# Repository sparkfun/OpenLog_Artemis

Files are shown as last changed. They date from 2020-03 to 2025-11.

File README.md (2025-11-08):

SparkFun OpenLog Artemis
===========================================================

<table class="table table-hover table-striped table-bordered">
  <tr align="center">
   <td></td>
   <td></td>
  </tr>
  <tr align="center">
    <td><a href="https://www.sparkfun.com/products/16832">SparkFun OpenLog Artemis (DEV-16832)</a></td>
    <td><a href="https://www.sparkfun.com/products/15846">SparkX OpenLog Artemis (SPX-15846)</a></td>
  </tr>
</table>

The OpenLog Artemis is an open source datalogger that comes preprogrammed to automatically log IMU, GPS, serial data, and various pressure, humidity, and distance sensors. All without writing a single line of code! OLA automatically detects, configures, and logs Qwiic sensors. OLA is designed for users who just need to capture a bunch of data to a CSV and get back to their larger project.

Included on every OpenLog Artemis is an IMU for built-in logging of triple axis accelerometer, gyro, and magnetometer. Whereas the original [9DOF Razor](https://www.sparkfun.com/products/14001) used the old MPU-9250, the OpenLog Artemis uses the latest [ICM-20948](https://www.sparkfun.com/products/15335) capable of nearly 1kHz logging of all 9 axis. We then took over a decade of experience with the original [OpenLog](https://www.sparkfun.com/products/13712) and took it much farther. Simply power up OpenLog Artemis and all incoming serial data is automatically recorded to a log file. Baud rates up to 921600bps are supported! Additionally, based on feedback from users we've added an onboard RTC so that all data can be time stamped.

OpenLog Artemis is highly configurable over an easy to use serial interface. Simply plug in a USB C cable and open a terminal at 115200kbps. The logging output is automatically streamed to both the terminal and the microSD. Pressing any key will open the configuration menu.

The OpenLog Artemis automatically scans, detects, configures, and logs various Qwiic sensors plugged into the board (no soldering required!). Currently, auto-detection is supported on the following Qwiic products:

* Any u-blox GPS Modules (Lat/Long, Altitude, Velocity, SIV, Time, Date) such as:
  * [ZED-F9P](https://www.sparkfun.com/products/15136) 1cm High Precision GPS
  * [NEO-M8P-2](https://www.sparkfun.com/products/15005) 2.5cm High Precision GPS
  * [SAM-M8Q](https://www.sparkfun.com/products/15210) 1.5m 72 Channel GPS
  * [ZOE-M8Q](https://www.sparkfun.com/products/15193) 1.5m Compact GPS
  * [NEO-M9N](https://www.sparkfun.com/products/15712) 1.5m GPS
  * [MAX-M10S](https://www.sparkfun.com/products/18037) 1.5m Ultra-Low Power GPS
* [MCP9600 Thermocouple Amplifier](https://www.sparkfun.com/products/16294)
* [NAU7802 Load Cell Amplifier](https://www.sparkfun.com/products/15242)
* [LPS25HB Barometric Pressure Sensor](https://www.sparkfun.com/products/14767)
* [BME280 Humidity and Barometric Pressure Sensor](https://www.sparkfun.com/products/15440)
* [MS5637 Barometric Pressure Sensor](https://www.sparkfun.com/products/14688)
* [MS5837 Depth / Pressure Sensor](https://www.sparkfun.com/products/17709)
* [SDP3X Differential Pressure Sensor](https://www.sparkfun.com/products/17874)
* [MS8607 Pressure Humidity Temperature Sensor](https://www.sparkfun.com/products/16298)
* [MPR0025PA MicroPressure Sensor](https://www.sparkfun.com/products/16476)
* [TMP102 Temperature Sensor] (https://www.sparkfun.com/products/13314)
* [TMP117 High Precision Temperature Sensor](https://www.sparkfun.com/products/15805)
* [AHT20 Humidity and Temperature Sensor](https://www.sparkfun.com/products/16618)
* [SHTC3 Humidity and Temperature Sensor](https://www.sparkfun.com/products/16467)
* [CCS811 Air Quality Sensor](https://www.sparkfun.com/products/14348)
* [SGP30 Air Quality Sensor](https://www.sparkfun.com/products/16531)
* [SGP40 Air Quality Sensor](https://www.sparkfun.com/products/17729)
* [SCD30 CO<sub>2</sub> and Air Quality Sensor](https://www.sparkfun.com/products/15112)
* [SN-GCJA5 Particle Sensor](https://www.sparkfun.com/products/17123)
* [VEML6075 UV Sensor](https://www.sparkfun.com/products/15089)
* [VCNL4040 Proximity Sensor](https://www.sparkfun.com/products/15177)
* [VL53L1X LIDAR Distance Sensor](https://www.sparkfun.com/products/14722)
* [ADS122C04 ADC PT100 Sensor](https://www.sparkfun.com/products/16770)
* [Qwiic Mux](https://www.sparkfun.com/products/16784) allowing for the chaining of up to 64 unique buses!
* [Pulse Oximeter and Heart Rate Sensor](https://www.sparkfun.com/products/15219) (requires exclusive use of pins 32 and 11)
* [ISM330DHCX IMU](https://www.sparkfun.com/products/19764)
* [MMC5983MA Magnetometer](https://www.sparkfun.com/products/19921)
* [KX134 Accelerometer](https://www.sparkfun.com/products/17589)
* [ADS1015 ADC](https://www.sparkfun.com/products/15334)
* [LPS28DFW Barometer](https://www.sparkfun.com/products/21221)
* [VEML7700 Ambient Light Sensor](https://www.sparkfun.com/products/18981)
* [TMP102 Temperature Sensor](https://www.sparkfun.com/sparkfun-digital-temperature-sensor-tmp102-qwiic.html)

Very low power logging is supported. OpenLog Artemis can be configured to take readings at 500 times a second, or as slow as 1 reading every 24 hours. You choose! When there is more than 2 seconds between readings OLA will automatically power down itself and the sensors on the bus resulting in a sleep current of approximately 18uA. This means a normal [2Ah battery](https://www.sparkfun.com/products/13855) will enable logging for more than 4,000 days! OpenLog Artemis has built-in LiPo charging set at 450mA/hr.

New features are constantly being added so we’ve released an easy to use firmware upgrade tool. No need to install Arduino or a bunch of libraries, simply open the [Artemis Firmware Upload GUI](https://github.com/sparkfun/Artemis-Firmware-Upload-GUI), load the latest OLA firmware, and add features to OpenLog Artemis as they come out! Full instructions are available in [UPGRADE.md](UPGRADE.md).

The OLA can be tailored to many different applications and we will be releasing custom versions of the firmware for those too:

* [Latest OLA firmware](https://github.com/sparkfun/OpenLog_Artemis/tree/main/Binaries)
* [Geophone Logger firmware](https://github.com/sparkfun/OpenLog_Artemis_Geophone_Logger) for logging seismic activity
* [GNSS Logger](https://github.com/sparkfun/OpenLog_Artemis_GNSS_Logger) for advanced data logging with the u-blox F9 and M9 GNSS modules including support for RAWX and RELPOSNED

Repository Contents
-------------------

* **/Binaries** - The binary files for the different versions of the OLA firmware.
* **/Firmware** - The main sketch that runs OpenLog Artemis as well as a variety of sketches to test various sensor interfaces and power saving states.
* **/Hardware** - Eagle files.

Documentation
--------------

* **[Hookup Guide](https://learn.sparkfun.com/tutorials/openlog-artemis-hookup-guide)** - hookup guide for the OLA.
* **[UPGRADE.md](./UPGRADE.md)** - contains full instructions on how to upgrade the firmware on the OLA using the [Artemis Firmware Upload GUI](https://github.com/sparkfun/Artemis-Firmware-Upload-GUI).
* **[CONTRIBUTING.md](./CONTRIBUTING.md)** - guidance on how to contribute to this library.
* **[Installing an Arduino Library Guide](https://learn.sparkfun.com/tutorials/installing-an-arduino-library)** - OLA includes a large number of libraries that will need to be installed before compiling will work.
* **[ADDING_SENSORS.md](./ADDING_SENSORS.md)** - contains _abbreviated_ instructions on how to add a new sensor to the OLA firmware. It's more of an aide-memoire really... Sorry about that.
* **[COMPILE_BINARY.md](./COMPILE_BINARY.md)** - contains instructions on how to compile the OLA firmware binary manually using Docker.
* **[SENSOR_UNITS.md](./SENSOR_UNITS.md)** - contains a summary of the units used for each sensor measurement.

Product Versions
----------------
* [DEV-19426](https://www.sparkfun.com/products/19426) - SparkFun OpenLog Artemis without IMU
* [DEV-16832](https://www.sparkfun.com/products/16832) - SparkFun OpenLog Artemis
* [SPX-15846](https://www.sparkfun.com/products/15846) - SparkX OpenLog Artemis

License Information
-------------------

This product is _**open source**_!

Various bits of the code have different licenses applied. Anything SparkFun wrote is beerware; if you see me (or any other SparkFun employee) at the local, and you've found our code helpful, please buy us a round!

Please use, reuse, and modify these files as you see fit. Please maintain attribution to SparkFun Electronics and release anything derivative under the same license.

Distributed as-is; no warranty is given.

- Your friends at SparkFun.

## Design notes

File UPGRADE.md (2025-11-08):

# OpenLog Artemis : Upgrade Instructions

The [**/Binaries**](./Binaries) folder contains the binary files for the different versions of the OLA firmware.

You can upload these to the OLA using the [Artemis Firmware Upload GUI](https://github.com/sparkfun/Artemis-Firmware-Upload-GUI) instead of the Arduino IDE.
Which is handy if you want to quickly update the firmware in the field, or are not familiar with the IDE.

The firmware is customized for the different versions of the OLA hardware. You will find versions for the **X04 SparkX (Black) OLA** and **V10 SparkFun (Red) OLA** plus any subsequent revisions. The filename tells you which hardware the firmware is for and what version it is:

* **OpenLog_Artemis-V10-v211.bin** - is the _stable_ version (2.11) for the **V10 SparkFun (Red) OLA**
* **OpenLog_Artemis-X04-v210.bin** - is the _stable_ version (2.10) for the **X04 SparkX (Black) OLA**

<table class="table table-hover table-striped table-bordered">
  <tr align="center">
   <td></td>
   <td></td>
  </tr>
  <tr align="center">
    <td><a href="https://www.sparkfun.com/products/16832">SparkFun OpenLog Artemis V10 (DEV-16832)</a></td>
    <td><a href="https://www.sparkfun.com/products/15846">SparkX OpenLog Artemis X04 (SPX-15846)</a></td>
  </tr>
</table>

* From time to time, you may also see versions with names like **OpenLog_Artemis-V10-v17_BETA.bin**
  * These are _beta_ versions containing new features and improvements which are still being tested and documented

* **OpenLog_Artemis-V10-v210-NoPowerLossProtection.bin** is a special build of v2.10 which has no power loss protection
  * With the normal firmware, the OLA goes into deep sleep if the power fails or is disconnected. This allows the Real Time Clock to keep running, but it does mean that a reset is required to wake the OLA again.
  * With the **NoPowerLossProtection** firmware, the code does not go into deep sleep when the power is lost, meaning that it will restart automatically as soon as power is reconnected.
  * This can be useful for embedded OLA systems which are hard to access. The downside is that the Real Time Clock setting is lost when the OLA restarts.

## To use:

* Download and extract the [OLA repo ZIP](https://github.com/sparkfun/OpenLog_Artemis/archive/main.zip)
* Download and extract the [AFU repo ZIP](https://github.com/sparkfun/Artemis-Firmware-Upload-GUI/archive/master.zip)
* Run the AFU artemis_firmware_uploader_gui executable for your platform
  * **/Windows** contains the Windows .exe
  * **/OSX** contains an executable for macOS X
  * **/Linux** contains an executable built on Ubuntu
  * **/Raspberry_Pi__Debian** contains an executable for Raspberry Pi 4 (Debian Buster)
* Select the OLA firmware file you'd like to upload from the OLA **/Binaries** folder (should end in *.bin*)
* Attach the OLA target board using USB
* Select the COM port (hit Refresh to refresh the list of USB devices)
* Press **Upload Firmware**

The GUI does take a few seconds to load and run. _**Don't Panic**_ if the GUI does not start right away.

- Your friends at SparkFun.

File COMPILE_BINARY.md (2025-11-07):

# OpenLog Artemis : How To Compile The OLA Firmware Binary

* [Using Docker](#using-docker)
* [How SparkFun does it](#how-sparkfun-does-it)
* [Using Arduino IDE (Deprecated)](#using-arduino-ide-deprecated)

## Using Docker

Installing the correct version of the Apollo3 core and of each required Arduino library, is tedious and error-prone. Especially on Windows. We've lost count of the number of times code compilation fails on our local machines, because we had the wrong core or library installed, or forgot to patch the core correctly... It is much easier to sandbox the firmware compilation using an environment like [Docker](https://www.docker.com/).

Docker is open-source. It is our new favourite thing!

Here is a step-by-step guide for how to install Docker and compile the firmware from scratch:

### Clone, fork or download the OpenLog_Artemis repo

To build the OpenLog_Artemis firmware, you obviously need a copy of the source code.

If you are familiar with Git and GitHub Desktop, you can clone the OpenLog_Artemis repo directly into GitHub Desktop:

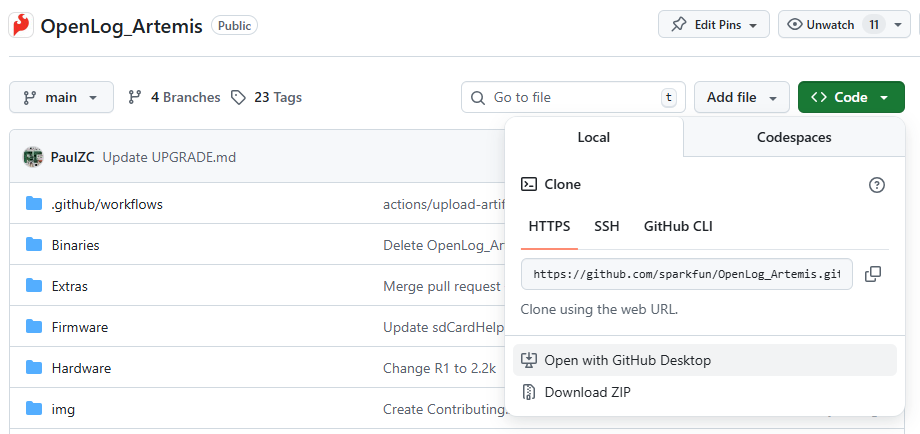
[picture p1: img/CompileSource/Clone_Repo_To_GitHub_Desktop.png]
Clone OpenLog_Artemis with GitHub Desktop


If you want to _contribute_ to OpenLog_Artemis, and already have a GitHub account, you can Fork the repo:

Fork OpenLog_Artemis

Clone your fork to your local machine, make changes, and send us a Pull Request. This is exactly what the SparkFun Team do when developing the code. Please use the `release_candidate` branch for any such changes. We are very unlikely to merge anything directly into `main`, unless it is (e.g.) docs corrections or improvements.

If you don't want to do either of those, you can simply Download a Zip copy of the repo instead. You will receive a complete copy as a Zip file. You can do this from the green **Code** button, or click on the icon below to download a copy of the main (released) branch:

Download ZIP (https://github.com/sparkfun/OpenLog_Artemis/archive/refs/heads/main.zip "Download ZIP (main branch)")

For the real Wild West experience, you can also download a copy of the `release_candidate` code branch. This is where the team is actively changing and testing the code, before it becomes a full release. The code there will _usually_ compile and will _usually_ work, but we don't guarantee it! We may be part way through implementing some breaking changes at the time of your download...

Download ZIP - release candidate (https://github.com/sparkfun/OpenLog_Artemis/archive/refs/heads/release_candidate.zip "Download ZIP (release_candidate branch)")

### Install Docker Desktop

* **(Optional)** Head to [Docker](https://www.docker.com/) and create an account. A free "Personal" account will cover occasional compilations of the firmware
* Download and install [Docker Desktop](https://docs.docker.com/get-started/get-docker/) - there are versions for Mac, Windows and Linux. You may need to restart to complete the installation.
* Run the Desktop
    * You don't _need_ to have an account and you don't _need_ to be signed in
    * You only need to be signed in if you want to store or share your Container on Docker Hub
    * If you don't sign in, Docker Desktop will run in Personal mode - which will cover local compilations of the firmware
* On Windows, you may see an error saying "**WSL needs updating** Your version of Windows Subsystem for Linux (WSL) is too old". If you do:
    * Open a command prompt
	* Type `wsl --update` to update WSL. At the time of writing, this installs Windows Subsystem for Linux 2.6.1
	* Restart the Docker Desktop
* If you are using Docker for the first time, the "What is a container?" and "How do I run a container?" demos are useful - _but not essential_
    * On Windows, you may want to give Docker Desktop permission to access to your Network, so it can access (e.g.) HTML ports
	* You can Stop the container and Delete it when you are done
* You may want to prevent Docker from running when your machine starts up
    * Uncheck "Start Docker Desktop when you sign in to your computer" in the Desktop settings

### Using Docker to create the firmware binary

* **Make sure you have Docker Desktop running.** You don't need to be signed in, but it needs to be running.
* Open a Command Prompt and `cd` into the OpenLog_Artemis folder
* Check you are in the right place. Type `dir` and hit enter. You should see the following files and folders:

```
    .gitattributes
    .github
    .gitignore
    ADDING_SENSORS.md
    Binaries
    CHANGELOG.md
    COMPILE_BINARY.md
    CONTRIBUTING.md
    Firmware
```

* `cd Firmware` and then `dir` again. You should see:

```
    compile_with_docker.bat
    Dockerfile
    Extras
    OpenLog_Artemis
    Test Sketches
```

* The file that does most of the work is the `Dockerfile`. You can run the Dockerfile manually to create a container and image, from which you can extract the firmware binary.

* But, if you're short on time, simply run `compile_with_docker.bat`. It does everything for you:

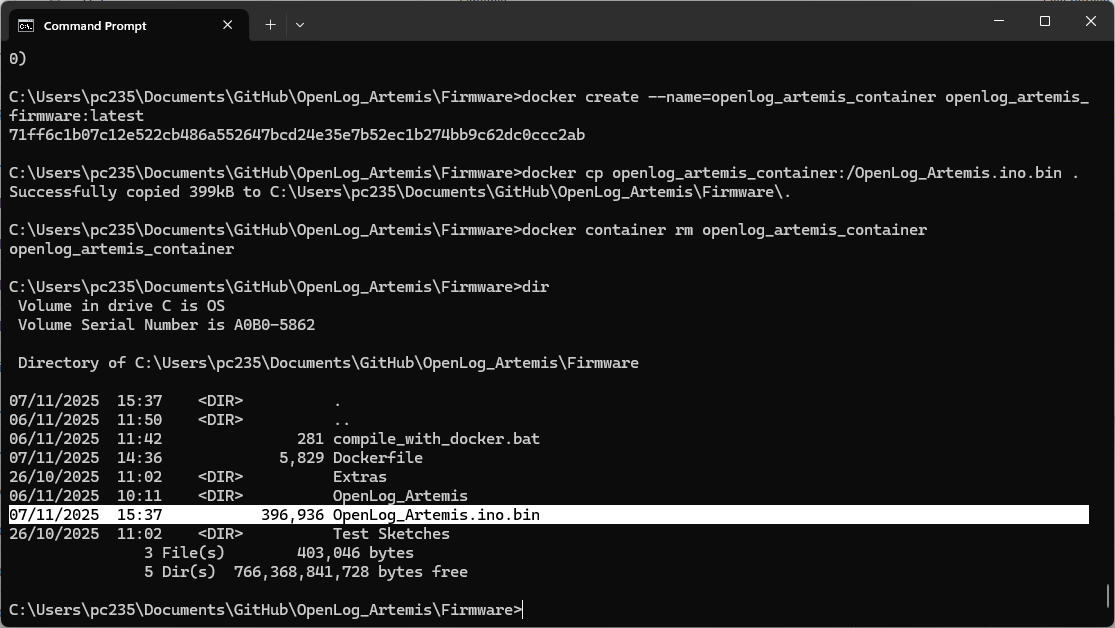
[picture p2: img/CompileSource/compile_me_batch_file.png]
Output of the compile batch file


* Hey presto! You have your newly compiled firmware binary!

You can then use the [SparkFun Artemis Uploader App](https://github.com/sparkfun/Artemis-Firmware-Upload-GUI) to upload the binary onto the Artemis. See [UPGRADE](./UPGRADE.md) for more instructions.

On Linux, you will need to convert `compile_with_docker.bat` into a shell script. Or run each of the four docker commands manually to: build the image, create the container, extract the firmware binary, and delete the container:

```
docker build -t openlog_artemis_firmware --progress=plain --no-cache-filter deployment .
docker create --name=openlog_artemis_container openlog_artemis_firmware:latest
docker cp openlog_artemis_container:/OpenLog_Artemis.ino.bin .
docker container rm openlog_artemis_container
```

## How SparkFun does it

At SparkFun, we use GitHub Actions and a Workflow to compile each release of the OpenLog Artemis firmware. We run the [compilation workflow](https://github.com/sparkfun/OpenLog_Artemis/blob/main/.github/workflows/build-for-release.yml) directly on GitHub. A virtual ubuntu machine installs the [Arduino CLI](https://github.com/arduino/arduino-cli/releases), installs the Apollo3 Arduino core, patches the core in a couple of places, installs all the required libraries at the required version, and generates the firmware binary for the Artemis. That binary is either uploaded as an Artifact (by [non-release-build](https://github.com/sparkfun/OpenLog_Artemis/blob/main/.github/workflows/non-release-build.yml)) or pushed to the [Binaries Folder](https://github.com/sparkfun/OpenLog_Artemis/tree/main/Binaries) (by [compilation workflow](https://github.com/sparkfun/OpenLog_Artemis/blob/main/.github/workflows/build-for-release.yml)).

You are welcome to clone or fork this repo and do the exact same thing yourself. But you may need a paid GitHub Pro account to run the GitHub Actions, especially if you keep your clone / fork private.

You can then download the firmware binary and use the [SparkFun Artemis Uploader App](https://github.com/sparkfun/Artemis-Firmware-Upload-GUI) to upload the binary onto the Artemis. See [UPGRADE](./UPGRADE.md) for more instructions.

## Using Arduino IDE (Deprecated)

We strongly suggest using Docker to compile the binary, it is **much** easier.

These are  _abbreviated_ instructions on how to compile the OLA firmware using Arduino IDE. It's more of an aide-memoire really... Sorry about that.

### Install Arduino IDE

Tested version: 1.8.19

(IDE version 2 has not been tested)

### Add Apollo3 To The Additional Boards Manager URLs

Open `File \ Preferences`

Click the File icon to the right of the `Additional Boards Manager URLs` text box

Add:

```
https://raw.githubusercontent.com/sparkfun/Arduino_Apollo3/main/package_sparkfun_apollo3_index.json
```

Click OK

Click OK

Close and re-open the IDE

### Install the Apollo3 Board Package

Open `Tools \ Board \ Boards Manager`

Enter `Apollo3` in the search box

Install the SparkFun Apollo3 Boards. Tested version: 2.2.1

### Install All The Required Libraries

Copy and paste the following into an empty sketch. Click on each link in turn to install the libraries via the Library Manager:

```
// SdFat by Bill Greiman (Tested version: 2.2.0): http://librarymanager/All#SdFat_exFAT
// http://librarymanager/All#SparkFun_ICM_20948_IMU
// http://librarymanager/All#SparkFun_I2C_Mux
// http://librarymanager/All#SparkFun_CCS811
// http://librarymanager/All#SparkFun_VL53L1X
// http://librarymanager/All#SparkFun_BME280
// http://librarymanager/All#SparkFun_LPS25HB
// http://librarymanager/All#SparkFun_VEML6075
// http://librarymanager/All#SparkFun_PHT_MS8607
// http://librarymanager/All#SparkFun_MCP9600
// http://librarymanager/All#SparkFun_SGP30
// http://librarymanager/All#SparkFun_VCNL4040
// http://librarymanager/All#SparkFun_MS5637
// http://librarymanager/All#SparkFun_TMP102
// http://librarymanager/All#SparkFun_TMP117
// http://librarymanager/All#SparkFun_u-blox_GNSS
// http://librarymanager/All#SparkFun_NAU7802
// http://librarymanager/All#SparkFun_SCD30
// http://librarymanager/All#Qwiic_Humidity_AHT20
// http://librarymanager/All#SparkFun_SHTC3
// http://librarymanager/All#SparkFun_ADS122C04
// http://librarymanager/All#SparkFun_MicroPressure
// http://librarymanager/All#SparkFun_Particle_Sensor_SN-GCJA5
// http://librarymanager/All#SparkFun_SGP40
// http://librarymanager/All#SparkFun_SDP3x
// http://librarymanager/All#SparkFun_Qwiic_Button_Switch
// http://librarymanager/All#SparkFun_Bio_Sensor
// http://librarymanager/All#SparkFun_6DoF_ISM330DHCX
// http://librarymanager/All#SparkFun_MMC5983MA
// http://librarymanager/All#SparkFun_ADS1015
// http://librarymanager/All#SparkFun_KX13X
// http://librarymanager/All#SparkFun_LPS28DFW_Arduino_Library
// http://librarymanager/All#SparkFun_VEML7700
// http://librarymanager/All#SparkFun_TMP102
```

#### Blue Robotics MS5837

Please manually download and install the latest version of the Blue Robotics MS5837 library from:

https://github.com/bluerobotics/BlueRobotics_MS5837_Library/archive/refs/heads/master.zip

(Version 1.1.1 - available through the Arduino Library Manager - is not the latest version...)

### Download the OLA Firmware Zip

Open this link in a web browser to download a complete Zip of the OLA firmware repo:

https://github.com/sparkfun/OpenLog_Artemis/archive/refs/heads/main.zip

Unzip it (Extract All files)

### Copy the OLA Source Code

Navigate to the `Firmware` sub-folder

Copy the entire `OpenLog_Artemis` folder from the Zip file into your `Arduino` folder. This contains the source code for the firmware. The result should be:

```
C:\Users\<Your_User>\Documents\Arduino\OpenLog_Artemis
```

### Patch the Apollo3 Core

The Apollo3 core (2.2.1) requires patching - using code kindly provided by Paulvha. For more information, open [this link](https://github.com/sparkfun/OpenLog_Artemis/issues/117#issuecomment-1085881142) in a web browser.

Navigate to the `Extras` folder in the Zip file. Copy the `UartPower3.zip` file. Paste it into the Apollo3 board package folder. On Windows machines, this is (usually):

```
C:\Users\<Your_User>\AppData\Local\Arduino15\packages\SparkFun\hardware\apollo3
```

On Linux machines, this is (usually):
```
/home/<Your_User>/.arduino15/packages/SparkFun/hardware/apollo3/
```

Unzip it (Extract All files)

**Close the Arduino IDE**

Follow the instructions contained in `uart_power_3.odt`

In summary: replace the following six files with the ones from `UartPower3.zip` :

```
C:\Users\<Your_User>\AppData\Local\Arduino15\packages\SparkFun\hardware\apollo3\2.2.1\cores\arduino\mbed-bridge\core-extend\HardwareSerial.h
C:\Users\<Your_User>\AppData\Local\Arduino15\packages\SparkFun\hardware\apollo3\2.2.1\cores\arduino\mbed-bridge\core-implement\HardwareSerial.cpp
C:\Users\<Your_User>\AppData\Local\Arduino15\packages\SparkFun\hardware\apollo3\2.2.1\cores\mbed-os\drivers\UnbufferedSerial.h
C:\Users\<Your_User>\AppData\Local\Arduino15\packages\SparkFun\hardware\apollo3\2.2.1\cores\mbed-os\targets\TARGET_Ambiq_Micro\TARGET_Apollo3\device\serial_api.c
C:\Users\<Your_User>\AppData\Local\Arduino15\packages\SparkFun\hardware\apollo3\2.2.1\variants\SFE_ARTEMIS_ATP\mbed\libmbed-os.a
C:\Users\<Your_User>\AppData\Local\Arduino15\packages\SparkFun\hardware\apollo3\2.2.1\libraries\SPI\src\SPI.cpp
```

### Enable ICM29048 DMP Support

Open the following file:

```
C:\Users\<Your_User>\Documents\Arduino\libraries\SparkFun_ICM-20948_ArduinoLibrary\src\util\ICM_20948_C.h
```

Uncomment the following line (29):

```
#define ICM_20948_USE_DMP // Uncomment this line to enable DMP support. You can of course use ICM_20948_USE_DMP as a compiler flag too
```

Save the updated file

### Compile / Upload the Code

Re-open the Arduino IDE

Open the main OLA Firmware .ino:

```
C:\Users\<Your_User>\Documents\Arduino\OpenLog_Artemis\OpenLog_Artemis.ino
```

Open the `Tools \ Board` menu. Select `SparkFun Apollo3 \ RedBoard Artemis ATP`

If you have the OLA connected via USB, you can click the `Upload` (Right-Arrow) icon to compile the code and upload it onto the OLA

(The compilation takes a long time. Go make a cup of tea...)

If you want to be able to swap between firmware versions more quickly, use the `Sketch \ Export compiled Binary` to create a binary which
you can upload with the `Artemis Firmware Upload GUI`. See [UPGRADE.md](./UPGRADE.md) for more details.

### Board Versions

If you are compiling for the Red (SparkFun) OLA: leave the hardware version defines as:

```
#define HARDWARE_VERSION_MAJOR 1
#define HARDWARE_VERSION_MINOR 0
```

If you have an original Black (SparkX) OLA - way to go! Change those lines to:

```
#define HARDWARE_VERSION_MAJOR 0
#define HARDWARE_VERSION_MINOR 4
```

### No Power Loss Protection

To disable the sleep-on-power-loss functionality, uncomment this line:

```
#define noPowerLossProtection // Uncomment this line to disable the sleep-on-power-loss functionality
```

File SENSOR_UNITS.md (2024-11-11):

# OpenLog Artemis : Sensor Units

This document summarizes the units used for each sensor measurement.

---
## Index

### Built-in Inertial Measurement Unit:

- [ICM-20948 IMU](#ICM-20948-IMU)

### Global Navigation Satellite System (GNSS) navigation data:

- [u-blox GNSS boards](#u-blox-GNSS-boards)

### Pressure, Altitude, Humidity and Temperature Data:

- [BME280 atmospheric sensor](#BME280-atmospheric-sensor)
- [LPS25HB absolute pressure sensor](#LPS25HB-absolute-pressure-sensor)
- [MS8607 PHT sensor](#MS8607-PHT-sensor)
- [MPR0025PA MicroPressure sensor](#MPR0025PA-MicroPressure-sensor)
- [MS5637 barometric pressure sensor](#MS5637-barometric-pressure-sensor)
- [MS5837 depth and pressure sensor](#MS5837-depth-pressure-sensor)
- [AHT20 humidity and temperature sensor](#AHT20-humidity-and-temperature-sensor)
- [SHTC3 humidity and temperature sensor](#SHTC3-humidity-and-temperature-sensor)
- [LPS28DFW absolute pressure sensor](#LPS28DFW-absolute-pressure-sensor)

### Differential Pressure:

- [SDP3X differential pressure sensor](#SDP3X-differential-pressure-sensor)

### Air Quality and Environmental Sensors:

- [CCS811 air quality sensor](#CCS811-air-quality-sensor)
- [VEML6075 UV light sensor](#VEML6075-UV-light-sensor)
- [SGP30 air quality and Volatile Organic Compound (VOC) sensor](#SGP30-air-quality-and-VOC-sensor)
- [SGP40 air quality (VOC index) sensor](#SGP40-air-quality-sensor)
- [SCD30 CO2 humidity and temperature sensor](#SCD30-CO2-humidity-and-temperature-sensor)
- [SN-GCJA5 Particle Sensor](#SN-GCJA5-Particle-Sensor)
- [VEML7700 Ambient light sensor](#VEML7700-Ambient-light-sensor)

### Distance:

- [VL53L1X laser Time of Flight (ToF) sensor](#VL53L1X-laser-ToF-sensor)
- [VCNL4040 proximity sensor](#VCNL4040-proximity-sensor)

### Precision Temperature Sensors:

- [MCP9600 thermocouple amplifier](#MCP9600-thermocouple-amplifier)
- [Qwiic PT100 ADS122C04 platinum resistance sensor](#Qwiic-PT100-ADS122C04-platinum-resistance-sensor)
- [TMP117 precision temperature sensor](#TMP117-precision-temperature-sensor)
- [TMP102 temperature sensor](#TMP102-temperature-sensor)

### Weight:

- [NAU7802 load cell sensor](#NAU7802-load-cell-sensor)

### ADC:

- [Qwiic PT100 ADS122C04 platinum resistance sensor](#Qwiic-PT100-ADS122C04-platinum-resistance-sensor)
- [ADS1015 ADC](#ADS1015-ADC)

### Biometric Sensors:

- [Pulse Oximeter and Heart Rate Sensor](#Pulse-Oximeter)

### Inertial Measurement Unit:

- [ISM330DHCX IMU](#ISM330DHCX-IMU)

### Magnetometer:

- [MMC5983MA magnetometer](#MMC5983MA-Magnetometer)

### Accelerometer:

- [KX134 accelerometer](#KX134-accelerometer)

---
## Sensor Units

---
## ICM-20948 IMU

| []() | | |
|---|---|---|
| Accelerometer | aX,aY,aZ | milli g |
| Gyro | gX,gY,gZ | Degrees per Second |
| Magnetometer | mX,mY,mZ | micro Tesla |
| Temperature | imu_degC | Degrees Centigrade |

---
## u-blox GNSS boards

| []() | | |
|---|---|---|
| Date | gps_Date | MM/DD/YYYY or DD/MM/YYYY |
| Time | gps_Time | HH:MM:SS.SSS |
| Lat & Lon | gps_Lat,gps_Long | Degrees<sup>-7</sup> |
| Altitude | gps_Alt | mm |
| Altitude MSL | gps_AltMSL | mm |
| SIV | gps_SIV | Count |
| Fix Type | gps_FixType | 0-5 |
| Carrier Soln. | gps_CarrierSolution | 0-2 |
| Ground Speed | gps_GroundSpeed | mm/s |
| Heading | gps_Heading | Degrees<sup>-5</sup> |
| PDOP | gps_pDOP | 10<sup>-2</sup> (dimensionless) |
| Time Of Week | gps_iTOW | ms |

Lat = Latitude  
Lon = Longitude  
MSL = Metres above Sea Level  
SIV = Satellites In View  
PDOP = Positional Dilution Of Precision  

Fix Type:  
0: No  
1: Dead Reckoning Only  
2: 2D  
3: 3D  
4: GNSS + Dead Reckoning  
5: Time Only

Carrier Solution:  
0: No  
1: Float Solution  
2: Fixed Solution  

---
## BME280 atmospheric sensor

| []() | | |
|---|---|---|
| Pressure | pressure_Pa | Pascals |
| Humidity | humidity_% | Percent |
| Altitude | altitude_m | m |
| Temperature | temp_degC | Degrees Centigrade |

---
## LPS25HB absolute pressure sensor

| []() | | |
|---|---|---|
| Pressure | pressure_hPa | hectoPascals |
| Temperature | temperature_degC | Degrees Centigrade |

---
## LPS28DFW absolute pressure sensor

| []() | | |
|---|---|---|
| Pressure | pressure_hPa | hectoPascals |
| Temperature | temperature_degC | Degrees Centigrade |

---
## MS8607 PHT sensor

| []() | | |
|---|---|---|
| Humidity | humidity_% | Percent |
| Pressure | hPa | hectoPascals |
| Temperature | degC | Degrees Centigrade |

---
## MPR0025PA MicroPressure sensor

| []() | | |
|---|---|---|
| Pressure (PSI) | PSI | Pounds per Square Inch |
| Pressure (Pa) | Pa | Pascals |
| Pressure (kPa) | kPa | kiloPascals |
| Pressure (torr) | torr | torr |
| Pressure (inHg) | inHg | inches of Mercury |
| Pressure (atm) | atm | atmospheres |
| Pressure (bar) | bar | barometric pressure  |

---
## MS5637 barometric pressure sensor

| []() | | |
|---|---|---|
| Pressure | pressure_hPa | hectoPascals |
| Temperature | temperature_degC | Degrees Centigrade |

---
## MS5837 depth pressure sensor

| []() | | |
|---|---|---|
| Pressure | mbar | millibar |
| Temperature | degC | Degrees Centigrade |
| Depth | depth_m | Metres |
| Altitude | alt_m | Metres |

---
## SDP3X differential pressure sensor

| []() | | |
|---|---|---|
| Pressure | Pa | Pascals |
| Temperature | degC | Degrees Centigrade |

---
## AHT20 humidity and temperature sensor

| []() | | |
|---|---|---|
| Humidity | humidity_% | Percent |
| Temperature | degC | Degrees Centigrade |

---
## SHTC3 humidity and temperature sensor

| []() | | |
|---|---|---|
| Humidity | humidity_% | Percent |
| Temperature | degC | Degrees Centigrade |

---
## CCS811 air quality sensor

| []() | | |
|---|---|---|
| VOC | tvoc_ppb | Parts Per Billion |
| CO<sub>2</sub> | co2_ppm | Parts Per Million |

VOC = Volatile Organic Compounds

---
## VEML6075 UV light sensor

| []() | | |
|---|---|---|
| UVA | uva |  |
| UVB | uvb |  |
| UV Index | uvIndex |  |

---
## VEML7700 Ambient light sensor

| []() | | |
|---|---|---|
| Lux | lux |  |

---
## SGP30 air quality and VOC sensor

| []() | | |
|---|---|---|
| Total VOC | tvoc_ppb | Parts Per Billion |
| CO<sub>2</sub> | co2_ppm | Parts Per Million |
| H<sub>2</sub> | H2 | none |
| Ethanol | ethanol | none |

---
## SGP40 air quality sensor

| []() | | |
|---|---|---|
| VOC Index | VOCindex | none |

---
## SCD30 CO2 humidity and temperature sensor

| []() | | |
|---|---|---|
| CO<sub>2</sub> | co2_ppm | Parts Per Million |
| Humidity | humidity_% | Percent |
| Temperature | degC | Degrees Centigrade |

---
## SN-GCJA5 Particle Sensor

| []() | | |
|---|---|---|
| Particle Density (1.0µm) | PM1_0 | µg/m<sup>3</sup> |
| Particle Density (2.5µm) | PM2_5 | µg/m<sup>3</sup> |
| Particle Density (10µm) | PM10 | µg/m<sup>3</sup> |
| Particle Count (0.5µm) | PC0_5 | Count |
| Particle Count (1.0µm) | PC1_0 | Count |
| Particle Count (2.5µm) | PC2_5 | Count |
| Particle Count (5.0µm) | PC5_0 | Count |
| Particle Count (7.5µm) | PC7_5 | Count |
| Particle Count (10µm) | PC10 | Count |
| Sensor Status | Sensors |  |
| Photodiode Status | PD | 0-3 |
| Laser Diode Status | LD | 0-3 |
| Fan Status | Fan | 0-3 |

Sensor status:
| []() | |
|---|---|
|  | PD LD Fan |
| 0 | 0  0  0 |
| 1 | Any 1, nor 2 & 3 |
| 2 | Any 2 |
| 3 | Any 3 nor 2 |

PD status:  
0: Normal status  
1: Normal status (within -80% against initial value), with S/W correction  
2: Abnormal (below -90% against initial value), loss of function  
3: Abnormal (below -80% against initial value), with S/W correction  

LD operational status:  
0: Normal status  
1: Normal status (within -70% against initial LOP), with S/W correction  
2: Abnormal (below -90% against initial LOP) or no LOP, loss of function  
3: Abnormal (below -70% against initial LOP), with S/W correction  

Fan operational status:  
0: Normal status  
1: Normal status (1,000rpm or more), with S/W correction  
2: In initial calibration  
3: Abnormal (below 1,000rpm), out of control

---
## VL53L1X laser ToF sensor

| []() | | |
|---|---|---|
| Distance | distance_mm | mm |
| Range Status | distance_rangeStatus(0=good) |  |
| Signal Rate | distance_signalRate |  |

---
## VCNL4040 proximity sensor

| []() | | |
|---|---|---|
| Proximity | prox(no unit) | none |
| Ambient Light | ambient_lux |  |

---
## MCP9600 thermocouple amplifier

| []() | | |
|---|---|---|
| Temperature | thermo_degC | Degrees Centigrade |
| Ambient Temperature | thermo_ambientDegC | Degrees Centigrade |

---
## Qwiic PT100 ADS122C04 platinum resistance sensor

| []() | | |
|---|---|---|
| Temperature (C) | degC | Degrees Centigrade |
| Temperature (F) | degF | Degrees Fahrenheit |
| Temperature Internal | degC | Degrees Centigrade |
| Raw Voltage | V*2.048/2^23 | Volts * 2.048 / 2<sup>23</sup> |

---
## TMP102 temperature sensor

| []() | | |
|---|---|---|
| Temperature | degC | Degrees Centigrade |

---
## TMP117 precision temperature sensor

| []() | | |
|---|---|---|
| Temperature | degC | Degrees Centigrade |

---
## NAU7802 load cell sensor

| []() | | |
|---|---|---|
| Weight | weight(no unit) | none |

---
## Pulse Oximeter

| []() | | |
|---|---|---|
| bpm | heart rate | beats per minute |
| conf% | confidence | percent |
| O2% | oxygen level | percent |
| stat | sensor status | 0 to 3 |
| eStat | extended status | -6 to 1 |
| O2R | oxygen SpO2 R value | |

Sensor status:  
0: No object detected  
1: Object detected  
2: Object other than finger detected  
3: Finger detected  

Extended status:  
0: Success  
+1: Not ready  
-1: Object detected  
-2: Excessive sensor device motion  
-3: No object detected  
-4: Pressing too hard  
-5: Object other than finger detected  
-6: Excessive finger motion  

---
## ISM330DHCX IMU

| []() | | |
|---|---|---|
| Accelerometer | aX,aY,aZ | milli g |
| Gyro | gX,gY,gZ | milli Degrees per Second |

---
## MMC5983MA Magnetometer

| []() | | |
|---|---|---|
| Magnetometer | mX,mY,mZ | Gauss |
| Temperature | degC | Degrees Centigrade |

---
## KX134 Accelerometer

| []() | | |
|---|---|---|
| Accelerometer | aX,aY,aZ | g |

---
## ADS1015 ADC

| []() | | |
|---|---|---|
| Voltage | A0mV,A1mV,A2mV,A3mV,A0A1mV,A0A3mV,A1A3mV,A2A3mV | milliVolts |

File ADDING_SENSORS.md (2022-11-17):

# OpenLog Artemis : How To Add A New Sensor

These are  _abbreviated_ instructions on how to add a new sensor to the OLA firmware. It's more of an aide-memoire really... Sorry about that.

Caveat: this is _currently_ how a new sensor is added, for version v1.n of the OLA firmware using v1.2.n of the Apollo3 boards (the OLA code is compiled using the SparkFun RedBoard Artemis ATP (All The Pins) board). This will change, dramatically, when we upgrade to v2 of Apollo3 and integrate BLE support.

## Use The Release Candidate Branch

First up, please target any commits at the _**release_candidate**_ branch, so they can be tested before being merged into the _main_ branch.

- https://github.com/sparkfun/OpenLog_Artemis/tree/release_candidate

## OpenLog_Artemis.ino

- [Add the new sensor to the comments at the start of the file](https://github.com/sparkfun/OpenLog_Artemis/commit/2a26acd279fa93cfe84f1bc518c0e7a041b3bc44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)

- [#include the library .h file remembering to include the library manager helper link](https://github.com/sparkfun/OpenLog_Artemis/commit/2a26acd279fa93cfe84f1bc518c0e7a041b3bc44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)

## Sensors.ino

### gatherDeviceValues

- This is where the sensor readings are actually read. [Add a case for the new sensor](https://github.com/sparkfun/OpenLog_Artemis/commit/2a26acd279fa93cfe84f1bc518c0e7a041b3bc44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)

### printHelperText

- [Add helper text for the sensor readings](https://github.com/sparkfun/OpenLog_Artemis/commit/2a26acd279fa93cfe84f1bc518c0e7a041b3bc44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)

## autoDetect.ino

### addDevice

- This code is called to add the discovered device to the linked list of active devices. [Add a case for the new sensor](https://github.com/sparkfun/OpenLog_Artemis/commit/2a26acd279fa93cfe84f1bc518c0e7a041b3bc44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). The class name comes from the library. The config struct is defined in settings.h.

### beginQwiicDevices

- This is the code that is called to start (begin) the device. [Add a case for the new sensor](https://github.com/sparkfun/OpenLog_Artemis/commit/2a26acd279fa93cfe84f1bc518c0e7a041b3bc44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). Update _qwiicPowerOnDelayMillis_ if this device needs extra time to get its act together on power-up.

### configureDevice

- If the sensor needs to be configured before use, that gets done here. [Add a case for the new sensor, even if it doesn't need to be configured.](https://github.com/sparkfun/OpenLog_Artemis/commit/2a26acd279fa93cfe84f1bc518c0e7a041b3bc44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)

### getConfigFunctionPtr

- [Add a pointer to the sensor menu function (defined in menuAttachedDevices.ino)](https://github.com/sparkfun/OpenLog_Artemis/commit/2a26acd279fa93cfe84f1bc518c0e7a041b3bc44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)

### swap

- [Add the device's I2C address(es) here - just for reference (we don't use these #defines any longer)](https://github.com/sparkfun/OpenLog_Artemis/commit/2a26acd279fa93cfe84f1bc518c0e7a041b3bc44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)

### testDevice

- This is the code used to detect the sensor. [Add a case for the new sensor](https://github.com/sparkfun/OpenLog_Artemis/commit/2a26acd279fa93cfe84f1bc518c0e7a041b3bc44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). Provide some indication of how robust the detection is. Confidence would be high if the .begin writes and reads unique data to/from the sensor. Confidence is low if .begin only uses the standard _isConnected_ I2C address test.

### getDeviceName

- This is where the sensor name is defined as text. [Add a case for the new sensor](https://github.com/sparkfun/OpenLog_Artemis/commit/2a26acd279fa93cfe84f1bc518c0e7a041b3bc44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). Keep it brief and follow the same format as the other sensors: usually _TYPE_ (PRESSURE, TEMPERATURE etc.) followed by the abbreviated manufacturer's part number

## menuAttachedDevices.ino

### menuAttachedDevices

- This is the code which lists all the attached devices as a menu. [Add a case for the new sensor](https://github.com/sparkfun/OpenLog_Artemis/commit/2a26acd279fa93cfe84f1bc518c0e7a041b3bc44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)

### menuConfigure_

- [Add a new menuConfigure_ for the new sensor](https://github.com/sparkfun/OpenLog_Artemis/commit/2a26acd279fa93cfe84f1bc518c0e7a041b3bc44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)
- Boolean settings are simple to toggle. [Make them exclusive if you need to](https://github.com/sparkfun/OpenLog_Artemis/commit/2a26acd279fa93cfe84f1bc518c0e7a041b3bc44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)
- _int64_t_ values are requested using _getNumber_ (defined in support.ino)
- _double_ values are requested using _getDouble_ (defined in support.ino)

## nvm.ino

### recordDeviceSettingsToFile

- This function gets called to write the device settings to file. [Add a case for the new sensor](https://github.com/sparkfun/OpenLog_Artemis/commit/2a26acd279fa93cfe84f1bc518c0e7a041b3bc44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). Include all of the sensor settings.

### parseDeviceLine

- This function gets called when the device settings are read back from file. [Add a case for the new sensor](https://github.com/sparkfun/OpenLog_Artemis/commit/2a26acd279fa93cfe84f1bc518c0e7a041b3bc44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)

## settings.h

### enum

- [Add the device to the enumerated sensors](https://github.com/sparkfun/OpenLog_Artemis/commit/2a26acd279fa93cfe84f1bc518c0e7a041b3bc44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). Insert the new one above _DEVICE_TOTAL_DEVICES_

### settings struct

- [Add a settings struct for the new sensor](https://github.com/sparkfun/OpenLog_Artemis/commit/2a26acd279fa93cfe84f1bc518c0e7a041b3bc44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). Include both _log_ and _powerOnDelayMillis_

## README.md

- Add the new sensor to the list in [README.md](./README.md). Include a link to the product page
- Update the OLA product page on Sparkle - add the new sensor to the list

## CHANGELOG.md

- Update [CHANGELOG.md](./CHANGELOG.md). Start a new version if you need to. Add the new sensor to the change notes

## SENSOR_UNITS.md

- Update [SENSOR_UNITS.md](./SENSOR_UNITS.md). Add the new sensor to the appropriate section at the start of the document. Add a unit table for the sensor at the end of the document.

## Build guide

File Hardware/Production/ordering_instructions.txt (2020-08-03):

panel size, 107x187mm
PCB thickness, 1.6mm
number of layers, 4
soldermask color, Red
silkscreen color, White
oz copper, 1oz
finish, ENIG
stencils, top+bottom
pcs per panel, 15
min trace width, 0.1524mm / 0.0060in
min drill size, 0.3048mm / 0.0120in
filename to layer stackup 1/2/3/4: GTL, GL2, GL3, GBL

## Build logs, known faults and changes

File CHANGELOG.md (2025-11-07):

Change Log
======================

v2.11:
---------

* Adds support for LPS28DFW Mode 2 (4060 hPa) - thank you @thebrownhobbit-commits #221
* Updates the Dockerfile to include the required library versions
* Adds `compile_with_docker.bat` to automatically generate the firmware binary - see [COMPILE_BINARY.md](./COMPILE_BINARY.md) for details
* Updates the workflows to use the Dockerfile to generate the firmware binary

v2.10:
---------

* Restructures the serial logging code in loop()
* Where possible, residual serial data is written to file before closing
* Allows all log files to be deleted via `RM *` or `DEL *` in the SD menu

v2.9:
---------

* Adds support for the TMP102 temperature sensor - thank you @summetj #200

v2.8:
---------

* Corrects the serial token timestamp printing - resolves #192
* The charsReceived debug print ("Total chars received: ") now excludes the length of the timestamps
* Consistent use of File32/ExFile/FsFile/File. Don't use SdFile for temporary files
* Corrects the KX134 32G menu option - resolves #197

v2.7:
---------

* Corrects the crash on startup when logging serial data - resolves #182

v2.6:
---------

* Add workflow actions to automatically compile the firmware binaries
* Add support for the LPS28DFW - thank you @gauteh #179 , resolves #177
* Adds a Docker file for compiling the firmware - thank you @gauteh #179
* Only disable I2C SDA and SCL during sleep when I2C bus is being powered down - thank you @whipple63 #167 , resolves #155
* Add calibrationConcentration support for the SCD30 - thank you @hotstick #181
* Add limited support for the VEML7700 light sensor - resolves #184
* Adds much improved support for the NAU7802 scale
  * Negative weights can now be logged - resolves #176
  * The calibration mode can now be set to: None, Internal (default), or External
  * The sample rate, gain and LDO voltage can be selected via the menu
  * The scale can be zero'd and calibrated separately - there are separate menu entries for zero, calibrate and calibration weight entry
* Corrects a major bug which prevented mutiple NAU7802, SCD30 or u-blox GNSS from being configured correctly when connected through a mux
* Corrects a minor bug - corrected array size checking for olaftoa

v2.5:
---------

* Add Tony Whipple's PR #146 - thank you @whipple63
* Add support for the ISM330DHCX, MMC5983MA, KX134 and ADS1015
* Resolve issue #87

v2.4:
---------

* Add noPowerLossProtection to the main branch
* Add changes by KDB: If we are streaming to Serial, start the stream with a Mime Type marker, followed by CR
* Add debug option to only open the menu using a printable character: based on https://github.com/sparkfun/OpenLog_Artemis/pull/125

v2.3:
---------

* Resolve https://forum.sparkfun.com/viewtopic.php?f=171&t=58109

v2.2:
---------

* Use Apollo3 v2.2.1 with changes by paulvha to fix Issue 117 (Thank you Paul!)
  * https://github.com/sparkfun/OpenLog_Artemis/issues/117#issuecomment-1085881142
* Also includes Paul's SPI.end fix
  * https://github.com/sparkfun/Arduino_Apollo3/issues/442

In libraries/SPI/src/SPI.cpp change ```end()``` to:

```
    void arduino::MbedSPI::end() {
        if (dev) {
            delete dev;
            dev = NULL;
        }
    }   
```   

* Use SdFat v2.1.2
* Compensate for missing / not-populated IMU
* Add support for yyyy/mm/dd and ISO 8601 date style (Issue 118)
  * Add support for fractional time zone offsets

v2.1
---------

v2.1 is a 'mini' release:

* The compiled binaries for v2.1 are based on v2.2.0 of the Apollo3 core
* Corrects issue [109](https://github.com/sparkfun/OpenLog_Artemis/issues/109)
* Corrects issue [104](https://github.com/sparkfun/OpenLog_Artemis/issues/104)

v2.0
---------

* Upgrades the OLA firmware to use v2.1.0 of the Apollo3 core
  * Please note: v2.1.1 of Apollo3 contains a feature which makes communication with the u-blox GNSS modules problematic. Please use v2.1.0 until a fix is available
  * If you are compiling the code yourself, please set the board to RedBoard Artemis ATP

v1.11
---------

* Adds support for the ICM-20948 Digital Motion Processor [47](https://github.com/sparkfun/OpenLog_Artemis/issues/47)
  * The OLA's orientation can be logged as a 6-axis or 9-axis Quaternion. Note: only Quat9 provides absolute orientation - using the magnetometer. Quat6 uses the accel and gyro only
  * Open Menu 3 and select option 12 to enable the DMP
* Adds support for exFAT microSD cards [34](https://github.com/sparkfun/OpenLog_Artemis/issues/34)
  * Based on v2.0.6 of Bill Greiman's SdFat library
* Adds a minimum awake time, making it easier to open the Serial menu when the OLA is sleeping between measurements [83](https://github.com/sparkfun/OpenLog_Artemis/issues/83)
* Adds support for the Bio Sensor Hub Pulse Oximeter and Heart Rate Sensor [81](https://github.com/sparkfun/OpenLog_Artemis/issues/81)
  * Requires exclusive use of pins 32 and 11
  * Open Menu 6 (Detect / Configure Attached Devices) to enable Oximeter detection
* Adds stand-alone examples for:
  * ICM-20948 DMP (orientation in Quat6 and Quat9)
  * GNSS RAWX logging
  * GNSS TIM-TM2 logging
* Does not add support for the Qwiic Button [81](https://github.com/sparkfun/OpenLog_Artemis/issues/81)
  * We tried to add support for the QB, but it uses I2C clock stretching and causes all kinds of badness with the Artemis

v1.10
---------

* Improved support for the MS5837
* Adds IMU DMP examples
* Corrects support for the SDP31
* Updates the low-power code as per [78](https://github.com/sparkfun/OpenLog_Artemis/issues/78)
* Corrects wakeFromSleep when using the Tx pin for serial output [79](https://github.com/sparkfun/OpenLog_Artemis/issues/79)

v1.9
---------

* Allows the TX and RX pins to be used for the serial terminal / console
  * This is very cool as it means you can now connect the OLA to your choice of (e.g.) Bluetooth or radio modem and access your data over that instead of USB
  * File transfer using ZMODEM is possible on both USB and TX/RX
* Added support for the SGP40 air quality sensor - which provides a robust VOC Index for indoor air quality
* Added support for the SDP3X differential pressure sensor - opening up possibilities for air flow and air speed measurement
* Added support for the MS5837 depth / pressure sensor - as used in the BlueRobotics Bar02
* Corrects an issue which was corrupting data when using multiple MS8607s [62](https://github.com/sparkfun/OpenLog_Artemis/issues/62)
* Adds serial logging timestamps with a configurable timestamp token [63](https://github.com/sparkfun/OpenLog_Artemis/issues/63) - thank you @DennisMelamed
* Adds a _slow logging_ feature to extend battery life
  * Pin11 can be used to enter slow logging mode [60](https://github.com/sparkfun/OpenLog_Artemis/issues/60) - thank you @ryanneve
  * Slow logging can be entered once per day, with configurable start and end time [46](https://github.com/sparkfun/OpenLog_Artemis/issues/46)
* Adds improved support for the SCD30 [67](https://github.com/sparkfun/OpenLog_Artemis/issues/67) - thank you @paulvha
* Corrects a bug in logMicroseconds [57](https://github.com/sparkfun/OpenLog_Artemis/issues/57)

v1.8
---------

* Added a fix to make sure the MS8607 is detected correctly [54](https://github.com/sparkfun/OpenLog_Artemis/issues/54)
* Added logMicroseconds [49](https://github.com/sparkfun/OpenLog_Artemis/issues/49)
* Added an option to use autoPVT when logging GNSS data [50](https://github.com/sparkfun/OpenLog_Artemis/issues/50)

v1.7
---------

* Corrected the readVin after sleep bug [39](https://github.com/sparkfun/OpenLog_Artemis/issues/39)
* Corrected detection of the MCP9600 (Qwiic Thermocouple) [41](https://github.com/sparkfun/OpenLog_Artemis/issues/41)
* Added support for the MPR MicroPressure Sensor [35](https://github.com/sparkfun/OpenLog_Artemis/issues/35)
* Added support for the SN-GCJA5 Particle Sensor
* IMU full scale and Digital Low Pass Filter settings can now be configured via Menu 3 [42](https://github.com/sparkfun/OpenLog_Artemis/issues/42)

v1.6
---------

* The sensor readings can now be streamed to the serial TX pin (in addition to being displayed in the terminal and logged to SD card)
  * You can enable this feature using Menu 4 (Configure Serial Logging) Option 2
  * The baud rate is set using Menu 4 Option 4 (the serial pin and the terminal have separate baud rates)
  * When serial output is enabled, analog logging on pin 12 is disabled
  * This resolves issue [#32](https://github.com/sparkfun/OpenLog_Artemis/issues/32)
* A new SD Card File Transfer menu has been added
  * You can access this by selecting Menu s from the Main Menu
  * You can now:
    * List the files on the SD card using ls or dir
    * Delete a single file using del filename or rm filename
    * Type the contents of a single file to the terminal using type filename or cat filename
    * Copy or transfer a single file to the serial TX pin using ss filename
    * Transfer a single file or all files to the terminal using the ZMODEM protocol
      * Tera Term supports ZMODEM. Select File\Transfer\ZMODEM\Receive from the pull-down menus
      * To transfer a single file: sz filename
      * To transfer all files: sz *
  * The ZMODEM start delay can be changed using Menu 4 Option 3
  * The code is based on ecm-bitflipper's Arduino_ZModem
  * This resolves issue [#33](https://github.com/sparkfun/OpenLog_Artemis/issues/33)
* The serial and data log files are now timestamped with create and access timestamps
  * By default, the access timestamp is only set when the file is closed
  * You can enable frequent file access timestamps using Menu 1 Option 11
    * Frequent timestamping requires additional SD card writes and may cause problems when logging data at high rates
* An additional delay allows the IMU to start cleanly after being powered down during sleep
  * This resolves issue [#18](https://github.com/sparkfun/OpenLog_Artemis/issues/18)
* The measurement count no longer resets when the menus are opened
  * This resolves issue [#31](https://github.com/sparkfun/OpenLog_Artemis/issues/31)
* Low battery detection is now supported on the v10 (red) version of the OLA
  * Automatic powerDown on low battery can be enabled using Menu 7 Option 4
  * The low battery threshold voltage can be set using Menu 7 Option 5
* The code now defines a power-on delay for each sensor type
  * When waking from sleep, the code will now wait until attempting to begin 'slow' sensors like the SCD30 or a u-blox module
  * You can extend/override the power-on delay by selecting Menu 6, then Configure Qwiic Settings , then Option 3
  * You can extend the delay to a maximum of 60 seconds, which is more than enough time to allow a u-blox module to establish a fix before the data is read
  * This resolves issue [#5](https://github.com/sparkfun/OpenLog_Artemis/issues/5)
* Instead of logging data at regular time intervals, data logging can now also be triggered via Pin 11
  * This new feature is enabled via Menu 1 Option 12
  * Data logging can be triggered on falling or rising edges (Menu 1 Option 13)
  * When triggering is enabled, the normal log rate settings are ignored
  * Pin 11 generates an interrupt rather than being polled, allowing fast events to trigger logging
  * This resolves issue [#36](https://github.com/sparkfun/OpenLog_Artemis/issues/36)
* The IMU temperature reading has been corrected
  * This resolves issue [#28](https://github.com/sparkfun/OpenLog_Artemis/issues/28)

v1.5
---------

* Added the CIPO pull-up
* Improved mux scanning
* Added productionTest
* Reduced the maximum serial logging baud rate to 500000
* Reduced RAM footprint - most Serial.prints now use flash helper text
* Qwiic power-up delay improvements
* Released for V10 production

v1.4
---------

* Added support for the ADS122C04
* Investigated the RTC-reset issue [#13](https://github.com/sparkfun/OpenLog_Artemis/issues/13)
* Added the _stop logging_ feature on Pin 32
* Allow the user to select the Qwiic pull-up resistance
* Qwiic pull-ups are disabled when communicating with a u-blox module
* Regressed to SdFat (FAT32) - we found that SdFat-Beta caused very occasional logging problems
* Added the VIN correction factor

v1.3
---------

* Add 100ms startup time to Qwiic auto-detection. Lack of SD card was causing some sensors to be pinged before they had enough time to power on and ack.
* Add 2000ms startup time to SCD30. This sensor requires significant time to boot. See issue [#4](https://github.com/sparkfun/OpenLog_Artemis/issues/4).

v1.2
---------

* Fix bug in findNextAvailableLog() that was causing logging to fail during after a sleep/wakeup and sometimes corrupt the microSD card.
* Fix calculation of actualHz when power sleeping >2s.
* Log sensor configurations to config file. This allows users to configure an OpenLog Artemis and then deploy that configuration to multiple units as needed.

v1.1
---------

* Add support for exFat microSD cards. Tested up to 512GB. Smaller FAT16 and FAT32 formatted cards are still supported.
* Add support for MS8607 PHT sensor
* Add ability to turn on/off power on Qwiic bus when time between sensor readings is > 2s. By default the bus powers down to save power but there may be instances where user wants to keep sensors powered up and running between reads. This can be accessed via the Attached Devices menu.
* Add ability to limit I2C bus speed. Most devices operate at 400kHz I2C. Some (MCP9600) are automatically limited by OLA to 100kHz. There may be instances, because of bus length or other, where the user may want to artifically limit the bus speed. This can be access via the Attached Devices menu.

v1.0
---------
Initial release.

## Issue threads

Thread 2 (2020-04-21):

OpenLog Artemis - Data Logging Issues

adamgarbo, 2020-04-21:
### Subject of the issue
I've encountered a number of issues when starting to work with the OpenLog Artemis and setting the log rate to longer values (i.e. 5-10 seconds). The two main issues are:
1. OpenLog Artemis does not log data beyond the first observation.
2. OpenLog Artemis does not power down after 2 seconds.

### Your workbench
* What development board or microcontroller are you using?
    * OpenLog Artemis
* What version of hardware or breakout board are you using?
    * Firmware v1.1
* How is OpenLog Artemis wired to your sensor(s)?
    * Directly via USB-C
* How is everything being powered?
    * USB-C or 3.7V LiPo battery
* Are there any additional details that may help us help you?
    * See below for raw data outputs.

### Steps to reproduce
* Connect to OpenLog Artemis over Serial and in the menu change "Set Log Rate in seconds between readings: " to 5 seconds (0.2 Hz) or 10 seconds (0.1 Hz)

### Expected behaviour
* OpenLog Artemis should log data every 5-10 seconds and provide a visual indication of samples being recorded via the STAT LED.
* OpenLog Artemis should power down after 2 seconds of inactivity and have a sleep current of ~250 uA.

### Actual behaviour
* Only the first data sample is recorded to the microSD card. All subsequent data is not recorded.
* Quiescent current does not decrease after 2 s of inactivity and remains at ~1 mA (SD card dependent).
* When powering the OpenLog Artemis with either a 3.7V LiPo battery or 5V from USB-C, there is brief LED activity after the 45 second timeout but the STAT LED does not blink beyond that.

### Raw data
Contents of dataLog00001.txt

```
SD card online
Data logging online
Serial logging online
IMU online
No sensors detected
rtcDate,rtcTime,aX,aY,aZ,gX,gY,gZ,mX,mY,mZ,imu_degC,output_Hz,
04/21/2020,09:08:15.28,-9.77,-19.04,-1000.00,-1.92,2.16,-1.11,-10.05,87.45,12.90,26.13,333.33,
```

Output of Serial Monitor:
```
09:07:26.486 ->
09:07:26.660 -> Config file read complete
09:07:26.730 -> Artemis OpenLog v1.10
09:07:26.802 -> Created log file: dataLog00001.TXT
09:07:26.838 -> Created log file: serialLog00002.TXT
09:07:26.940 -> SD card online
09:07:26.940 -> Data logging online
09:07:26.940 -> Serial logging online
09:07:26.940 -> IMU online
09:07:26.977 -> No sensors detected
09:07:26.977 ->
09:07:26.977 -> Menu: Main Menu
09:07:26.977 -> 1) Configure Terminal Output
09:07:26.977 -> 2) Configure Time Stamp
09:07:26.977 -> 3) Configure IMU Logging
09:07:26.977 -> 4) Configure Serial Logging
09:07:26.977 -> 5) Configure Analog Pin Logging
09:07:26.977 -> 6) Detect / Configure Attached Devices
09:07:26.977 -> r) Reset all settings to default
09:07:26.977 -> x) Return to logging
09:07:39.206 ->
...
09:07:55.279 -> rtcDate,rtcTime,aX,aY,aZ,gX,gY,gZ,mX,mY,mZ,imu_degC,output_Hz,
09:07:55.279 -> 04/21/2020,09:08:15.28,-9.77,-19.04,-1000.00,-1.92,2.16,-1.11,-10.05,87.45,12.90,26.13,333.33,
09:08:00.608 -> 04/21/2020,09:08:20.62,-5.37,-30.76,-1016.60,-0.98,6.11,2.44,-11.10,87.60,14.70,25.07,666.67,
09:08:00.642 -> ⸮04/21/2020,09:08:25.95,-8.79,-18.07,-1020.51,-0.83,5.68,2.47,-12.15,86.70,12.90,25.31,1000.00,
09:08:05.958 -> ⸮04/21/2020,09:08:31.29,-4.39,-32.23,-1024.41,-1.15,-1.73,-6.09,-12.75,85.35,14.25,25.27,1333.33,
09:08:11.300 -> ⸮04/21/2020,09:08:36.63,-10.74,-25.88,-1008.30,-1.04,7.12,2.26,-11.10,85.80,12.75,25.22,1666.67,
09:08:16.644 -> ⸮04/21/2020,09:08:41.97,5.37,-24.41,-1013.67,-0.70,6.39,4.02,-10.20,85.05,7.05,24.98,2000.00,
09:08:22.001 -> ⸮04/21/2020,09:08:47.31,-5.86,-18.07,-1007.81,1.01,5.07,1.83,-9.90,86.10,7.05,25.12,2333.33,
09:08:27.334 -> ⸮04/21/2020,09:08:52.65,-11.72,-11.72,-1012.21,-1.65,3.35,3.34,-10.20,83.10,5.85,25.07,2666.67,
09:08:32.675 -> ⸮04/21/2020,09:08:57.98,-0.49,-25.88,-1001.46,0.75,-1.63,-3.56,-9.45,85.05,5.10,24.79,3000.00,
09:08:37.996 -> ⸮04/21/2020,09:09:03.32,-19.04,-14.16,-1006.84,-0.83,2.89,4.13,-9.45,82.05,4.35,25.22,3333.33,
09:08:43.352 -> ⸮04/21/2020,09:09:08.66,-26.86,-26.37,-1020.02,0.51,2.17,2.48,-9.45,83.55,2.40,24.88,3666.67,
09:08:48.674 -> ⸮04/21/2020,09:09:14.00,5.37,-34.18,-1010.25,1.62,3.50,1.60,-9.60,83.25,5.25,24.93,4000.00,
09:08:54.022 -> ⸮04/21/2020,09:09:19.34,-17.58,-26.37,-1015.14,0.21,2.69,1.62,-8.85,82.20,1.80,25.07,4333.33,
09:08:59.358 -> ⸮04/21/2020,09:09:24.68,-13.67,-36.13,-1007.32,-1.18,3.15,1.93,-9.00,84.60,5.10,24.93,4666.67,
09:09:04.678 -> ⸮04/21/2020,09:09:30.02,-12.21,-19.53,-1026.37,-1.53,2.41,1.16,-8.25,84.30,5.10,24.93,5000.00,
09:09:10.060 -> ⸮04/21/2020,09:09:35.37,-21.48,-21.00,-1017.09,-1.63,5.92,2.94,-9.90,82.80,5.10,25.22,5333.33,
09:09:15.393 -> ⸮04/21/2020,09:09:40.72,5.86,-17.58,-1009.28,-2.31,2.76,2.45,-8.85,83.70,4.95,24.93,5666.67,
09:09:20.743 -> ⸮04/21/2020,09:09:46.05,-16.11,-25.39,-1017.58,0.52,6.27,5.03,-10.05,84.45,4.20,24.98,6000.00,
09:09:26.080 -> ⸮04/21/2020,09:09:51.39,-5.37,-28.32,-1008.79,-0.09,1.74,2.60,-9.90,82.80,5.85,24.93,6333.33,
09:09:31.400 -> ⸮04/21/2020,09:09:56.73,-15.14,-23.44,-1026.86,-0.87,3.08,1.75,-9.00,83.10,5.10,24.88,6666.67,
09:09:36.729 -> ⸮04/21/2020,09:10:02.07,-2.93,-18.55,-1015.14,0.27,5.70,3.08,-8.40,84.00,4.20,24.79,7000.00,
09:09:42.084 -> ⸮04/21/2020,09:10:07.41,-20.51,-35.16,-1017.58,-2.23,2.76,1.23,-8.10,82.95,6.00,24.88,7333.33,
09:09:47.413 -> ⸮04/21/2020,09:10:12.75,-3.42,-30.27,-1015.62,-0.59,3.02,-0.26,-8.25,85.05,5.10,24.98,7666.67,
09:09:52.763 -> ⸮04/21/2020,09:10:18.09,-11.23,-16.60,-1015.14,-0.40,4.34,5.27,-9.00,83.55,6.60,24.93,8000.00,
09:09:58.087 -> ⸮04/21/2020,09:10:23.43,-7.81,-26.37,-1014.65,-0.15,2.03,4.09,-8.85,85.20,7.20,24.93,8333.33,
09:10:03.429 -> ⸮04/21/2020,09:10:28.76,0.00,-27.34,-1003.91,-0.98,3.43,4.76,-8.70,85.35,6.30,24.98,8666.67,
09:10:08.780 -> ⸮04/21/2020,09:10:34.10,0.98,-17.09,-1014.16,-1.11,2.90,1.11,-8.10,84.90,6.45,25.22,9000.00,
09:10:14.131 -> ⸮04/21/2020,09:10:39.44,-5.86,-25.39,-1010.74,0.41,2.49,1.32,-8.40,84.00,6.45,25.27,9333.33,
09:10:19.453 -> ⸮04/21/2020,09:10:44.78,-108.40,-6.35,-1166.50,-8.48,9.34,112.17,-21.60,74.40,8.85,24.88,9666.67,
09:10:24.795 -> ⸮

```

nseidle, 2020-04-21:
Thanks for the thorough report! I'm attempting to replicate. I haven't been able to yet.
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
nseidle, 2020-04-21:
You mention failures at 5-10s between readings. Do you have success at >10s between readings?

Other questions:
* We recently moved to exFat support. What file system format is your SD card? FAT16, FAT32, or exFat?
* Why size and brand of microSD card are you using?
* STAT LED is currently not toggled in low power mode. The only LEDs that may be active are power (if jumper is intact) and TX LED as data is sent to terminal. Are you seeing the STAT LED toggle?
* If you don't mind, can you post your OLA_settings.cfg file so I can setup my OLA identically to yours?

adamgarbo, 2020-04-21:
Hi Nathan,

Thanks for the updates. The microSD cards were formatted using both FAT16 and FAT32.

I confirmed the behaviour with a 256 MB [industrial-rated micro SD card](https://industrial.apacer.com/en-ww/SSD/CV110-MSD) formatted using FAT16. At 1 Hz, only the first 3 samples are recorded.

Regarding power consumption, I can confirm the PWR jumper is cut and no current is running through it. When the microSD card is removed, Iq drops to ~250 uA after the battery is charged, but never appears to enter low-power while a microSD card is inserted.

Thanks for the clarification on the STAT LED.

Let me know if there's any additional info you need. I'm slowly making my way through the firmware and am happy to test.

nseidle, 2020-04-21:
I believe the issue was [this array](https://github.com/sparkfun/OpenLog_Artemis/blob/master/Firmware/OpenLog_Artemis/logging.ino#L20) was declared too small. The file names are "dataLog00003.txt" which is larger than 13 chars. This function is called every time the unit wakes so over time the bug was propagating all sorts of bad behavior including the stray random characters at power down you (and I) were seeing:

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

This bug snuck in because this code comes from the original OpenLog that only supported 8.3 file names.

With the fix in place, everything is behaving much better. Here is a release candidate: [OpenLog_Artemis-v12-RC.zip](https://github.com/sparkfun/OpenLog_Artemis/files/4512651/OpenLog_Artemis-v12-RC.zip). Please load it and kick the tires. I'll be 3s logging tonight to see if I can break it.

adamgarbo, 2020-04-21:
Thanks! I've uploaded the new firmware and at first glance, the data logging appears to be working much more smoothly. I'll also run a test overnight.

Quiescent draw also appears to be improved. Currently showing 330 uA on my Fluke 287 but I suspect the battery needs to recharge. I'll keep an eye on it to see if it drops.

Speaking of the sleep current, I know the AP2112 accounts for ~60 uA but where is the remaining ~180 uA coming from? Any chance of reducing it further in the next hardware rev?

adamgarbo, 2020-04-22:
No issues with the overnight data logging test, aside from clock drift. I'm assuming the plan is to eventually move away from using microseconds as an interval timer and start making use of the Artemis' built-in RTC alarms?

Quiescent draw also stabilized around ~240 uA (1 mW).

If your 3 s test didn't break anything, I think this issue can be closed.

nseidle, 2020-04-22:
Good to know. Thanks Adam! My tests similarly passed but I wasn't watching clock drift. Currently we are using the internal RTC for timestamps. I believe you've done some RTC analysis on Artemis. Let me know if there's anything we can do to shore it up.

~240uA matches exactly what I am seeing. To answer your question, yep AP2112, but also the CH340E, and the MCP LiPo charger. The microSD was also giving me a bit of head scratching and we attempt to totally disconnect it via the PChannel MOSFET but in practice it looks like it is being parasitically powered via some of the SPI pins (although even those are disabled). I welcome the help squeezing every uA we can out of the hardware. If you're up to the challenge, I will replace any hardware that you destroy in testing. Future revs may be lower current but I needed to get this released just to find bugs like you did.

I'll keep this open until I get the release complete.

adamgarbo, 2020-04-22:
Sounds good!

The clock drift is actually due to an accumulation of milliseconds over time. For example, with the interval set to 5 seconds, the log shows the actual time between measurements is 5.16 - 5.18 seconds. This results in the timestamps drifting over time (i.e. maintaining regular intervals of :05, :10, :15, etc. is not possible).

I've started [adding functionality to the Apollo3 RTC library](https://github.com/adamgarbo/Arduino_Apollo3/blob/rtcAlarms/libraries/RTC/src/RTC.h) and have got rolling alarms working well with the Artemis' RTC, but it's a work in progress.

Roger on the quiescent draw! Paul mentioned there were some gremlins.

Closed 2020-04-27.

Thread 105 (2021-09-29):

Software reset

alino93, 2021-09-29:
Hi @PaulZC,
I have been using the Slowlogging feature to reduce the power consumption of the boards at night and normal (fast) logging during the day. The boards are powered by a Lipo battery.

My problem is that if the battery dies, OLA does not turn on again automatically even after being charged by a wall adapter. The only way to turn it on again is the reset button or connecting to a computer. I give these sensors to very old people and it would be a lot easier to have a software solution to turn the board on again. Could we have a software solution to reset OLA? Like after fully charged? or at certain times of the day?

Thank you,
Ali

PaulZC, 2021-09-30:
Hello Ali (@alino93 ),

Unfortunately, the feature you are asking for is difficult to implement.

When the main battery dies, the Artemis goes into a very low power state which keeps the Real Time Clock (RTC) running. The only way to wake it from that state is with a reset.
- Generating a reset when the battery is charging or fully charged would require a hardware change (a new circuit board).
- Having the OLA wake up at a certain time of day, or after a period of time, is possible **but** if it does that, and the battery has not been recharged, then it will reset completely and the RTC will reset too.

The only safe way to keep the RTC running is to leave things as they are now.

I am happy to keep discussing this, but I do not think it is possible to give you the feature you need.

I think the simplest solution might be to ask your patients to make sure they recharge the OLA every night?

Best wishes,
Paul

alino93, 2021-09-30:
Hello Paul (@PaulZC),

Thank you for the clarification.

I ask the patients to charge the OLA every night but unfortunately, they usually forget.

Ok, a scheduled reset is not going to work because the RTC will rest and there is no easy way to generate reset when recharged.

Is there anything that I could add to the charger to reset the OLA every time they connect it to? (like when we connect the OLA to a computer)

Regards,
Ali

PaulZC, 2021-09-30:
Hi Ali,

Humm... A standard USB-C charger would not generate the reset. But maybe we could design a very simple board which you could plug in-line to generate the reset after a few seconds...
I shall think more about this!

Best wishes,
Paul

alino93, 2021-09-30:
Paul,

Thank you very much, that would be great!

Best,
Ali

alino93, 2021-11-19:
Hi Paul (@PaulZC)
I, unfortunately, lost two patients this past month because of this issue. Could you please help me to solve this issue or tell me to look where?
Thank you again,
Ali

vicgwee, 2021-11-19:
Hi Ali,

I'm really sorry to hear that.

If I'm not wrong, this board that Paul suggests would need to act as an USB Host, so it can connect with the CH340E chip to tell the OLA to reset. I'm not sure whether anything like that exists on the market right now.

Just wondering, would it be possible to tell the patients to press the reset button when they charge it? That could be a stopgap solution.

Victor

PaulZC, 2021-11-19:
Hello Ali,

I am very sorry to hear about your patients.

We have not forgotten about your request, but we are a small team and we are working on many other projects at the moment.

As Victor (@vicgwee) says, you need something which can: deliver power to the OLA via USB; and act as a "USB Host". The "USB Host" emulates a computer, and would need to open a serial connection to cause the OLA to reset.

SparkFun do offer a [USB Host Shield](https://www.sparkfun.com/products/9947) and that may do what is required. It would need to be connected to a "[RedBoard](https://www.sparkfun.com/redboards)". You would also need a standard power supply or wall adapter (with a 5.5/2.1mm power jack) to connect to the RedBoard. I do not have one of these boards, but I will try and get one to test.

There are other possibilities, such as this small board from Hobby Electronics: https://www.hobbytronics.co.uk/usb-host-board-v24 . Again, I do not have one of these boards, but I will order one to test. It may work on its own, or it may have to be connected to a microcontroller to open the serial connection. Again, it will need a separate power supply.

If either of these is successful, then - with some design effort - it would be possible to make a compact version dedicated to your project.

I will let you know when I have more news.

Very best wishes,
Paul

PaulZC, 2021-11-19:
Hello Ali,

I have ordered both boards. I will let you know when I have more news.

Best wishes,
Paul

alino93, 2021-11-19:
Hi Paul,

Thank you very much, that would be great please keep me updated. As Victor suggested I have tried to add a reset button and asked the patients to press it every morning but they tend to forget, also pressing it when the battery is empty resets the RTC.

Best,
Ali

PaulZC, 2021-11-21:
Hello Ali,

I have tested both the Hobby Electronics board and the SparkFun USB Host Shield.

The Hobby Electronics board is a very nice little product, but it can not (currently) generate the RTS reset pulse needed to wake the OLA. I have reached out to the Hobby Electronics team to see if it would be possible to add this feature.

I have had limited success with the SparkFun USB Host Shield. I was able to adapt some [code]( https://forum.arduino.cc/t/arduino-usb-host-shield-2-0-ch340-driver-problem/620548) which someone else has written to support the CH340 (the USB interface chip on the OLA):

- This works:
  - OLA is on and logging
  - Shield + RedBoard assembly is on and waiting
  - Connect the OLA to the shield assembly
  - The shield code recognizes and connects to the OLA
  - The shield code is able to reset the OLA (using the RTS signal)
  - Disconnect the OLA
  - Discharge the OLA battery so the Artemis goes into deep sleep
  - Re-connect the OLA to the shield
  - The shield code re-recognizes the OLA, and resets it to wake it up (without losing the RTC time)
  - The OLA continues to charge while logging normally

- This does not work:
  - OLA is in the low battery / deep sleep state
  - The shield assembly is powered off, then on
  - Connect the OLA (still in deep sleep) to the shield assembly
  - The shield assembly does not recognize the OLA and is not able to reset it to wake it from deep sleep

- This also does not work:
  - OLA is in the low battery / deep sleep state
  - The shield assembly is powered off
  - Connect the OLA (still in deep sleep) to the shield assembly
  - Power on the shield assembly
  - The shield assembly does not recognize the OLA and is not able to reset it to wake it from deep sleep

So, right now, I do not have a fully-working solution for you.

I know you want to keep your OLA assembly as compact as possible, but would it be acceptable for you to include a [Real Time Clock module](https://www.sparkfun.com/products/16281)? I could alter the OLA code so it would:
- Allow you to set the RTC module time via the OLA serial menus
- Disable the deep sleep functionality - so that the OLA will reset and its code will re-start normally as soon as USB power is connected
- When the code re-starts - the Artemis will automatically set its own RTC from the RTC module and then continue logging normally

Please let me know if that would be an acceptable solution for you.

Best wishes,
Paul

alino93, 2021-11-21:
Hi Paul,

Thank you for testing and working on a solution. So it seems the USB host shield is not working for me because the Redboard should be kept on all the time.
What about a raspberry pi board, could we program it to open a serial port and reset the OLA?

About the RTC module, should I add this module to the OLA assembly? Or could it be outside and ask the patients to connect the Qwiic cable to do its job?

Best,
Ali

PaulZC, 2021-11-21:
Hello Ali,

Raspberry Pi is another possibility. It would need (e.g.) a Python script which: runs on start-up; keeps checking for a CH340 connection on USB; if it sees one, toggle the RTS pin to reset the Artemis. It should all be feasible / possible but I have not written that type of Python code before.

The RTC module would be permanently connected to the OLA via a short Qwiic cable. It would not affect the battery life - it’s current draw is very low. But it will of course make each logger larger.

If your patients cannot remember to press the reset button, I do not think they would be able to remember to connect a Qwiic cable during charging?

Best wishes,
Paul

PaulZC, 2021-11-21:
There are some good suggestions here on how to detect if a serial device is connected / still connected:

https://stackoverflow.com/a/49450813

alino93, 2021-11-21:
Paul,

Yes connecting the Qwiic cable is not a good solution and pressing a button seems better. But the assembly is already large and I do not want to make it even larger. I think this way the thickness of my assembly would increase at least 1.5 times which is too bulky to mount on the body (I use 5 sensors on each person).

I will do some research about the Raspberry Pi solution and let you know.

Thank you,
Ali

PaulZC, 2021-11-21:
pySerial includes a function called **rts** which can be used to set the state of the RTS pin.

And here are suggestions on how to run a script on start-up:
https://www.tomshardware.com/uk/how-to/run-script-at-boot-raspberry-pi

Best wishes,
Paul

alino93, 2021-11-21:
Thanks Paul, this helps.
Best,
Ali

alino93, 2021-12-28:
Hi Paul,
I managed to solve the issue a while ago using a Raspberry Pi by installing the CH340 drivers on it and creating a autostart for a small script.
I have explained what I did here for the record: [https://github.com/alino93/OLAAutomaticReset]

I was thinking maybe I can use the Raspberry pi to set the RTC every time it is connected to the OLA (update with the Pi's time). Or other things like downloading the data, etc.  Do you think is that possible?

I think we can close this issue.
Thanks,
Ali

Closed 2021-12-28.

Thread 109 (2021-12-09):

Difficulty logging from BME280 with v1.11

adamgarbo, 2021-12-09:
### Subject of the issue
Hey @PaulZC, I've noticed that my OLA is having a hard time logging data from a SparkFun Qwiic BME280. I recently left it logging for a couple of weeks and discovered that no data was actually recorded. It's been a while since I've worked with the OLA, and wasn't sure if v1.11 (and v2.x of the Apollo3 Core) introduced some quirks that I may not be aware of.

### Your workbench
* Are you using a microSD card? If so, what size? How is it formatted (FAT, FAT32, or exFat)?
  * 32 GB FAT32
* At what frequency are you logging? For example, 10Hz, 1Hz, once every 5 seconds, etc.
  * 10 s
* What version of firmware are you using? This is shown at boot, for example: "Artemis OpenLog v1.10"
  * v1.11
* How is OpenLog Artemis wired to your sensor(s)?
  * Qwiic cable
* How is everything being powered?
  * 4.2V LiPo
* Are there any additional details that may help us help you?
  * I tested both enabling/disabling power to the Qwiic bus between measurements

### Steps to reproduce
* Connect BME280
* Configure OLA to record once every 10 seconds
* Disconnect USB-C and press reset button to create a new log file.

### Expected behaviour
* Data should be logged.

### Actual behaviour
* Sensor is detected:
`Autodetect complete`
`PHT-BME280 online at address 0x77`

* The collected data (see below) looks to just be the default values from the registers or whatever was in memory.
* It seems that the sensor is read from correctly while connected to Serial Monitor, but no dice when not connected to Serial.
* Logging also doesn't work when disabling power to Qwiic bus while connected to Serial Monitor:
`1) Turn off Qwiic bus power between readings (>2s): Yes`
* I suspect that there may be a simple solution and there's something I've missed (or forgotten)!

```
rtcDate,rtcTime,VIN,pressure_Pa,humidity_%,x,temp_degC,count,
11/28/2021,11:50:59.73,3.99,71554.79,94.99,2839.12,19.66,18400,
11/28/2021,11:51:09.73,3.99,71554.79,94.99,2839.12,19.66,18401,
11/28/2021,11:51:19.74,3.98,71554.79,94.99,2839.12,19.66,18402,
11/28/2021,11:51:29.74,3.99,71554.79,94.99,2839.12,19.66,18403,
11/28/2021,11:51:39.74,3.98,71554.79,94.99,2839.12,19.66,18404,
11/28/2021,11:51:49.72,3.99,71554.79,94.99,2839.12,19.66,18405,
11/28/2021,11:51:59.72,3.99,71554.79,94.99,2839.12,19.66,18406,
11/28/2021,11:52:09.72,3.99,71554.79,94.99,2839.12,19.66,18407,
11/28/2021,11:52:19.73,3.98,71554.79,94.99,2839.12,19.66,18408,
11/28/2021,11:52:29.73,3.98,71554.79,94.99,2839.12,19.66,18409,
11/28/2021,11:52:39.73,3.98,71554.79,94.99,2839.12,19.66,18410,
11/28/2021,11:52:49.73,3.98,71554.79,94.99,2839.12,19.66,18411,
11/28/2021,11:52:59.73,3.99,71554.79,94.99,2839.12,19.66,18412,
11/28/2021,11:53:09.73,3.99,71554.79,94.99,2839.12,19.66,18413,
11/28/2021,11:53:19.73,3.99,71554.79,94.99,2839.12,19.66,18414,
11/28/2021,11:53:29.72,3.98,71554.79,94.99,2839.12,19.66,18415,
11/28/2021,11:53:39.72,3.98,71554.79,94.99,2839.12,19.66,18416,
11/28/2021,11:53:49.72,3.98,71554.79,94.99,2839.12,19.66,18417,
11/28/2021,11:53:59.72,3.99,71554.79,94.99,2839.12,19.66,18418,
```

adamgarbo, 2021-12-09:
Hi @PaulZC,

Here's some sample output when disabling power to I2C. The BME280's LED turns on and off, but my suspicion is that the sensor isn't initializing fully. Adjusting the minimum power-up delay doesn't appear to have any effect.

```
13:58:51.693 -> rtcDate,rtcTime,VIN,pressure_Pa,humidity_%,temp_degC,count,
13:58:51.764 -> 12/09/2021,13:59:18.17,5.23,31792.82,0.00,21.15,1,
13:58:51.872 -> ⸮12/09/2021,13:59:18.59,5.24,71723.91,95.17,19.66,2,
13:58:52.289 -> ⸮12/09/2021,13:59:23.58,5.24,71554.79,94.99,19.66,3,
13:58:57.301 -> ⸮12/09/2021,13:59:28.58,5.24,71554.79,94.99,19.66,4,
13:59:02.300 -> ⸮12/09/2021,13:59:33.58,5.24,71554.79,94.99,19.66,5,
13:59:07.308 -> ⸮12/09/2021,13:59:38.57,5.24,71554.79,94.99,19.66,6,
13:59:12.268 -> ⸮12/09/2021,13:59:43.57,5.24,71554.79,94.99,19.66,7,
13:59:17.282 -> ⸮12/09/2021,13:59:48.57,5.24,71554.79,94.99,19.66,8,
13:59:22.294 -> ⸮12/09/2021,13:59:53.58,5.24,71554.79,94.99,19.66,9,
13:59:27.343 -> ⸮12/09/2021,13:59:58.58,5.24,71554.79,94.99,19.66,10,
13:59:32.284 -> ⸮12/09/2021,14:00:03.58,5.23,71554.79,94.99,19.66,11,
13:59:37.282 -> ⸮12/09/2021,14:00:08.58,5.24,71554.79,94.99,19.66,12,
13:59:42.304 -> ⸮12/09/2021,14:00:13.58,5.24,71554.79,94.99,19.66,13,
13:59:47.288 -> ⸮12/09/2021,14:00:18.58,5.24,71554.79,94.99,19.66,14,
13:59:52.301 -> ⸮12/09/2021,14:00:23.59,5.24,71554.79,94.99,19.66,15,
```

PaulZC, 2021-12-13:
Hi Adam (@adamgarbo ),

I'm beginning to suspect this is linked to the mux detection code. The BME280's address is 0x76 or 0x77 and that's mux territory...

Can you please try changing the split pads to change the board's address to 0x76 and see if that's makes a difference?

Why? I added some extra code to ```testMuxDevice``` for 0x76 to allow the MS5637 / MS5837 / MS8607 to be detected before attempting to detect a mux. The same code should also detect the BME280 and prevent ```multiplexerBegin``` from being called. I think it might be the ```multiplexerBegin``` which is causing the problem.

For 0x77, ```testMuxDevice```  always does a ```multiplexerBegin```. ```multiplexerBegin``` does some writing and reading to check if a mux is connected and maybe that sometimes confuses the BME280 so it fails to be detected?

If my hunch is correct, the solution will be to replicate [these lines](https://github.com/sparkfun/OpenLog_Artemis/blob/5c10915f0a93f4334c200ecfe226d0db837d4110/Firmware/OpenLog_Artemis/autoDetect.ino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) in the [case 0x77](https://github.com/sparkfun/OpenLog_Artemis/blob/5c10915f0a93f4334c200ecfe226d0db837d4110/Firmware/OpenLog_Artemis/autoDetect.ino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).

Thanks!
Paul

adamgarbo, 2021-12-13:
Hi Paul,

I think you hit the nail on the head! I didn't have access to my soldering iron to change the I2C address, so I went ahead and added the code you mentioned and uploaded new firmware.

I did a quick test with power to the Qwiic bus being disabled between measurements at a logging rate of 10 seconds. So far, so good!

Cheers,
Adam

```
11:05:24.990 -> rtcDate,rtcTime,pressure_Pa,humidity_%,altitude_m,temp_degC,count,
11:05:25.167 -> 12/13/2021,11:05:56.21,100224.05,30.79,92.05,22.41,276,
11:05:25.673 -> 12/13/2021,11:05:56.71,100256.27,30.61,89.81,22.28,277,
11:05:36.013 -> 12/13/2021,11:06:07.05,100252.97,30.23,89.39,22.12,278,
11:05:45.970 -> 12/13/2021,11:06:17.03,100240.27,30.07,90.69,22.08,279,
11:05:55.987 -> 12/13/2021,11:06:27.04,100247.43,29.93,90.55,22.01,280,
11:06:05.982 -> 12/13/2021,11:06:37.04,99695.36,73.79,136.55,25.37,281,
11:06:15.996 -> 12/13/2021,11:06:47.04,100354.34,84.14,81.58,24.72,282,
11:06:25.997 -> 12/13/2021,11:06:57.04,99886.42,89.08,119.98,26.97,283,
```

Cheers,
Adam

adamgarbo, 2021-12-13:
Whoops, forgot to include the code I added to autoDetect.ino:

```
    case 0x77:
      {
        //Ignore devices we've already recorded. This was causing the mux to get tested, a begin() would happen, and the mux would be reset.
        if (deviceExists(DEVICE_MULTIPLEXER, i2cAddress, muxAddress, portNumber) == true) return (DEVICE_MULTIPLEXER);

        qwiic.beginTransmission((uint8_t)i2cAddress);
        qwiic.write((uint8_t)0xA0);
        uint8_t i2c_status = qwiic.endTransmission();

        if (i2c_status == 0) // If the I2C write was successful
        {
          qwiic.requestFrom((uint8_t)i2cAddress, 2U); // Read two bytes
          uint8_t buffer[2];
          for (uint8_t i = 0; i < 2; i++)
          {
            buffer[i] = qwiic.read();
          }
          if ((buffer[0] != 0xA0) || (buffer[1] != 0xA0)) // If we read back something other than 0xA0A0 then we are probably talking to an BME280, not a mux
          {
            return (DEVICE_PHT_BME280);
          }
        }

        //Confidence: Medium - Write/Read/Clear to 0x00
        if (multiplexerBegin(i2cAddress, qwiic) == true) //Address, Wire port
          return (DEVICE_MULTIPLEXER);
      }
      break;
```

PaulZC, 2021-12-14:
Thanks for reporting @adamgarbo - corrected in v2.1
Best wishes,
Paul

Closed 2021-12-14.

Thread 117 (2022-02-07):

OLA waking up from sleep and going into menu when there's a signal on the RX pin.

ryanneve, 2022-02-07:
### Subject of the issue
Despite the firmware change we pushed, we continue to sometimes see OLA waking up when it shouldn't. Note that this isn't always reproducible, but when it gets in this state, it occurs continuously.

### Your workbench

- OLA with modified 2.1 firmware (#116 ). OLA has pressure sensor on i2c bus.
- BLE UART module is connected to RX/TX and powered by qwiic bus.
- OLA powered by 3x D-cell batteries in series with MEAS cut.
- USB-C not connected.
- usBetweenReadings=40000000 (40 seconds). When we deploy this will be 360 seconds
- qwiicBusPowerUpDelayMs=10000. This is to give BLE module time to power up and connect.
- minimumAwakeTimeMillis=15000. This is to allow data to finish transmitting, and give a window for external access to console.

We have noted that after power is removed from qwiic bus, signal on BREAKOUT_PIN_RX drops slowly from 3v3 to 0. Can provide oscilloscope image if it helps, but I thought the new  `am_hal_gpio_pinconfig(13 , g_AM_HAL_GPIO_DISABLE); //RX1`  before sleeping would make the OLA ignore that pin.

### Steps to reproduce
If we disconnect wire from OLA RX to BLE TX, problem doesn't occur.

### Expected behavior
OLA should stay asleep until woken by timer.

### Actual behavior
Sample is taken.
OLA goes to sleep (as verified in debug statements).
OLA wakes up and goes into menu.

Is there a way to tell what interrupt woke the OLA?

[OLA_settings.txt](https://github.com/sparkfun/OpenLog_Artemis/files/8017979/OLA_settings.txt)
[OLA_deviceSettings.txt](https://github.com/sparkfun/OpenLog_Artemis/files/8017980/OLA_deviceSettings.txt)

PaulZC, 2022-02-07:
Hi Ryan,

I’m wondering if the serial Rx interrupt is still enabled, even though the pin is disabled? The code for this will be buried in the Apollo3 core and won’t be easy to find…

I wonder if a logic buffer will solve your issue? A simple non-inverting buffer that goes high impedance when the power goes off should do the trick? Let me know if you need some suggestions.

All the best,
Paul

ryanneve, 2022-02-08:
Paul,

I'm going to try turning power off to the qwiic bus earlier in the goToSleep() sequence with the hope that any signal from the attached BLE module will be done by the time we go into deep sleep.

The configureSerial1TxRx() function in [OpenLog_Artemis.ino](https://github.com/sparkfun/OpenLog_Artemis/blob/main/Firmware/OpenLog_Artemis/OpenLog_Artemis.ino) sets a pull-up on the RX pin. Should this be disabled before Deep Sleep? This might allow the signal on that pin to drop to ground faster.
Not sure of the syntax to do this.
`am_hal_gpio_pincfg_t (g_AM_BSP_GPIO_COM_UART_RX.ePullup, AM_HAL_GPIO_PIN_PULLUP_NONE);`
It looks to already be re-enabled in wakeFromSleep()

As far as digging into the Apollo3 core.  Perhaps Serial1.end() may not be detaching the interrupts.

I looked some at [Arduino_Apollo3](https://github.com/sparkfun/Arduino_Apollo3), but couldn't find much related to Serial or Serial interrupts. There is this issue of yours [https://github.com/sparkfun/Arduino_Apollo3/issues/423](https://github.com/sparkfun/Arduino_Apollo3/issues/423) which may relate.

I also looked in [ARMmbed/mbed-os](https://github.com/ARMmbed/mbed-os) where I found that [serial_api.c](https://github.com/ARMmbed/mbed-os/blob/master/targets/TARGET_Ambiq_Micro/TARGET_Apollo3/device/serial_api.c) has a serial_irq_set function which enables and disables serial interrupts using  am_hal_uart_interrupt_enable() and am_hal_uart_interrupt_disable().
It looks like serial_irq_set() is called from the attach() method in [SerialBase.cpp](https://github.com/ARMmbed/mbed-os/blob/master/drivers/source/SerialBase.cpp). I can't find where to look to see if Serial1.end() detaches its interrupts.

PaulZC, 2022-02-10:
Hi Paul (@paulvha ),

Sincere thanks for this as always - it helps a lot!

Ryan (@ryanneve ): I will try and compile an updated OLA binary for you including these changes. I'm buried in other projects at the moment, but I will get to it as soon as I can. For speed, I might just include Paul's changes directly into the OLA code. Longer term, this needs fixing properly as Paul suggests.

Best wishes,
The other Paul

PaulZC, 2022-03-30:
Hi Paul (@paulvha ),

It has taken a very long time, but I am now trying your fix for this issue. (Thank you again for sharing it!)

I am seeing some strange compilation errors:

```
C:\Users\pc235\AppData\Local\Arduino15\packages\SparkFun\hardware\apollo3\2.2.0\cores\arduino\mbed-bridge\core-implement\HardwareSerial.cpp: In member function 'virtual void UART::end()':
C:\Users\pc235\AppData\Local\Arduino15\packages\SparkFun\hardware\apollo3\2.2.0\cores\arduino\mbed-bridge\core-implement\HardwareSerial.cpp:128:31: error: 'void mbed::SerialBase::_deinit()' is inaccessible within this context
     UnbufferedSerial::_deinit();  // power down - edit pvh
                               ^
In file included from C:\Users\pc235\AppData\Local\Arduino15\packages\SparkFun\hardware\apollo3\2.2.0/cores/mbed-os/drivers/UnbufferedSerial.h:26,
                 from C:\Users\pc235\AppData\Local\Arduino15\packages\SparkFun\hardware\apollo3\2.2.0/cores/mbed-os/mbed.h:70,
                 from C:\Users\pc235\AppData\Local\Arduino15\packages\SparkFun\hardware\apollo3\2.2.0/cores/arduino/mbed-bridge/Arduino.h:14,
                 from C:\Users\pc235\AppData\Local\Arduino15\packages\SparkFun\hardware\apollo3\2.2.0/cores/arduino/sdk/ArduinoSDK.h:9,
                 from <command-line>:
C:\Users\pc235\AppData\Local\Arduino15\packages\SparkFun\hardware\apollo3\2.2.0/cores/mbed-os/drivers/SerialBase.h:146:10: note: declared here
     void _deinit(); // paulvha
          ^~~~~~~
C:\Users\pc235\AppData\Local\Arduino15\packages\SparkFun\hardware\apollo3\2.2.0\cores\arduino\mbed-bridge\core-implement\HardwareSerial.cpp:128:31: error: 'mbed::SerialBase' is not an accessible base of 'UART'
     UnbufferedSerial::_deinit();  // power down - edit pvh
```

I think I must have missed a step...? But I cannot figure it out. Have I done something silly?

I'm using a fresh install of v2.2.0 and have replaced the three files with the ones from your OneDrive.

Sincere thanks,
Paul

adamgarbo, 2022-03-30:
You know you're in good hands when **_both_** of the Pauls are on the case! :stuck_out_tongue_winking_eye:

Very keen to see the outcome of this issue, especially if it addresses the higher quiescent draw that's been observed on v2.x.

paulvha, 2022-03-31:
My bad, I forgot to include a change. I have updated the document on the share.
**In mbed-os/drivers/UnbufferedSerial.h (1 change)**

Around line 158 add

using SerialBase::_deinit;

To the list :
    using SerialBase::readable;
    using SerialBase::writeable;
    using SerialBase::format;
    using SerialBase::attach;
    using SerialBase::baud;
    using SerialBase::RxIrq;
    using SerialBase::TxIrq;
    using SerialBase::IrqCnt;

P.s. I tried to apply a solution from the issue 454, but have not been able to achieve that.. Maybe later

PaulZC, 2022-03-31:
Hi Paul (@paulvha ),

Sincere thanks for this. As my American colleagues would say: "You're the man!"

The fix is working nicely. Activity on the RX pin no longer wakes the Artemis from sleep.

I've got more issues to fix, SPI stops working after coming out of sleep, but I'll investigate and fix that. I suspect I'm not re-enabling something correctly.

Thanks again,
Paul

paulvha, 2022-03-31:
Good to hear..
With SPI end there were 2 issues: wrong check on dev (https://github.com/sparkfun/Arduino_Apollo3/issues/442) and next to that it should do  dev = 0 in end(), else it will not get a new SPI instance during begin()

Still try to get an alternative working for UART, although that is becoming more complex than the current fix. :-)
regards
Paulvha

PaulZC, 2022-04-01:
OK. I think I've got a working version of OLA which fixes this issue. BUT, to get it working, I've had to regress to v2.1.0 of the core...

Why? Well, with v2.2.0 of the core, it looks like SdFat behaves differently and can leave the CE pin low. This causes all kinds of badness when trying to communicate with the IMU (which shares the SPI bus).

Just to prove I'm not making this up:

Here is the OLA start-up with v2.1.0 of the core (modified with the Serial _deinit fix):

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

At 1000ms, there is a burst of activity on the microSD card which lasts for about 270ms. Then the code pauses for about 280ms. Then you can see three bursts of activity while the code reads the settings from the SD card and opens the log files. Then you can see the code initializing the IMU.

Compare this with v2.2.0 of the core (modified with the Serial _deinit fix):

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

Notice how the SD card activity is the same BUT the SD CE pin goes low and stays low after the log files are opened. This of course causes all kinds of badness for the IMU and it does not start up correctly.
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
PaulZC, 2022-04-01:
Forgot to mention: both tests included the SPI.end changes too:

```
        void arduino::MbedSPI::end() {
            if (dev) {
                delete dev;
                dev = NULL;
            }
        }
```

paulvha, 2022-04-01:
Recently I wrote a filemanager (based on SdFat) to read a MicroSD card on different Artemis-based boards (https://github.com/paulvha/apollo3/tree/master/Artemis_filemanager). Trying to understand the SdFat code structure was a challenge, but it is an interesting library.  Most routines of SdSpiCard.cpp have the same standard structure:
```
Do something
Was it good, spiStop(); and return true
Did it fail, spiStop(); and return false
```
In spiStop(); it will unselect the CE.

But only a few (and this one most noticeable differ) as it seems to be missing spiStop(); when it fails.

```
bool SharedSpiCard::readSectors(uint32_t sector, uint8_t* dst, size_t ns) {
  if (!readStart(sector)) {
    goto fail;
  }
  for (size_t i = 0; i < ns; i++, dst += 512) {
    if (!readData(dst, 512)) {
      goto fail;
    }
  }
  return readStop();
 fail:
  return false;
}
```
readStop() will send a CMD12 and follow the same standard structure as mentioned earlier.

So maybe the issue is related to an error during reading a sector and this missing spiStop() in the code.

regards,
Paulvha

PaulZC, 2022-04-01:
Thank you Paul - I will give it a try.

Are your changes based on v2.2.0 or v2.2.1?

Have a nice weekend,
Paul

paulvha, 2022-04-01:
I have used V2.2.1.

regards
Paul

PaulZC, 2022-04-08:
Hi Ryan (@ryanneve ),

We have a solution for you. Please try version 2.2 of the firmware. It will be released in a few minutes.

Just for reference:

v2.2 is based on v2.2.1 of the Apollo3 core. That's the latest release which went live a few days ago.
It includes @paulvha 's ```UART:end()``` [modifications](https://1drv.ms/u/s!AvgMkLxXj95qhtVNhdQgRc5AqJcxeA?e=5Bww8W).
I've tested this on V10 and X04 hardware and it works well.
Previously, any activity on the RX pin would have woken the Artemis from deep sleep. The RX pin slowly being pulled low as your BLE module discharged would have done the same thing. Paul's fix prevents this.

I have tested the firmware thoroughly, but it has **so** many options I might have missed something. Please let me know if you see any weirdness.

Hope all is well in Florida - and that you enjoy the new firmware!

Best wishes,
Paul

paulvha, 2022-04-08:
PaulZC : will you pass this fix on to Wenn0101/ Kyle so it becomes part of the next release of the Artemis library ?

PaulZC, 2022-04-08:
Sure - not a problem - Kyle ( @Wenn0101 ) is already aware of the changes - thank you!

ryanneve, 2022-04-08:
Thanks! I'll try to get this out in the field (North Carolina) and see how it goes.

PaulZC, 2022-04-08:
Hi Ryan,

Oops! Sorry! Senile moment. Indeed, I hope all is well in NC.

Very best wishes,
Paul

Closed 2022-04-08.

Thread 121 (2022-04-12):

GPS NEO-M9N at 25 Hz on Artemis OpenLog

Ribinn, 2022-04-12:
### Subject of the issue
Describe your issue here. If you reference a datasheet please specify which one and in which section (ie, the protocol manual, section 5.1.2). Additionally, screenshots are easy to paste into github.
I use a NEO-M9N GPS connected to OpenLog Artemis. This GPS is supposed to work up to 25Hz but the firmware limits the data rate to 10Hz. So a firmware change would be appreciated.

### Your workbench
* A 2Go Fat32 microSD card
* Presently 10Hz with GPS. Wanting to increase to 25 Hz
* firmware "Artemis OpenLog v1.7"
* How is OpenLog Artemis wired to your sensor(s) : GPS NEO-M9N
* How is everything being powered? 3,7V Lipo battery
* Are there any additional details that may help us help you?

### Steps to reproduce
Tell us how to reproduce this issue. Please post stripped down example code demonstrating your issue.
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

### Expected behavior
25 Hz data rate both for IMU and GPS

### Actual behavior
10 Hz data rate when connected to GPS

PaulZC, 2022-04-26:
Hello Christian (@Ribinn ),

As discussed on the forum:

I have compiled a v2.3 BETA version of the firmware for you.  It seems to work well but I have only performed a very quick test. You can download the new binary from:

https://github.com/sparkfun/OpenLog_Artemis/blob/main/Binaries/OpenLog_Artemis-V10-v23_BETA.bin

Please note: you need to open the "Attached Devices" menu, select the u-blox receiver, and enable the "Use autoPVT" option. Without this, you will not be able to reach 25Hz reliably.

Also, please make sure you [open the "I2C" split pad jumpers](https://github.com/sparkfun/SparkFun_u-blox_GNSS_Arduino_Library#i2c-support) on the back of the NEO board.

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

Best wishes,
Paul

Closed 2022-04-26.

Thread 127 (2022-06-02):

Bug/Feature Request - PIN_POWER_LOSS triggered when it shouldn't be.

ryanneve, 2022-06-02:
### Subject of the issue
Occasional shutdowns when deployed, probably due to PIN_POWER_LOSS interrupt when there should be plenty of power.

### Your workbench
OLA powered by 3xC cell alkaline batteries. Sampling every 6 minutes. External BLE module and pressure transmitter powered by Qwiic bus. Should have enough power for many months.

### Steps to reproduce
Not usually reproducible, but on several occasions after several days of operating fine, the OLA has mysteriously shut down. Recorded battery voltages are well above minimums. Due to significant effort required to physically reach sensor and reset, the benefits of this functionality are outweighed by the liabilities.

### Expected behavior
Should only trigger on actual low battery.

### Actual behavior
Triggers mysteriously. I've been disabling this functionality and re-compiling firmware. It might be nice to have a menu option to disable, or perhaps perform additional voltage checks to confirm low battery situation.

PaulZC, 2022-06-02:
Hi Ryan (@ryanneve ),

Catching and debugging the 'glitch' shut-downs will be extremely challenging. If it only happens after ~days, I would need a dedicated set-up to catch it - almost certainly with an oscilloscope or a logic analyzer running full time and monitoring PIN_POWER_LOSS.

Is there any chance it could be (e.g.) lightning related?

I'd like to close this issue in favor of #128, if that's OK? I've got no problem with compiling the custom binary, but trying to catch the glitch is not something I can do any time soon.

Best wishes,
Paul

ryanneve, 2022-06-02:
@PaulZC , I agree it would be almost impossible to catch. The OLAs with the mysterious shutdowns are in waterproof cases, down in urban storm drains (sometimes several hours drive away). Unlikely to be lightning. What are your thoughts on the OLA doing some sort of sanity check on the battery voltage before calling powerDownOLA() if (powerLossSeen)? Feel free to close this although my goal is always to get away from compiling my own version of the code. As an alternate solution, I could try implementing a menu selectable IgnorePinPowerLoss flag and pushing that change.

PaulZC, 2022-06-02:
Hi Ryan,

When the power loss interrupt is triggered, the voltage is (supposedly) already below 3.0V and falling fast. The Artemis needs to go into deep sleep as quickly as possible, otherwise it starts drawing too much current from the back-up battery, blacks-out and resets the RTC. Spending additional time measuring the voltage and deciding whether to go into deep sleep is - IMO - a risky thing to do.

I should be able to compile the modified binary in a couple of days. But I have some other work I need to finish first...

Closing in favor of #128 - but please re-open or continue the discussion if you think it would be useful.

Best wishes,
Paul

Closed 2022-06-02.

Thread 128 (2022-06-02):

Feature request: firmware pre compiled binaries, without the interrupt driven low power sleep

jerabaul29, 2022-06-02:
Follow up of https://github.com/sparkfun/OpenLog_Artemis/issues/126 :

Can we get some pre compiled firmware binaries that deactivate the power loss interrupt, so that in case of a transient power interruption for example due to vibrations, the OLA just stops / brows out temporarily, and then recovers / reboots when the power is back, rather than get stuck in a deep power sleep?

Use case: uses of OLA that need to log, "no matter what", but where reboots are not such a big issues, and are inaccessible for user reset button pressing.

FYI @tnn77

adamgarbo, 2022-06-02:
@jerabaul29

In case you weren't aware, this is something you can do yourself from the Arduino IDE:

`Sketch > Export compiled Binary`

Cheers,
Adam

jerabaul29, 2022-06-02:
@adamgarbo thanks :) . Yes, I know, this is already what I do with the OMB firmware :) . The idea here is that I have not set up the libraries in the right versions to compile the OLA firmware, and I am not too familiar with the OLA firmware either, so would feel 'safer' if someone very familiar with this specific project tales care of the setup and configuration and compilation :) .

jerabaul29, 2022-08-06:
Any update on this? In addition to firmware update / different versions, could an option be to 'simply' add a connection pad between the coin cell battery and the Artemis, so that the coin cell battery can be disabled altogether if wanted?

ryanneve, 2022-08-06:
@jerabaul29
I've been disabling this behavior in firmware after our OLAs have gone to sleep and never woken up. Resetting the OLA fixes it, but my OLAs are very hard to get to. Batteries seem to always be fine. It's a mystery. See #127
Unfortunately, I've got a new PC so need to re-setup my development environment. Will try to get a change pushed that adds a configuration option to ignore low voltage sensor interrupt.

PaulZC, 2022-08-07:
This is still on the things-to-do list. I haven't forgotten, I just have a ton of other projects to tackle first...

Sorry for the delay,
Paul

jerabaul29, 2022-08-16:
Amazing, many thanks!

I wont have the hardware to test, but maybe @tnn77 can? :)

PaulZC, 2022-08-17:
Hi Ryan,

But if we do that, the code will almost certainly need a reset to wake again. powerDownOLA puts the Artemis into a deep sleep state. If there is any charge in the back-up battery, the battery will keep it in that deep sleep state... Only a reset will wake it. Sounds ~risky to me?

Thanks!
Paul

ryanneve, 2022-08-17:
@PaulZC , you may be right. My thought was that transient power issues probably won't appear while the OLA is in setup(). Let's try it your way and see how it goes. Is the goal to change this to a configuration option eventually? Excited about the watchdog timer!

PaulZC, 2022-08-17:
Configuration options are nice, but, for critical stuff like this, I always lean towards having it hard-coded. Then there's ~zero possibility of the WDT being mis-configured. The WDT is there to help save you from code-corruption during a brown-out. If running the WDT is selective, there's a small but non-zero chance of it being disabled when you really need it.

Please give the binary a thorough shake, whenever you can spare the time. I'm grateful for the feedback.

Very best wishes,
Paul

tnn77, 2022-08-17:
@jerabaul29
Yes, I have one at my desk. I'll try to find time to test the binary. I'll let you know when I get a chance!

PaulZC, 2022-08-26:
This feature has been included in v2.4. Going forward, we will include ```noPowerLossProtection``` binaries for each new release.

Closed 2022-08-26.

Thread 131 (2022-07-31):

Investigate wake-after-sleep issues when no SD card is inserted

PaulZC, 2022-07-31:
Reported in this forum issue:

https://forum.sparkfun.com/viewtopic.php?f=171&t=58109

PaulZC, 2022-08-01:
Resolved in v2.3

Closing...

Closed 2022-08-01.

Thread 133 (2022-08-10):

OpenLog Artemis Without IMU - not detecting qwiic devices

rglongoria, 2022-08-10:
### Subject of the issue
I have just received one of these new models without the IMU. Can get it to log time stamp and sample rate but it will not detect any qwiic sensors I attach, even though I'm using one listed on the list Sparkfun provided.

### Your workbench
* Are you using a microSD card? 1 GB
* At what frequency are you logging? For example, 10Hz (default)
* What version of firmware are you using? Artemis OpenLog v1.10
* How is OpenLog Artemis wired to your sensor(s)? qwiic
* How is everything being powered? via USB-C and have also tried a LiPo battery
* Are there any additional details that may help us help you?

### Steps to reproduce
All I've done is log into the serial monitor to view logged data. Have also looked at data files on the SD card. Nothing is being logged except time stamp and the data rate.

In Serial Monitor, I can run the menu and have run '6' to detect devices. Comes back that no devices are connected. I have a Qwiic Pressure MS5637 connected.

### Expected behavior
Expect to see pressure data

### Actual behavior
No pressure data is being logged, device is not detected

PaulZC, 2022-08-10:
Hi @rglongoria ,

I'm sorry you are having problems with the OLA.

I have just tested an IMU-less OLA here with an MS8607 sensor and it is working fine. The MS8607 is very similar to the MS5637, except it has an extra humidity sensor built-in (with its own I2C address).

You say you are running Artemis OpenLog v1.10 firmware? Are you sure? All of the IMU-less OLAs ship with version 2.2 firmware installed. v1.10 is really very old. Can you please check the version again?

Thank you,
Paul

rglongoria, 2022-08-10:
Hello Paul,
sorry, it is running Artemis OpenLog v2.3
By the way, this device does not start up right away. No status lights, etc.
I need to reset a few times before it starts logging.

PaulZC, 2022-08-10:
If the OLA has gone into deep sleep, it needs a reset to wake it up. There is more information about this in the hook-up guide:

https://learn.sparkfun.com/tutorials/openlog-artemis-hookup-guide/low-power-considerations

This is very puzzling!

I have also tested an MS5837 - again very similar to the MS5637 - and it too works OK. Unfortunately I don't have an MS5637...

Do you have a different sensor you can test?

If you are willing to do a little diagnostic work: please open the menu and select the secret option "d" to open the debug menu. Please enable the debug messages, exit the menus, then restart the OLA. Please copy and paste the start-up messages here. They may provide some clues. It should look like the text below:

Or we can arrange a return / replacement for you. Just let me know.

```
Artemis OpenLog v2.3
Logging to: dataLog00061.TXT
Logging to: serialLog00002.TXT
ICM_20948::checkID: ICM_20948_check_id returned: Wrong ID
ICM_20948::startupDefault: checkID returned: Wrong ID
ICM_20948_SPI::begin: startupDefault returned: Wrong ID
beginIMU: first attempt at myICM.begin failed. myICM.status = 4
ICM_20948::checkID: ICM_20948_check_id returned: Wrong ID
ICM_20948::startupDefault: checkID returned: Wrong ID
ICM_20948_SPI::begin: startupDefault returned: Wrong ID
beginIMU: second attempt at myICM.begin failed. myICM.status = 4
ICM-20948 failed to init.
SD card online
Data logging online
Serial logging online
IMU offline - or not present
detectQwiicDevices started
waitForQwiicBusPowerDelay: qwiicPowerHasBeenOnFor 1040ms
Identifying Qwiic Muxes...
detectQwiicDevices: something detected at address 0x76
detectQwiicDevices: MS8607/MS5637/MS5837/BME280 found at address 0x76. Ignoring it for now...
Identifying Qwiic Devices...
detectQwiicDevices: something detected at address 0x76
detectQwiicDevices: added Pressure-MS5837 at address 0x76
Autodetect complete
waitForQwiicBusPowerDelay: qwiicPowerHasBeenOnFor 1130ms
beginQwiicDevices: attempting to begin deviceType Pressure-MS5837 at address 0x76 using mux address 0x0 and port number 0
beginQwiicDevices: device is online
setMaxI2CSpeed: setting qwiic clock speed to 100000Hz
Pressure-MS5837 online at address 0x76
Device count: 1
rtcDate,rtcTime,mbar,degC,depth_m,alt_m,output_Hz,
01/01/2000,00:29:17.19,1020.07,28.80,0.072,-56.59,20.0,
01/01/2000,00:29:17.29,1020.10,28.85,0.073,-56.84,13.333,
01/01/2000,00:29:17.40,1020.05,28.88,0.072,-56.43,12.0,
01/01/2000,00:29:17.50,1020.04,28.89,0.072,-56.35,11.429,
01/01/2000,00:29:17.60,1020.05,28.90,0.072,-56.43,11.111,
01/01/2000,00:29:17.70,1020.06,28.91,0.072,-56.51,10.909,
01/01/2000,00:29:17.80,1020.03,28.91,0.072,-56.26,10.769,
```

rglongoria, 2022-08-10:
I've tested with several qwiic devices I have, same results.

Here you go after debug enabled:

0a00,07:Artemis OpenLog v2.3
Logging to: dataLog00020.TXT
Finding the next available log file.
This could take a long time if the SD card contains many existing log files.
Logging to: serialLog00000.TXT
ICM_20948::checkID: ICM_20948_check_id returned: Wrong ID
ICM_20948::startupDefault: checkID returned: Wrong ID
ICM_20948_SPI::begin: startupDefault returned: Wrong ID
beginIMU: first attempt at myICM.begin failed. myICM.status = 4
ICM_20948::checkID: ICM_20948_check_id returned: Wrong ID
ICM_20948::startupDefault: checkID returned: Wrong ID
ICM_20948_SPI::begin: startupDefault returned: Wrong ID
beginIMU: second attempt at myICM.begin failed. myICM.status = 4
ICM-20948 failed to init.
SD card online
Data logging online
Serial logging online
IMU offline - or not present
detectQwiicDevices started
waitForQwiicBusPowerDelay: qwiicPowerHasBeenOnFor 550ms
waitForQwiicBusPowerDelay: delaying for 450
Identifying Qwiic Muxes...
Identifying Qwiic Devices...
No Qwiic devices detected
rtcDate,rtcTime,output_Hz,
01/01/2000,07:51:33.40,0.0,
01/01/2000,07:51:33.50,20.0,
01/01/2000,07:51:33.60,15.0,

PaulZC, 2022-08-10:
It could be the Qwiic cable. Have you tried different cables?

Apart from that, sorry, I'm completely out of ideas... All I can suggest is that you return your OLA and we will arrange a refund or replacement.

If you bought it from a distributor, please arrange a return/refund through them. If you bought it direct from SparkFun, please open a return ticket here: https://www.sparkfun.com/returns . Please cut and paste this link into the "Why do you want an RMA?" box: https://github.com/sparkfun/OpenLog_Artemis/issues/133

Many apologies for the inconvenience,
Paul

rglongoria, 2022-08-10:
Yes, will return. thanks

----------------------------------------------------
Raul G. Longoria, Ph.D., P.E. | Professor | Walker Department of Mechanical Engineering
The University of Texas at Austin | Austin, Texas 78712
http://sites.utexas.edu/longoria/
________________________________
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

PaulZC, 2022-08-10:
Closing... Please re-open if you need any more help with this.

Closed 2022-08-10.

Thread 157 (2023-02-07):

DMP quaternions drifting, but absolute acceleration not drifting

decamun, 2023-02-07:
### Subject of the issue
It seems that the DMP quaternions are drifting, even though the absolute acceleration reading is not.

### Your workbench
* Are you using a microSD card? Yes, 1GB, formatted out of the box from sparkfun
* At what frequency are you logging? 100Hz
* What version of firmware are you using? Artemis Openlog v1.11
* How is OpenLog Artemis wired to your sensor(s)? Board only
* How is everything being powered? USB-C
* Are there any additional details that may help us help you?

### Steps to reproduce
Here is a test script I put together to visualize the quaternions in real time.:

```
#Script adapted from: https://toptechboy.com/9-axis-imu-lesson-19-vpython-visualization-of-pitch-and-yaw/
from vpython import *
from time import *
import numpy as np
from scipy.spatial.transform import Rotation
import math
import serial
ad=serial.Serial('com4',115200)
sleep(1)

def is_number(n):
    try:
        float(n)   # Type-casting the string to `float`.
                   # If string is not a valid `float`,
                   # it'll raise `ValueError` exception
    except ValueError:
        return False
    return True

def check_packet_valid(packet):
    if len(packet) < 16:
        return False
    for n in packet:
        if not is_number(n):
            return False
    return True

def with_scalar_component(qs):
    qs_wr = np.asarray([*qs, np.sqrt(1.0 - np.sum(np.multiply(qs, qs)))]) # Real last
    qs_wr[np.isnan(qs_wr)] = 0
    return qs_wr

def rotated_vector(r, v):
    k=r.apply(v)
    return vector(k[0],k[1],k[2])

#setup VPython scene
scene.range=5
toRad=2*np.pi/360
toDeg=1/toRad
scene.forward=vector(1,-1,1)
scene.up=vector(0,0,-1)

scene.width=600
scene.height=600

frontArrowQuat=arrow(shaftwidth=.1,color=(color.red*0.5),axis=vector(1,0,0))
sideArrowQuat=arrow(shaftwidth=.1,color=(color.green*0.5),axis=vector(0,0,1))
upArrowQuat=arrow(shaftwidth=.1,color=(color.blue*0.5),axis=vector(0,1,0))

accArrow=arrow(shaftwidth=.1,color=(color.yellow*0.5),axis=vector(0,0,1))
magArrow=arrow(shaftwidth=.1,color=(color.purple*0.5),axis=vector(0,0,1))

#loop
while (True):
    while (ad.inWaiting()==0):
        pass
    dataPacket=str(ad.readline())
    splitPacket=dataPacket.split("'")[1].split(",")[:-1] #strip off unicode characters and split the string into a list

    #Log data to terminal
    print(str(splitPacket))

    if check_packet_valid(splitPacket):

        #Parse packet
        Q6_1=float(splitPacket[0])
        Q6_2=float(splitPacket[1])
        Q6_3=float(splitPacket[2])
        AX=float(splitPacket[7])
        AY=float(splitPacket[8])
        AZ=float(splitPacket[9])
        MX=float(splitPacket[13])
        MY=float(splitPacket[14])
        MZ=float(splitPacket[15])

        #Generate Quaternion
        Q6V = with_scalar_component([Q6_1, Q6_2, Q6_3])
        Q = Rotation.from_quat(Q6V)

        #Use Quaternion to rotate the unit vectors
        v1=rotated_vector(Q, np.array([1,0,0]))
        v2=rotated_vector(Q, np.array([0,1,0]))
        v3=rotated_vector(Q, np.array([0,0,1]))

        #Paint Quaternion unit vectors
        frontArrowQuat.axis=v1
        sideArrowQuat.axis=v2
        upArrowQuat.axis=v3

        #Paint abs acceleration and mag vector
        accArrow.axis=vector(AX,AY,AZ)
        accArrow.length = accArrow.length/10000
        magArrow.axis=vector(MX,MY,MZ)
        magArrow.length = magArrow.length/100
```

Here is my settings file:
```
sizeOfSettings=168
olaIdentifier=283
nextSerialLogNumber=4
nextDataLogNumber=136
usBetweenReadings=10000
logMaxRate=0
enableRTC=1
enableIMU=1
enableSD=1
enableTerminalOutput=1
logDate=0
logTime=0
logData=1
logSerial=1
logIMUAccel=1
logIMUGyro=1
logIMUMag=1
logIMUTemp=1
logRTC=1
logHertz=1
correctForDST=0
americanDateStyle=1
hour24Style=1
serialTerminalBaudRate=115200
serialLogBaudRate=9600
showHelperText=1
logA11=0
logA12=0
logA13=0
logA32=0
logAnalogVoltages=1
localUTCOffset=0
printDebugMessages=0
powerDownQwiicBusBetweenReads=0
qwiicBusMaxSpeed=100000
qwiicBusPowerUpDelayMs=250
printMeasurementCount=0
enablePwrLedDuringSleep=1
logVIN=0
openNewLogFilesAfter=0
vinCorrectionFactor=1.47
useGPIO32ForStopLogging=0
qwiicBusPullUps=1
outputSerial=0
zmodemStartDelay=20
enableLowBatteryDetection=0
lowBatteryThreshold=3.40
frequentFileAccessTimestamps=0
useGPIO11ForTrigger=0
fallingEdgeTrigger=1
imuAccDLPF=0
imuGyroDLPF=0
imuAccFSS=0
imuAccDLPFBW=7
imuGyroFSS=0
imuGyroDLPFBW=7
logMicroseconds=0
useTxRxPinsForTerminal=0
timestampSerial=0
timeStampToken=10
useGPIO11ForFastSlowLogging=0
slowLoggingWhenPin11Is=0
useRTCForFastSlowLogging=0
slowLoggingIntervalSeconds=300
slowLoggingStartMOD=1260
slowLoggingStopMOD=420
resetOnZeroDeviceCount=0
imuUseDMP=1
imuLogDMPQuat6=1
imuLogDMPQuat9=1
imuLogDMPAccel=1
imuLogDMPGyro=1
imuLogDMPCpass=1
minimumAwakeTimeMillis=0
identifyBioSensorHubs=0
```

### Expected behavior
The absolute accel vector remains aligned with the absolute Z axis in the visualization in a robust way. No matter how I move the board in real space, it keeps track of which way is down.

I would expect that when I use this script, the 'yaw axis' of the transformed coordinate system in the visualization should be roughly the same as the absolute accel vector. In other words, when I spin the board in real space, the rotated coordinate system in the visualization should roughly spin about the absolute accel vector in the visualization.

### Actual behavior
Manually spinning the board and watching the visualization, it is possible to see that initially the "yaw" axis of the board is aligned with the absolute acceleration vector as expected. Unfortunately over time it drifts such that spinning the board in real space causes it to rotate in other ways in the visualization.

As I mentioned, the absolute accel vector remains stable throughout this motion. (The absolute acceleration remains aligned with the absolute Z axis in the visualization, even if the board is rotated around in real space)

My conclusion is that the DMP does know which way is down, even when the quaternions have forgotten. In other words, it seems as if the Quat6 and Quat9 values are subject to drift over time that the DMP as a whole is not.

Another possibility is that my code is just broken.

Any thoughts?

PaulZC, 2023-02-07:
Hi Devin,

Drifting quaternions is not unexpected. The IMU gyros especially drift over time.

I don't have a full answer for you. The DMP is still a mystery in many ways. There is background information [here](https://github.com/sparkfun/SparkFun_ICM-20948_ArduinoLibrary/blob/main/DMP.md) that may be useful. If you look through the [open](https://github.com/sparkfun/SparkFun_ICM-20948_ArduinoLibrary/issues?q=is%3Aopen+is%3Aissue) and [closed](https://github.com/sparkfun/SparkFun_ICM-20948_ArduinoLibrary/issues/50) issues in the 20948 Library repo, you'll find similar issues being discussed.

All I can suggest is: try the actual Invensense code (try one of the 'wrappers' mentioned in the DMP.md doc.). If you see the same thing, you know it's the DMP drifiting. If it is better behaved, then that may provide clues about something that is not quite right with the DMP configuration in our Library.

Good luck!
Paul

PaulZC, 2023-03-02:
Hi Devin (@decamun),

I'm closing this as I really don't think there is any way I can (reasonably) correct this. It's either a 'feature' of the DMP itself, or we haven't quite got the DMP configured correctly in our library. Debugging the latter is not something I can take on anytime soon. Debugging the former is essentially impossible... Please re-open if you do manage to make any progress with this.

Best wishes,
Paul

Closed 2023-03-02.

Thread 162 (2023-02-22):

[Feature Request] Instructions for connecting a new sensor directly, bypassing the config/menu/autodetect

TangmereCottage, 2023-02-22:
**Problem** Although the firmware can be compiled, it is at present rather difficult to add a new sensor/actuator/servo/PWM output/GPIO, due to lack of documentation for the Mux/I2C/QWIIK system among other things.

**Use Case** I realize the device is conceived of as a simple logger with programming via the console rather than normal Arduino IDE, but the board itself is well specced and would be a great multipurpose board - integrated sd card, imu, bluetooth etc. (a PWM/GPIO breakout pin would be amazing but can deal with that via I2C).

**Request** Would it be possible to provide a short howto for bypassing **all** of the console/menu/autodetect code, and add a simple hardwired I2C sensor at a fixed address, such as the `u-blox_GNSS` at `0x42`?

PaulZC, 2023-02-23:
Hi @TangmereCottage ,

Please take a look at the Test Sketches:

https://github.com/sparkfun/OpenLog_Artemis/tree/main/Firmware/Test%20Sketches

They include most of the information you need. The GNSS_Data_Logging example shows how to read and log data from a u-blox GNSS. There is some information on BLE communication in issue #66. For PWM etc. please see the hook-up guides and code examples for our [Artemis boards](https://www.sparkfun.com/artemis). When developing code for the OLA, please select "RedBoard Artemis ATP" (All The Pins) as the board - the GPIO numbering is the same.

Best wishes,
Paul

Closed 2023-02-23.

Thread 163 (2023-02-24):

Hard faults on OLA and 'poisoned' ISM330DHCX

decamun, 2023-02-24:
### Subject of the issue
It seems that the ISM330DHCX sensors I'm using have been 'poisoned.' They were working with one OLA, but after a mysterious hard fault they no longer work, even with a second brand new OLA.

### Your workbench
* Are you using a microSD card?  No
* At what frequency are you logging? For example, 10Hz, 1Hz, once every 5 seconds, etc. Default
* What version of firmware are you using? Artemis OpenLog v2.5 (with some modifications)
* How is OpenLog Artemis wired to your sensor(s)? I have a ISM330DHCX breakout board connected to channel 0 of a Quiic Mux, connected to a brand-new Openlog Artemis.
* How is everything being powered? USB-C
* Are there any additional details that may help us help you?

### Steps to reproduce

This hard fault first popped up on a different Openlog Artemis I was using with slightly modified firmware, and a quick mux with two ISM330DHCX sensors connected (to different ports on the mux).

- This configuration had been working for about 10-20 power cycles with the same firmware.

- I connected two chains with an ICM 20948 sensor and a VL53L1X sensor on each to other ports on the mux. This appeared to cause the hard fault shown below.

- Once the fault happened, I removed the newly connected sensors, returning to the old configuration, but the fault persisted. Furthermore, the fault persists even with no sensors connected to the board.

- I also tried the original sensors (an ISM 330DHCX and a mux) on a brand new OLA board running totally unmodified firmware and the ICM330DHCX failed to initialize (detailed below).

I did disconnect the pull up resistor and swap the address connection on one of the ISM330DHCX sensors at some point during this process. However that was before the first occurrence of the hard fault, and even the unmodified  ISM330DHCX sensor no longer works.

Finally, it's worth noting that the two ICM IMUs and the two Lidars had worked in the past with the old OLA with the same firmware. The hard fault only appeared when both groups of sensors were connected.

### Expected behavior
I would expect the sensors to connect and log as normal, however it appears that the ISM330DHCX sensors I'm using have been 'poisoned'.

### Actual behavior

Log using first OLA:

Artemis OpenLog v2.5
Logging to: dataLog00090.TXT
Finding the next available log file.
This could take a long time if the SD card contains many existing log files.
Logging to: serialLog00000.TXT
SD card online
Data logging online
Serial logging online
IMU offline - or not present
Logging analog pins at max data rate
Identifying Qwiic Muxes...
Identifying Qwiic Devices...
Multiplexers found. Scanning sub nets...
Unknown device at address (0x7E)(Mux:0x70 Port:0)
Autodetect complete
IMU-ISM330DHCX online at address 0x6B.0x70.0
Multiplexer online at address 0x70
Content-Type: text/csv

rtcTime,VIN,aX,aY,aZ,gX,gY,gZ,dataRdy,output_Hz,

Menu: Main Menu
1) Configure Terminal Output
2) Configure Time Stamp
4) Configure Serial Logging
5) Configure Analog Logging
6) Detect / Configure Attached Devices
7) Configure Power Options
h) Print Sensor Helper Text (and return to logging)
s) SD Card File Transfer
r) Reset all settings to default
q) Quit: Close log files and power down
x) Return to logging
---- Sent utf8 encoded message: "x" ----
00:00:40.80,5.31,-5.73,-7.20,795.81,385.0,-647.50,-411.25,1,0.0,

++ MbedOS Fault Handler ++

FaultType: HardFault

Context:
R0: 1000C168
R1: 8
R2: 0
R3: 6F546F67
R4: 1000C168
R5: 61A80
R6: 0
R7: 100088A0
R8: 1
R9: 0
R10: 0
R11: 0
R12: 100088D8
SP   : 10008890
LR   : 280BD
PC   : 3C4E4
xPSR : 1000000
PSP  : 10008828
MSP  : 1005FF70
CPUID: 410FC241
HFSR : 40000000
MMFSR: 0
BFSR : 82
UFSR : 0
DFSR : 0
AFSR : 0
BFAR : 6F546F77
Mode : Thread
Priv : Privileged
Stack: PSP

-- MbedOS Fault Handler --

++ MbedOS Error Info ++
Error Status: 0x80FF013D Code: 317 Module: 255
Error Message: Fault exception
Location: 0x3C4E4
Error Value: 0x10007A68
Current Thread: main Id: 0x10005E44 Entry: 0x4E381 StackSize: 0x1000 StackMem: 0x10007AC8 SP: 0x10008890
For more info, visit: https://mbed.com/s/error?error=0x80FF013D&tgt=SFE_ARTEMIS_ATP
-- MbedOS Error Info --

Log using second (brand new) OLA:

SD init failed (second attempt). Is card present? Formatted?
Please ensure the SD card is formatted correctly using https://www.sdcard.org/downloads/formatter/
Config file read failed: SD offline
Artemis OpenLog v2.4
SD card offline
Datalogging offline
Serial logging offline
IMU online
Identifying Qwiic Muxes...
Identifying Qwiic Devices...
Known I2C address but device failed identification at address 0x6B
Unknown device at address (0x7E)
Autodetect complete
Device config file read failed: SD offline
Content-Type: text/csv

rtcDate,rtcTime,aX,aY,aZ,gX,gY,gZ,mX,mY,mZ,imu_degC,output_Hz,
01/01/2000,00:24:32.37,-49.32,-48.34,-985.35,0.86,-0.85,0.53,51.75,6.15,-24.15,27.50,100.0,
01/01/2000,00:24:32.46,-68.85,-37.60,-973.14,0.65,-6.76,3.12,51.15,6.30,-24.45,27.55,18.182,
01/01/2000,00:24:32.56,-63.96,-50.29,-983.40,-1.34,-0.52,1.76,51.15,7.50,-25.80,27.69,14.286,
01/01/2000,00:24:32.66,-67.38,-48.34,-972.66,-1.75,0.76,-1.73,51.0,6.15,-23.85,27.98,12.903,
01/01/2000,00:24:32.76,-61.04,-42.48,-988.77,2.42,-1.37,-0.26,50.55,6.15,-24.15,27.84,12.195,
01/01/2000,00:24:32.86,-60.55,-57.13,-982.91,-1.33,-1.51,-1.27,51.15,5.85,-25.20,27.89,11.765,
01/01/2000,00:24:32.96,-59.57,-51.27,-982.91,-1.26,-4.16,0.08,51.30,6.45,-23.85,27.79,11.475,
01/01/2000,00:24:33.06,-59.57,-46.39,-981.45,0.10,0.05,-0.91,49.80,5.70,-24.60,27.69,11.268,
01/01/2000,00:24:33.16,-57.13,-37.60,-977.05,-0.42,-8.01,1.62,51.30,6.15,-24.60,28.03,11.111,
01/01/2000,00:24:33.26,-62.01,-47.36,-983.89,-2.08,3.40,-2.95,50.70,7.80,-26.25,27.65,10.989,
01/01/2000,00:24:33.36,-54.69,-50.29,-987.30,-0.04,-1.57,3.02,50.70,7.80,-25.20,28.03,10.891,
01/01/2000,00:24:33.46,-72.75,-56.64,-980.96,1.31,-5.37,0.44,50.40,6.75,-25.80,27.89,10.811,
01/01/2000,00:24:33.56,-69.34,-51.76,-971.68,-2.59,-1.50,-1.02,51.90,5.85,-25.50,27.98,10.833,
01/01/2000,00:24:33.66,-65.43,-46.88,-1001.46,0.07,-7.59,0.25,49.50,6.90,-25.80,27.55,10.769,
01/01/2000,00:24:33.76,-46.39,-40.04,-978.03,-1.22,-1.53,0.14,51.30,6.90,-24.60,27.79,10.714,
01/01/2000,00:24:33.86,-71.78,-55.18,-993.65,0.75,-5.41,1.35,51.15,6.75,-24.75,27.89,10.667,
01/01/2000,00:24:33.96,-62.01,-58.11,-974.12,2.57,-2.66,0.17,51.15,6.75,-25.20,27.84,10.625,
01/01/2000,00:24:34.06,-70.80,-45.41,-988.28,-1.89,1.34,-0.10,51.15,5.85,-24.45,27.69,10.588,
01/01/2000,00:24:34.16,-60.06,-53.71,-992.19,1.05,-5.63,-0.43,51.0,8.10,-25.35,27.89,10.556,
01/01/2000,00:24:34.26,-64.45,-47.36,-980.96,-2.07,-2.58,1.73,51.15,5.85,-25.20,27.69,10.526,
---- Closed the serial port COM3 ----

decamun, 2023-02-24:
Update: strangely the first OLA, running modified v2.5 firmware, has seemingly recovered from the hard fault it suffered. It's now capable of identifying and reading from both ISM330DHCX sensors without the presence of a mux.

However, there appears to be a phantom device online at (0x7E).

In order to recover from the hard fault, I selected option (r) in the serial menu.

Log below:

SD init failed (second attempt). Is card present? Formatted?
Please ensure the SD card is formatted correctly using https://www.sdcard.org/downloads/formatter/
Config file read failed: SD offline
Artemis OpenLog v2.5
SD card offline
Datalogging offline
Serial logging offline
IMU online
Identifying Qwiic Muxes...
Identifying Qwiic Devices...
Unknown device at address (0x7E)
Autodetect complete
Device config file read failed: SD offline
IMU-ISM330DHCX online at address 0x6A
IMU-ISM330DHCX online at address 0x6B
Content-Type: text/csv

rtcDate,rtcTime,aX,aY,aZ,gX,gY,gZ,mX,mY,mZ,imu_degC,aX,aY,aZ,gX,gY,gZ,dataRdy,aX,aY,aZ,gX,gY,gZ,dataRdy,output_Hz,
01/01/2000,00:00:45.71,-221.19,-33.20,-2000.0,1.83,-0.37,0.56,-9.45,27.45,-3.90,25.78,4.39,-25.13,899.38,166.25,245.0,-78.75,1,7.81,-130.05,856.68,17.50,-542.50,-498.75,1,100.0,

decamun, 2023-02-24:
On the other hand, the brand new OLA is still not capable of initializing the unmodified ISM330DHCX

PaulZC, 2023-02-24:
Hi Devin (@decamun ),

I think you've somehow managed to corrupt the Artemis' flash memory? The message `Logging analog pins at max data rate` is worrying. That's not a default option - and it means the code is _only_ logging the analog pin voltages as fast as possible.

Please check the compiler messages. If your code is using more that 50% of the available program storage space, then you are probably hitting the bootloader issue we discussed in #154.

You new OLA is running firmware 2.4 - which doesn't support the ISM330. Support for that was added in v2.5. So that explains why that combination isn't working.

I've also seen the device at 0x7E issue. I don't know why, but the ISM330 does seem to have something inside it which responds to that address.

Best wishes,
Paul

PaulZC, 2023-02-24:
One more thing that might help:

The ICM20948 uses I2C addresses 0x68 and 0x69. That's only 1 bit different from the ISM330 at 0x6A and 0x6B. If the voltages on your I2C bus aren't quite right - maybe due to the pull-ups - then it might be possible for both devices to respond simultaneously, causing all kinds of badness...

PaulZC, 2023-02-24:
Ah. Another thing... If you added extra settings in your custom code, but haven't increased the software version number, then the original settings from the original 2.4 or 2.5 will still be in EEPROM. The data won't then align with your custom code and its settings. That would also cause all kinds of badness and might explain the `Logging analog pins` message. The r option resets all the settings - including your new additional settings - and so everything becomes aligned again.

PaulZC, 2023-03-02:
Hi Devin (@decamun ),

I'm closing this as I believe we understand why it is happening: the settings not being updated in EEPROM (a 'reset' will fix that); and your new OLA being 2.4 and not supporting the ISM330.

Please re-open if you need more help with this.

Best wishes,
Paul

Closed 2023-03-02.

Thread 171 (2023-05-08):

Issue - serial communication error with one non-standard "byte"

Gerard-E, 2023-05-08:
Hello,

Currently I'm working on a project where I need to log a serial protocol.
I'm talking about the LIN protocol, which is very similar to the UART protocol.

Similarities:
- Idle high
- Compatible baud rate 19k2
- 8N1 aka: low start bit, 8 data bits, high stop bit

Difference:
The first "byte" of a message is called a Break field, and consists of a low signal with a duration of 13 nominal bits times.
This Break field does not comply with the 8N1 serial standard.
_I've added a screenshot of the Break field specification at the end of this message._

The problem:
An FTDI cable to a PC as well as an Arduino Uno or Mega will read this Break field as 0x00.
The Artemis openlog does not seem to read this break field , but I do need it in my logging file.

Can this problem be solved in code or is this a limitation of the Appolo 3 chip?

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
Source: https://lin-cia.org/fileadmin/microsites/lin-cia.org/resources/documents/LIN-Spec_Pac2_1.pdf

PaulZC, 2023-05-08:
Hello @Gerard-E ,

I do not know how the MBED core and Apollo3 hardware responds to the break character. It may be possible to change the core so it records a NULL (0x00) like the Uno/Mega, but it would involve modifying the core at a very low level.

Does the OpenLog Artemis record any data from your LIN bus / device? Do you see valid data in the log file - except that the breaks are missing?

Could you use a Mega to convert the break field into an actual 0x00 byte - which the OLA can record? Connect your LIN bus / device to Serial1 RX. Connect Serial1 TX to the OLA. Be careful with the voltages - the original Arduino Mega is a 5V board. Use something like:

```
void setup()
{
  Serial1.begin(19200);
}

void loop()
{
  while (Serial1.available())
    Serial1.write(Serial1.read());
}
```

Best wishes,
Paul

PaulZC, 2023-06-27:
Closing. Please reopen if you need more help or advice with this issue.

Best wishes,
Paul

Closed 2023-06-27.

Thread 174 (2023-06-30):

Feature Request: Separate logging frequencies for different sensors

larswd, 2023-06-30:
### Subject of the issue
Me and @jerabaul29 desire to use the OpenLog Artemis with the [ISM330DHCX](https://www.sparkfun.com/products/19764) and [MAX-M10S GNSS Receiver](https://www.sparkfun.com/products/18037), and as mentioned in issue #172 we need a high frequency on the IMU logging capability.  As we plan to make many sensors with the same components, we will need the GPS to both know the location and  ensure that each sensor has an accurate time stamp available. Yet, we also do not need to do these measurements frequently and i would therefore be nice if we could be able to set different logging frequencies for the IMU and the GPS to preserve power and reduce the amount of unnecessary data being stored. Could this be done?

PaulZC, 2023-06-30:
Hi Lars (@larswd ),

No, sorry, that's essentially impossible with the existing firmware. The firmware is designed to sample all connected sensors, each in turn. Adding different "decimation rates" for each sensor type would be a huge change. I would encourage you to write your own firmware for the OLA, optimized to your individual needs.

Best wishes,
Paul

jerabaul29, 2023-06-30:
@PaulZC does this mean that one cannot log the GPS at 1Hz and the ISM330DHCX at 100HZ? Any idea of a workaround? Or is it "just fine" to log both at 100Hz, even if the GPS is actually updated at 10Hz only?

PaulZC, 2023-06-30:
You can set the GNSS to "auto". It will then report the most recent 'stale' fix if no fresh data is available. You can access this option through the "Detect / Configure Attached Devices" menu.

If you set the logging rate to 100Hz, the GNSS will be configured at the maximum rate of 10Hz.

jerabaul29, 2023-06-30:
Ok, thanks for the explanation :) . Is it already what you do @larswd ? :)

larswd, 2023-07-03:
Sorry for the late reply! Yes, that is the solution I have gone with thus far, and the only big drawback seems to be that we still are limitied in write speed, so we might have to pick and choose a bit in what we log. I will open a separate issue on higher baud rate to complement your request for a higher I^2C frequency request.

Closed 2023-06-30.

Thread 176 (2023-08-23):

Feature Request: log negative weights from loadcell-nau7802

gmkado, 2023-08-23:
### Subject of the issue
I can't get my loadcell to work with openlog artemis.  Not sure if its due to the load cell reporting negative raw values, but I'm just getting empty entries (not zeros in compression + values in tension like I would expect if that were the case).  Read on for details

### Your workbench
* Are you using a microSD card? If so, what size? How is it formatted (FAT, FAT32, or exFat)?
No microSD
* At what frequency are you logging? For example, 10Hz, 1Hz, once every 5 seconds, etc.
Tried 10Hz and 1Hz
* What version of firmware are you using? This is shown at boot, for example: "Artemis OpenLog v1.10"
v2.4

* How is OpenLog Artemis wired to your sensor(s)?
I have the following connections:
    - OLA hooked up to my laptop via USB-C
    - OLA to SEN board via qwiic connector
    - Wires from SEN board to load cell using color code:
Input: Red wire(+), Black wire(-)
Output: Green wire(+), White wire(-)

* How is everything being powered?
Via the usb-c from my laptop

* Are there any additional details that may help us help you?
My shopping cart:
- [1568-SEN-15242-ND](https://www.digikey.com/en/products/detail/sparkfun-electronics/SEN-15242/10064419)
- [1568-DEV-16832-ND](https://www.digikey.com/en/products/detail/sparkfun-electronics/DEV-16832/13166206)
- https://www.amazon.com/dp/B077YHNNCP?psc=1&ref=ppx_yo2ov_dt_b_product_details

### Steps to reproduce

Make all connections and open serial port using arduino IDE.

One strange thing to note, initially in the weight field I was getting weird characters like ⸮.  So I initially thought it was a text encoding issue, (but everything else was printing out fine).  So I tried another serial port monitor that allowed me to change the encoding to e.g. UTF-8, 16, etc but nothing there worked.

After that I tried removing datalogging, and I think at that point it stopped printing out weird characters and just prints out empty entries like in the snippet below.  So I thought it might be a rate issue and slowed the polling down to 1Hz.  I also tried the baud rate at 115200 and 9600, made no difference.

### Expected behavior
Values are logged in the "weight" column of the output

### Actual behavior
This is what's logged:
```
SD init failed (second attempt). Is card present? Formatted?
Please ensure the SD card is formatted correctly using https://www.sdcard.org/downloads/formatter/
Config file read failed: SD offline
Artemis OpenLog v2.4
SD card offline
Datalogging offline
Serial logging offline
IMU offline - or not present
Identifying Qwiic Muxes...
Identifying Qwiic Devices...
Autodetect complete
Device config file read failed: SD offline
LoadCell-NAU7802 online at address 0x2A
Content-Type: text/csv

rtcDate,rtcTime,weight(no unit),output_Hz,
01/01/2000,02:29:14.04,,100.0,
01/01/2000,02:29:15.05,,1.961,
01/01/2000,02:29:16.05,,1.485,
01/01/2000,02:29:17.06,,1.320,
01/01/2000,02:29:18.06,,1.241,
01/01/2000,02:29:19.07,,1.190,
01/01/2000,02:29:20.07,,1.159,
01/01/2000,02:29:21.08,,1.135,
```

I also ran [this example](https://github.com/sparkfun/SparkFun_Qwiic_Scale_NAU7802_Arduino_Library/tree/master/examples/Example3_Gain_SampleRate) off a spare arduino and am able to see the values update.

This led me to discover I was getting zeros for "compression" and actual values for "tension", which led me to this [forum post](https://forum.sparkfun.com/viewtopic.php?t=55611), which led me here.

Following the advice on that post, I changed the "allowNegativeWeights" to true in the sketch, and I get the following output:
```
Reading: -190173	Weight: 1.73	AvgWeight: 1.71	Scale not calibrated. Press 'c'.
Reading: -192422	Weight: 1.71	AvgWeight: 1.71	Scale not calibrated. Press 'c'.
Reading: -188475	Weight: 1.70	AvgWeight: 1.72	Scale not calibrated. Press 'c'.
Reading: -184800	Weight: 1.68	AvgWeight: 1.71	Scale not calibrated. Press 'c'.
Reading: -183763	Weight: 1.64	AvgWeight: 1.68	Scale not calibrated. Press 'c'.
Reading: -179378	Weight: 1.59	AvgWeight: 1.65	Scale not calibrated. Press 'c'.
Reading: -172773	Weight: 1.57	AvgWeight: 1.62	Scale not calibrated. Press 'c'.
Reading: -172112	Weight: 1.55	AvgWeight: 1.59	Scale not calibrated. Press 'c'.
```
(Side note, I could not get the scale calibration to "pass", it always says scale not calibrated...)

So I went back to the OLA and thought maybe it would log data if I kept it in tension (aka positive values) but that doesn't seem to work.

Would appreciate any help getting this thing to log.  Thanks!

PaulZC, 2023-08-23:
Hi @gmkado ,

You need to calibrate the NAU7802 through the OpenLog Artemis menus.
Open the serial Menu and select option 6 "Detect / Configure Attached Devices".
Select the NAU7802 from the list.
From the NAU7802 sub-menu, select option 2 "Calibrate Scale".
It will guide you through setting the zero point and then calibrating with a known weight.

Unfortunately you need to do this each time the OLA restarts. The firmware is not able to save the zero point and calibration factor - as this depends on whether the NAU7802 is connected through a mux. The [DataLogger IoT](https://www.sparkfun.com/products/20594) is able to save the configuration - but currently does not support muxes...

Let me know if you need more help.

Best wishes,
Paul

PaulZC, 2023-08-23:
OK. I just saw your Forum post:

https://forum.sparkfun.com/viewtopic.php?p=243322#p243322

I will change this to a "negative weight" feature request.

gmkado, 2023-08-26:
@PaulZC thanks for the help!  I just tried what you suggested but I can't get past the sensor menu:
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

Pressing `1` and `enter` doesn't do anything.  Any idea why?

Also regarding this statement:
> Unfortunately you need to do this each time the OLA restarts. The firmware is not able to save the zero point and calibration factor - as this depends on whether the NAU7802 is connected through a mux. The [DataLogger IoT](https://www.sparkfun.com/products/20594) is able to save the configuration - but currently does not support muxes..

Does this mean I can save calibration If I'm not using a mux?  Also, there's no way to just log the raw values?

PaulZC, 2023-08-27:
Hi,

For the sensor menu: check your line endings (how you have the enter key configured). If you are using the Arduino IDE Serial Monitor, set the line ending to Newline. If you are using a terminal emulator, dig around in the settings for new-line. You need to send a New Line '\n' (ASCII 10 (decimal)) - or Carriage Return '\r' (ASCII 13 (decimal)) - or both. (Some menus respond to a single character - the '1' on its own. Some need the terminator. That menu needs the terminator.)

Sorry, no, you cannot save the calibration at all at present. To do it properly, the firmware would need to record the mux address and port (if connected), or NULL values if connected on the main I2C bus. That requires new code... You could 'cheat' and record the zero point and calibration factor for _only_ a single device on the main bus. That would be much easier but again still requires new code. Sorry, no, it is not possible to record raw values.

Best wishes,
Paul

gmkado, 2023-08-28:
Okay so it seems like the OLA in its current implementation won't work for my application since it requires some user interaction on power cycle.

I'm going to switch to using the [pro-micro ](https://www.sparkfun.com/products/15795) along with the [arduino library](https://github.com/sparkfun/SparkFun_Qwiic_Scale_NAU7802_Arduino_Library/tree/master).  You can close this ticket

PaulZC, 2024-02-26:
Hi @gmkado ,

It may be too little too late, but this issue is resolved in firmware v2.6. I found a bug which was preventing the NAU7802 from being configured correctly when connected through a mux. This is now resolved. And you can log negative weights too. The configuration for each device is stored on SD Card and is now restored correctly on power-up or wake. Please check the v2.6 release notes for more details.

Best wishes,
Paul

Closed 2024-02-26.

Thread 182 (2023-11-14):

Trouble with logging serial data

HolgerSiebert, 2023-11-14:
### Subject of the issue
Hello, I want to log some serial ascii data at baudrate of 115200 including a time stamp. When the data source is already running before the OLA has been started, OLA is crashing with the following message:

 ++ MbedOS Error Info ++
Error Status: 0x80FF0144 Code: 324 Module: 255
Error Message: Assertion failed: handle != NULL
Location: 0x49DBD
File: mbed-os/targets/TARGET_Ambiq_Micro/TARGET_Apollo3/device/serial_api.c+411
Error Value: 0x0
Current Thread: main Id: 0x10007E4C Entry: 0x4AF11 StackSize: 0x1000 StackMem: 0x10006E28 SP: 0x1005FEEC
For more info, visit: https://mbed.com/s/error?error=0x80FF0144&tgt=SFE_ARTEMIS_ATP
-- MbedOS Error Info --

If I start the data source after OLA is already running and storing data, it works more or less reliable (with a few other issues I will come back later)

### Your workbench
* SC Card is a " 32GB extreme pro"  formatted with exFAT (1024 kb units)
* I log data at 50 Hz
* firmware is v2.4
* How is OpenLog Artemis wired to your sensor(s)? serial data source is wired via a MAX232 (RS232 =>logic) at OLA PIN RX, MAX232 is powered by OLA (3.3V), other devieces via
* How is everything being powered? OLA is powered via USB-C; serial decive is powerd by USB, all on common GND
* Are there any additional details that may help us help you? Other QwiicDevices are:

### Steps to reproduce
sizeOfSettings=168
olaIdentifier=292
nextSerialLogNumber=0
nextDataLogNumber=0
usBetweenReadings=20000
logMaxRate=0
enableRTC=1
enableIMU=0
enableTerminalOutput=0
logDate=1
logTime=1
logData=1
logSerial=1
logIMUAccel=0
logIMUGyro=0
logIMUMag=0
logIMUTemp=0
logRTC=1
logHertz=0
correctForDST=0
dateStyle=0
hour24Style=1
serialTerminalBaudRate=115200
serialLogBaudRate=115200
showHelperText=1
logA11=0
logA12=1
logA13=0
logA32=1
logAnalogVoltages=1
localUTCOffset=0.00
printDebugMessages=1
powerDownQwiicBusBetweenReads=0
qwiicBusMaxSpeed=100000
qwiicBusPowerUpDelayMs=250
printMeasurementCount=1
enablePwrLedDuringSleep=1
logVIN=0
openNewLogFilesAfter=10
vinCorrectionFactor=1.47
useGPIO32ForStopLogging=0
qwiicBusPullUps=1
outputSerial=0
zmodemStartDelay=5
enableLowBatteryDetection=0
lowBatteryThreshold=3.40
frequentFileAccessTimestamps=0
useGPIO11ForTrigger=0
fallingEdgeTrigger=1
imuAccDLPF=0
imuGyroDLPF=0
imuAccFSS=0
imuAccDLPFBW=7
imuGyroFSS=0
imuGyroDLPFBW=7
logMicroseconds=0
useTxRxPinsForTerminal=0
timestampSerial=1
timeStampToken=10
useGPIO11ForFastSlowLogging=0
slowLoggingWhenPin11Is=0
useRTCForFastSlowLogging=0
slowLoggingIntervalSeconds=300
slowLoggingStartMOD=1260
slowLoggingStopMOD=420
resetOnZeroDeviceCount=0
imuUseDMP=0
imuLogDMPQuat6=1
imuLogDMPQuat9=0
imuLogDMPAccel=0
imuLogDMPGyro=0
imuLogDMPCpass=0
minimumAwakeTimeMillis=0
identifyBioSensorHubs=0
serialTxRxDuringSleep=0
printGNSSDebugMessages=0
openMenuWithPrintable=0

### Expected behavior
Even if serial device is already running when powering up OLA (or rest OLA) I expect data to be logged

### Actual behavior

OLA does not start logging but stops with the following message:

 ++ MbedOS Error Info ++
Error Status: 0x80FF0144 Code: 324 Module: 255
Error Message: Assertion failed: handle != NULL
Location: 0x49DBD
File: mbed-os/targets/TARGET_Ambiq_Micro/TARGET_Apollo3/device/serial_api.c+411
Error Value: 0x0
Current Thread: main Id: 0x10007E4C Entry: 0x4AF11 StackSize: 0x1000 StackMem: 0x10006E28 SP: 0x1005FEEC
For more info, visit: https://mbed.com/s/error?error=0x80FF0144&tgt=SFE_ARTEMIS_ATP
-- MbedOS Error Info --

PaulZC, 2023-11-15:
Hi @HolgerSiebert ,

It's not clear to me if this is an issue with the Apollo3, or the OLA firmware, or perhaps a strange power issue from the way you have the MAX232 connected. I will try some tests, but it will be difficult for me to fully replicate your set-up.

Question: are you using a MAX232, or a MAX3232? The MAX232 is, IIRC, a 5V-only part. The MAX3232 can operate from +3.0V to +5.5V.

Best wishes,
Paul

PaulZC, 2024-02-19:
Closing... Please re-open if you need more help with this issue.

Best wishes,
Paul

PaulZC, 2024-03-04:
Reopening...

Another user reported the same issue here: https://forum.sparkfun.com/viewtopic.php?p=247614#p247614

The root cause of the crash is serial data arriving after the ```Serial1.end``` [here](https://github.com/sparkfun/OpenLog_Artemis/blob/8ad4b4046e08621908869a5034efe38322bf789d/Firmware/OpenLog_Artemis/OpenLog_Artemis.ino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), and before ```Serial1``` is restarted by ```beginSerialLogging``` [here](https://github.com/sparkfun/OpenLog_Artemis/blob/8ad4b4046e08621908869a5034efe38322bf789d/Firmware/OpenLog_Artemis/OpenLog_Artemis.ino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).

v2.7_BETA will be available shortly.

PaulZC, 2024-03-04:
Please try the 2.7 BETA firmware available [here](https://github.com/sparkfun/OpenLog_Artemis/tree/main/Binaries) and [here](https://github.com/sparkfun/OpenLog_Artemis/blob/main/Binaries/OpenLog_Artemis-V10-v27_BETA.bin)

Upgrade instructions are [here](https://github.com/sparkfun/OpenLog_Artemis/blob/main/UPGRADE.md)

PaulZC, 2024-03-05:
Hi @HolgerSiebert ,

Apologies for the slow response. This is resolved in [v2.7](https://github.com/sparkfun/OpenLog_Artemis/releases/tag/v2.7).

Best wishes,
Paul

Closed 2024-03-05.

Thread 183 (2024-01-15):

Wrong raw sensor units when DMP enabled

oriolcase, 2024-01-15:
I am working with a SparkFun OpenLog Artemis (OLA) IMU (https://learn.sparkfun.com/tutorials/openlog-artemis-hookup-guide/all). And I have an issue when enabling the Digital Motion Processor (DMP).

I already know that when the DMP is disabled, sensor raw data is in mili-g, degrees per second and uT, for accelerometer, gyroscope and magnetomenter (https://github.com/sparkfun/OpenLog_Artemis/blob/main/SENSOR_UNITS.md#ICM-20948-IMU). However, when DMP is enabled, these units seem to change to an unknown units.

Here I paste data from two IMUs, both working at 10Hz. At the moment of the data collection, both units are at rest, horizontal in the XY-plane. So the expected values from accelerometer are the gravity in the z axis, and values around 0 in x and y axes. From the gyroscope expected values are around 0 in all axes, and from magnetometer whatever the magnetic field had the Earth in that moment.
(The same effect is produced if the configurations are reversed between the two devices).

_DMP enabled_
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

_DMP disabled_
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

Does anyone know what has changed in the raw data from the three sensors? Are these units known? This is happening whenever the DMP is activated, independently of whether the quaternions are calculated from accel, gyro and magnet or only from accel and gyro.

My final objective is to be able to calculate the IMU's attitude from the sensors, in order to compare it with DMP quaternion values, to see which form is more suitable for my use. Therefore, I need to know in which units the accelerometer, gyroscope and magnetometer data are stored.

PaulZC, 2024-01-16:
Hi @oriolcase ,

Welcome to the weird and wonderful world of the ICM20948 DMP!

The accelerometer full scale can be set to 2, 4, 8 or 16g. With the DMP disabled, the ICM20948 library uses a default of 2g. Internally, it correctly converts the accelerometer values into milli-g based on the full scale. If you set the full scale to 16g, the milli-g is still correct.

When the DMP is enabled, the full scale is set to 4g. When reading the raw accel values, the library does not perform any scaling, it simply returns whatever is output by the DMP.

The only clue about the units in the confidential DMP application note is "Accel data: Hardware unit, 2 bytes for each axis, X, Y and Z in order.". Likewise, the magnetometer is "hardware units" too.

I suspect that if you divide the raw accel values by 8192, you will end up with g. Or divide by 8.192 for milli-g. But that's just a hunch.

For the magnetometer, I really don't know. Looking at the AK09916 datasheet, a measurement of 32752 represents 4912 micro-Tesla. Maybe if you divide the RawM values by 6.6678 you get back to the non-DMP m values?

I hope this helps.

I am closing this as I think I have given you all the help I can.

Best wishes,
Paul

Closed 2024-01-16.

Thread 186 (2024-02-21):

BMA400

shanemc1982, 2024-02-21:
Subject of the issue
Please consider adding support for [BMA400 ](https://www.sparkfun.com/products/21207)Micro Triple Axis Accelerometer Breakout for OLA. I see that the module already contains an Arduino library at https://github.com/sparkfun/SparkFun_BMA400_Arduino_Library .

This sensor has the capability of detecting specific movement types such as walking, running and standing still. This would be useful to compare along with the raw accelerometer data in a logging situation

Expected behavior
When the BMA 400 QWIIC board is plugged in, the OLA log data include the data from the secondary sensor.

Actual behavior
When the BMA 400 QWIIC board is plugged in, the log data says "unknown device present at address 0x14" and does not log any data from the sensor.

PaulZC, 2024-02-21:
Hi @shanemc1982 ,

Thank you for the interest in these products. But, unfortunately, adding the BMA400 is not something we can do at present. It has a ton of options and would require a lot of additional code. Please see #148 .

You could add it yourself and send us a Pull Request. Details are [here](https://github.com/sparkfun/OpenLog_Artemis/blob/main/ADDING_SENSORS.md). To help, there will be a docker file included in v2.6. There will also be GitHub workflow actions which will compile the firmware for you too. v2.6 should be available tomorrow.

Best wishes,
Paul

shanemc1982, 2024-03-22:
Thank you Paul for this. I am attempting this now but i am struggling unfortunately. Dos other thing need to be done as well as the items at the link you provided. I was hoping to be able to link the current sparkfun BMA400 library to this. is this possible

PaulZC, 2024-03-22:
Hi @shanemc1982 ,

Start with the unmodified code. Can you get it to compile successfully, following [these instructions](https://github.com/sparkfun/OpenLog_Artemis/blob/main/COMPILE_BINARY.md)? Then start adding the new code for the BMA 400...

I hope this helps,
Paul

shanemc1982, 2024-03-22:
I will try this from scratch again and see how things go. Thank you . I may come back to you again.

PaulZC, 2024-03-22:
Hi @shanemc1982 ,

I don't have time to look at this. All I can do is give you a few pointers.

The first couple of errors are caused by FALSE and TRUE being defined in both the OLA code (zmodem.ino I think) and the bma400 library. They are just warnings so you are probably OK. But you may need to change one or the other. It will be easiest to change the OLA code if you do.

The next few errors are about struct_BMA400. Check you have updated settings.h correctly and have included the new struct for the BMA400.

The beginI2C error is caused by you not calling beginI2C correctly. It looks like you need to use ```temp->online = tempDevice->beginI2C(i2cAddress, qwiic); //Wire port``` and delete the calls to ```setI2CAddress```.

Hope this helps,
Paul

shanemc1982, 2024-03-22:
Thank you for your help. I understand that you are busy. I will try those suggestions and see how things go. hopefully they will sort most of the issues

shanemc1982, 2024-03-26:
Hi Paul,

I uncommented that line as suggested and logging to sdcard seems to be working. Your help is much appreciated.

Regards

Shane

shanemc1982, 2024-03-26:
[OpenLog_Artemis BMA400 added.zip](https://github.com/sparkfun/OpenLog_Artemis/files/14760003/OpenLog_Artemis.BMA400.added.zip)
Attached is the code that i have modified to add the BMA400. It seems to be working. Not sure how it can be added to openlog main branch. Maybe needs more code written but it working for me

Closed 2024-02-21.

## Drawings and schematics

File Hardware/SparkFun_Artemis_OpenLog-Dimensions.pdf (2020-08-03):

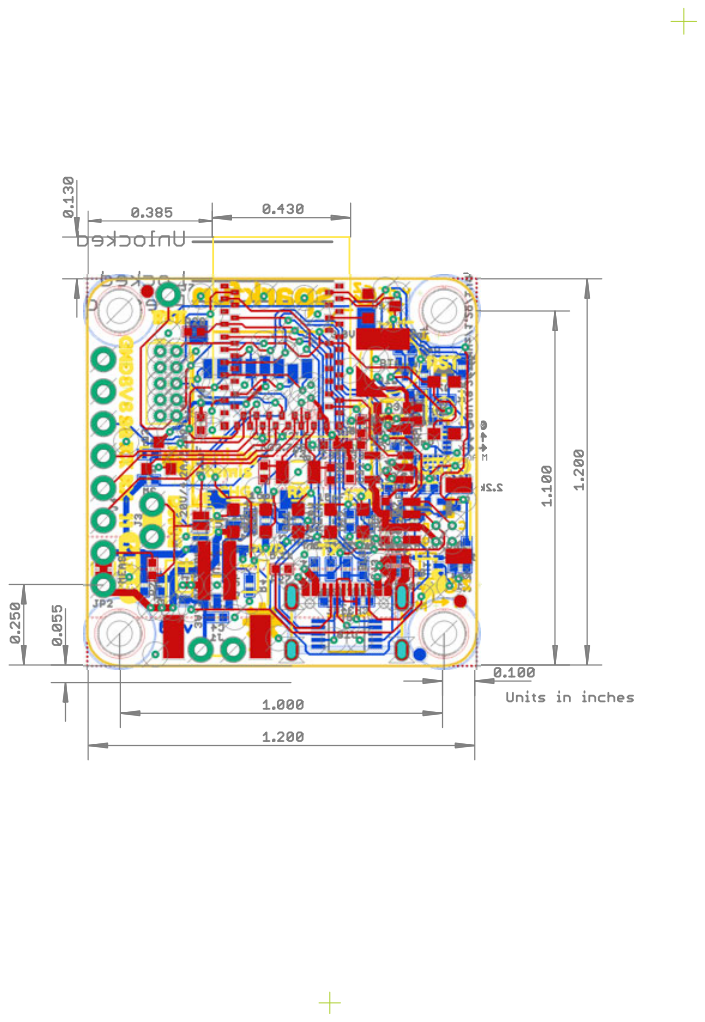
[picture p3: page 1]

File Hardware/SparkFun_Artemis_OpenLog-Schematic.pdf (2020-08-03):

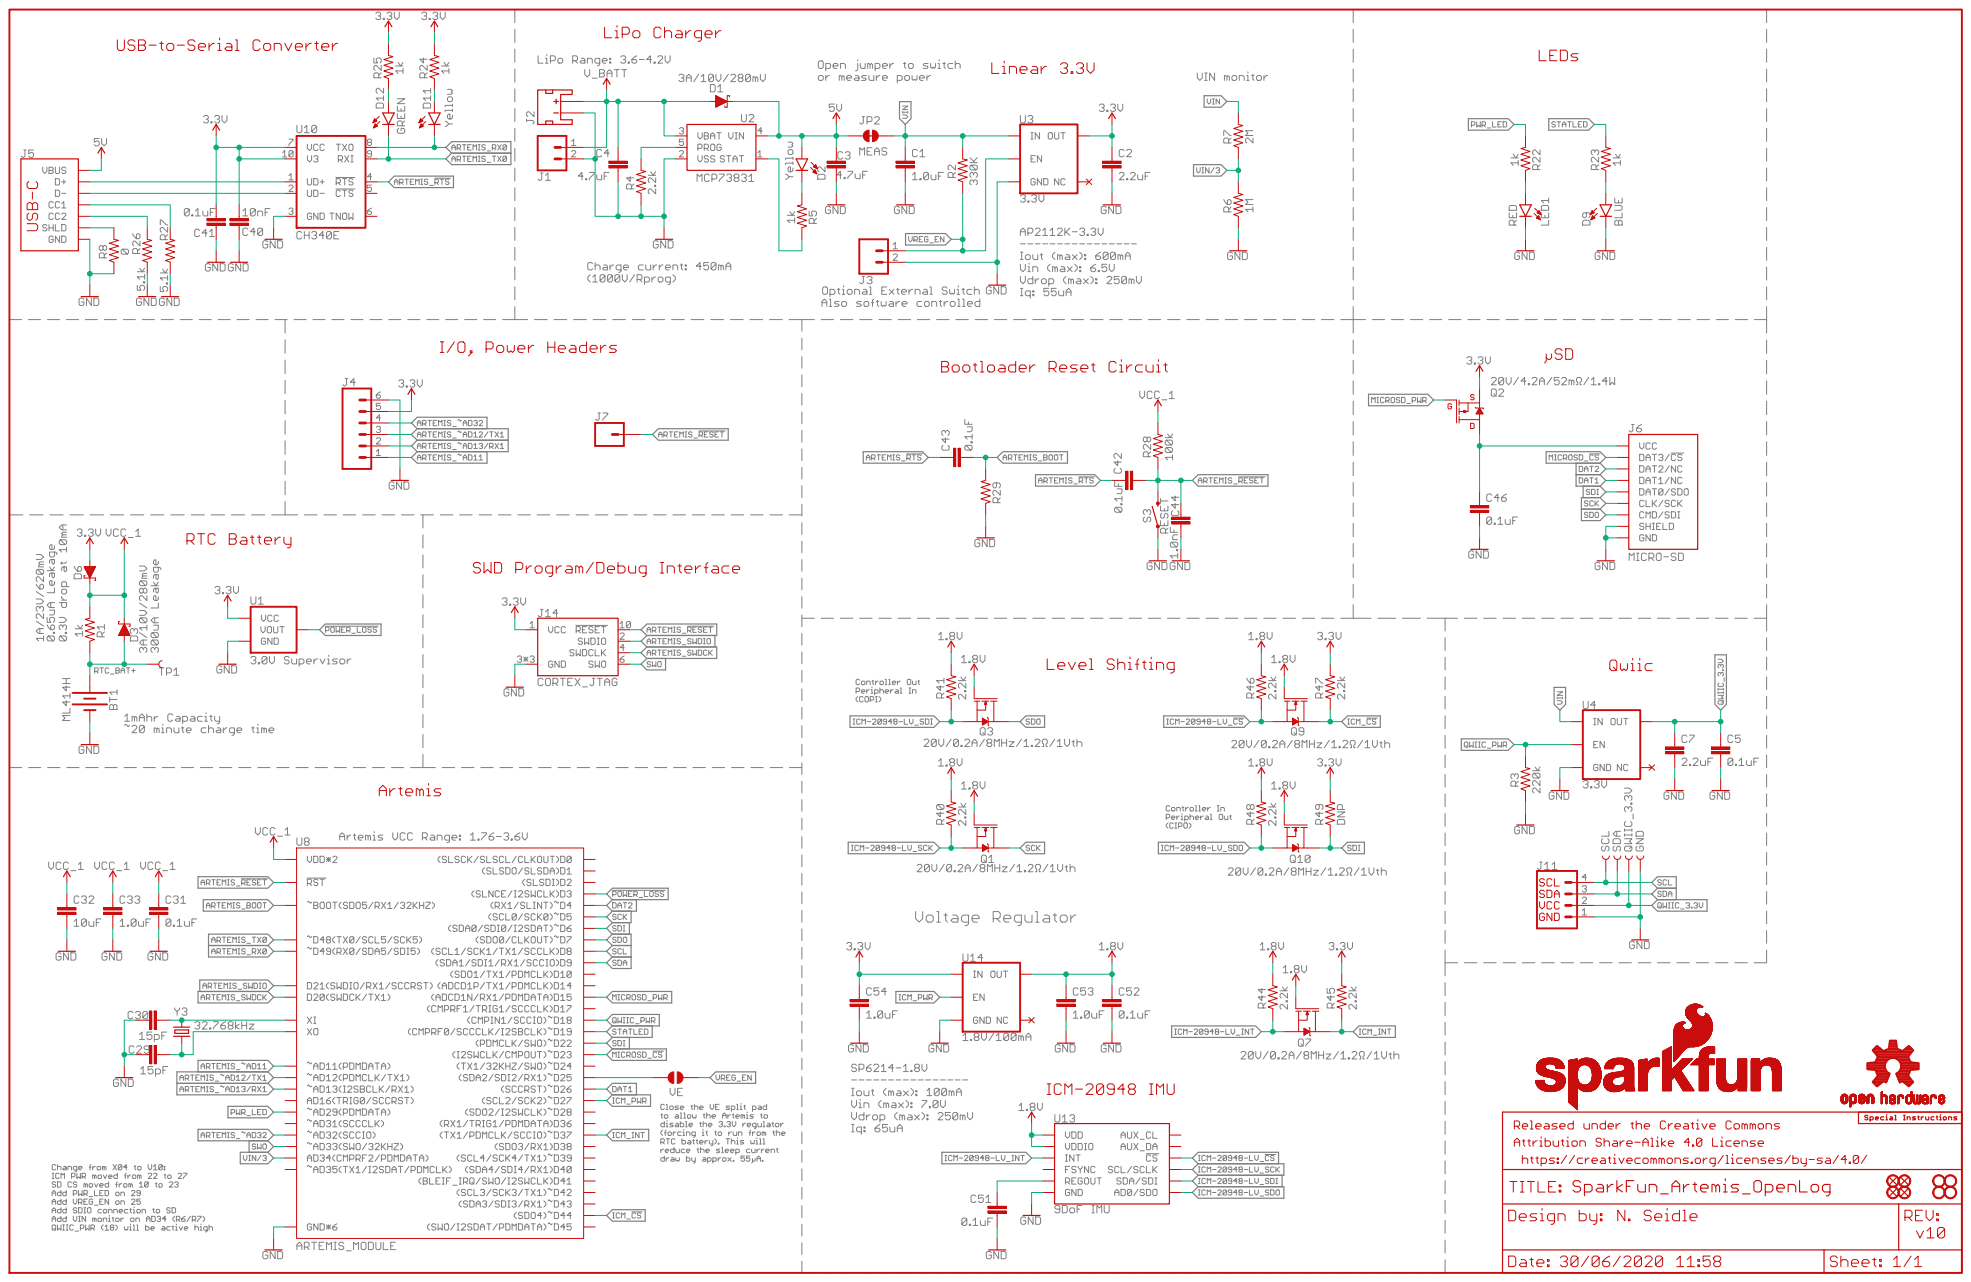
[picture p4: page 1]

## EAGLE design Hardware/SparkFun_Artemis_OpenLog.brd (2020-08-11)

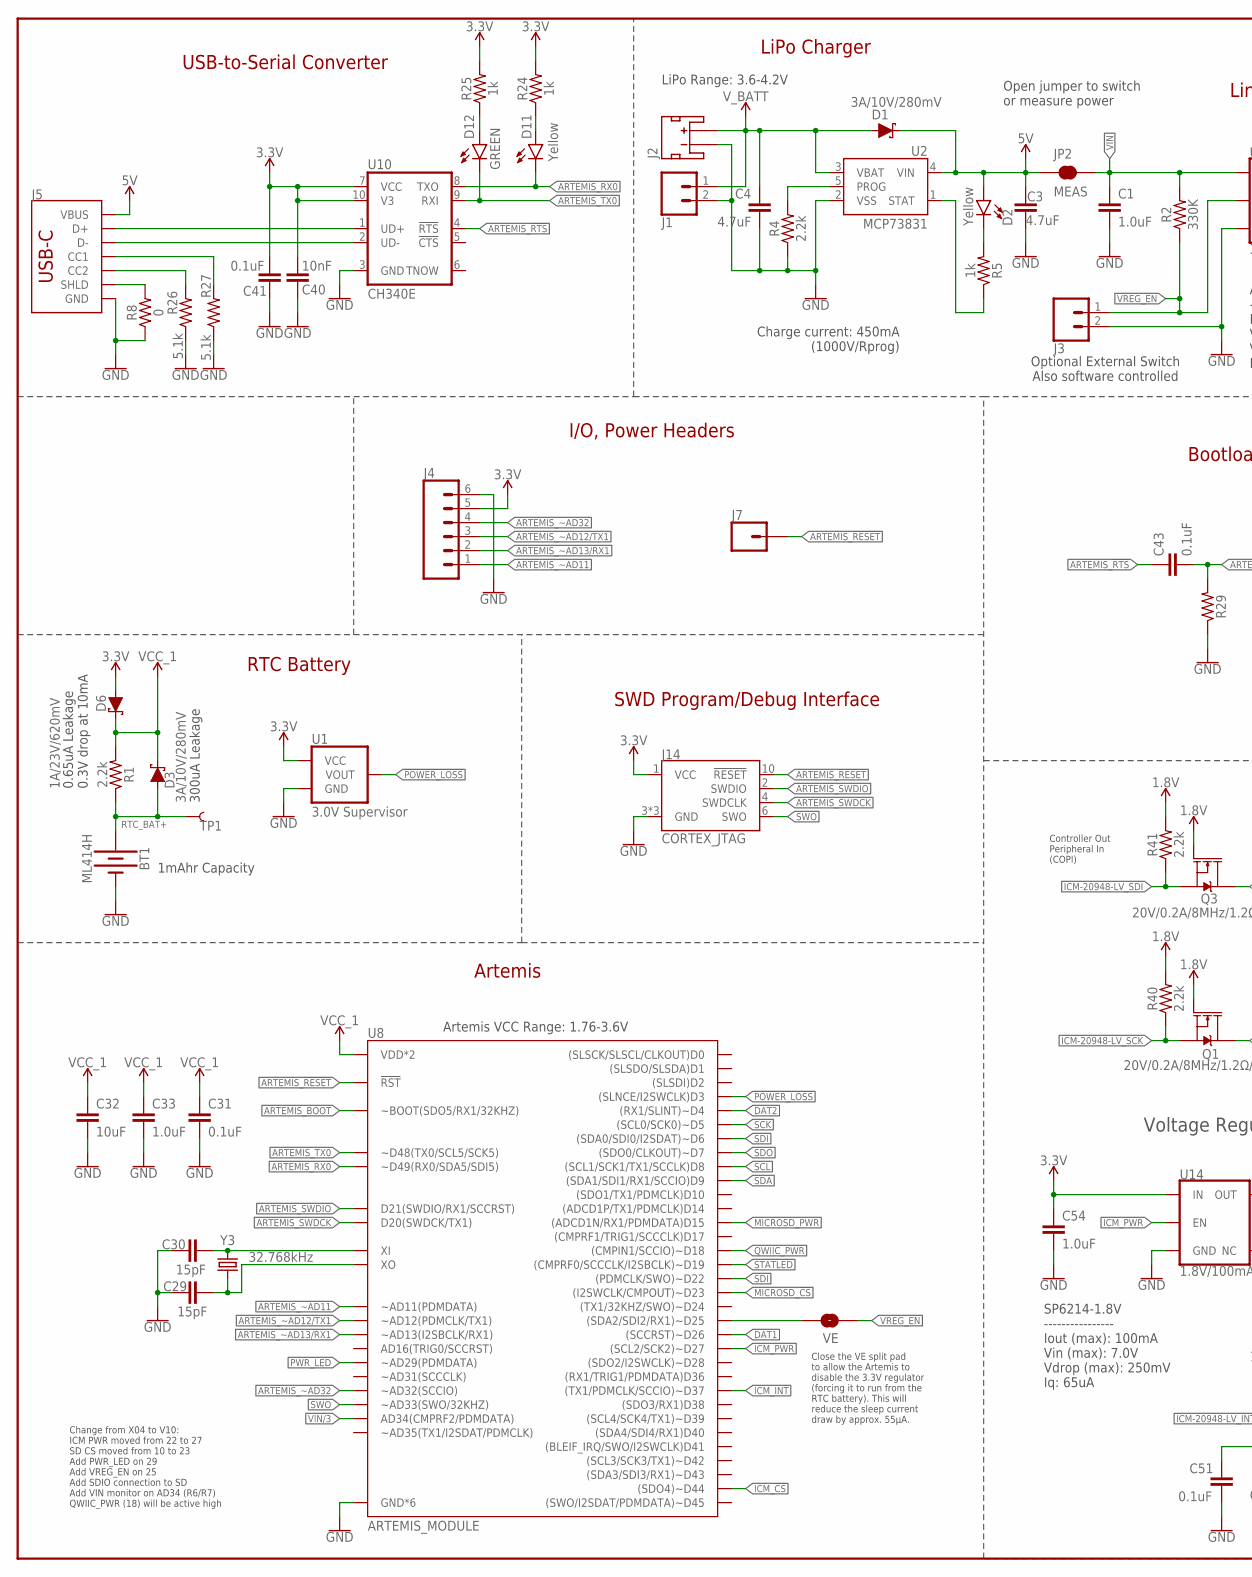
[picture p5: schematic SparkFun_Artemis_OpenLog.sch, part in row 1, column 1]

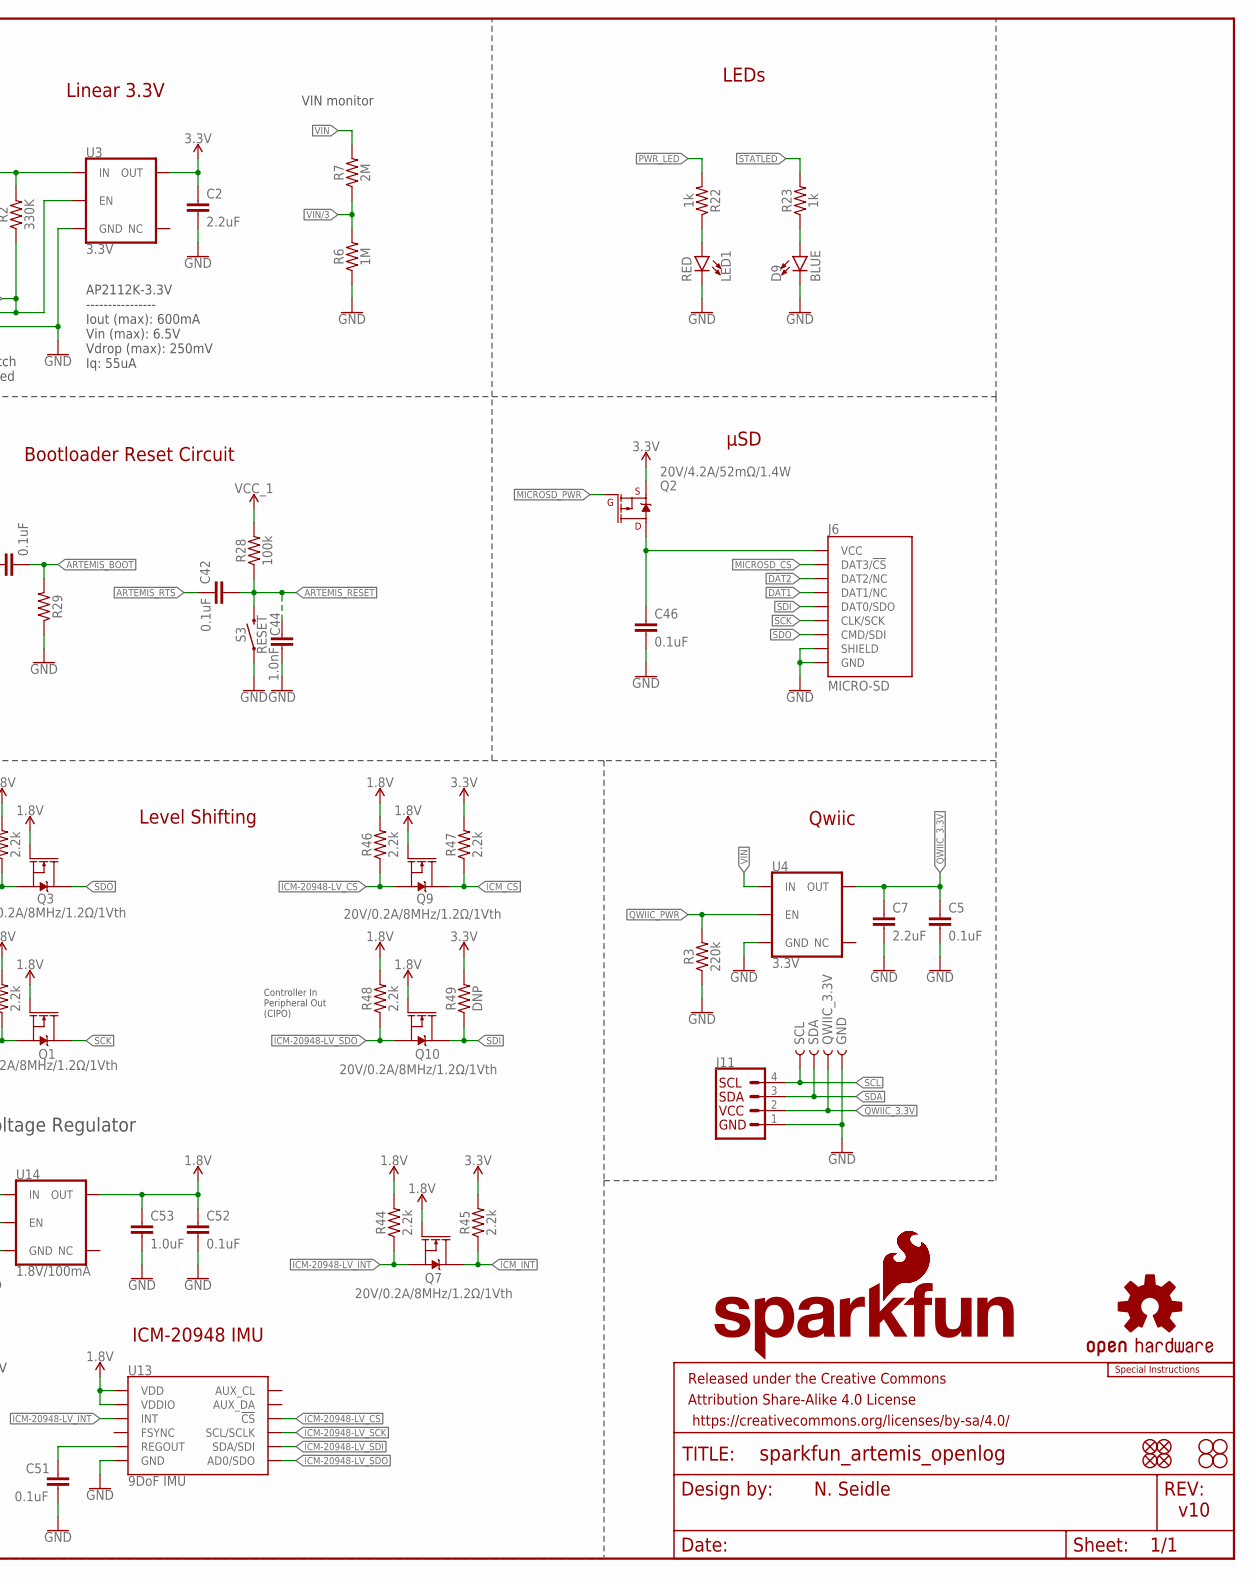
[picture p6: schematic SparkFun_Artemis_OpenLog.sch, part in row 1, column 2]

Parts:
BT1: ML414H; ML414H_IV01E
C1, C33, C53, C54: 1.0uF; 0402-TIGHT
C2, C7: 2.2uF; 0402-TIGHT
C3, C4: 4.7uF; 0402-TIGHT
C5, C31, C41, C42, C43, C46, C51, C52: 0.1uF; 0402-TIGHT
C29, C30: 15pF; 0402-TIGHT
C32: 10uF; 0402-TIGHT
C40: 10nF; 0402-TIGHT
C44: 1.0nF; 0402-TIGHT
D1, D3: 3A/10V/280mV; SOD-323
D2, D11: Yellow; LED-0603
D6: 1A/23V/620mV; SOD-323
D9: BLUE; LED-0603
D12: GREEN; LED-0603
FD1, FD2, FD3, FD4: FIDUCIAL1X2; FIDUCIAL-1X2
FRAME1: FRAME-LEDGER; CREATIVE_COMMONS
GND: TEST-POINTTP_15TH_THRU; TP_15TH
H1, H2, H3, H4: STAND-OFF
J1, J3: CONN_021X02_NO_SILK; 1X02_NO_SILK
J2: JST_2MM_MALE; JST-2-SMD
J4: CONN_06NO_SILK_NO_POP; 1X06_NO_SILK
J5: USB_C_4-LAYER_PADS; USB-C-16P_4LAYER-PADS
J6: MICRO-SD; MICRO-SD-SOCKET
J7: CONN_01PTH_NO_SILK_YES_STOP; 1X01_NO_SILK
J11: QWIIC_CONNECTORJS-1MM; JST04_1MM_RA
J14: CORTEX_JTAG; 2X5-PTH-1.27MM
JP2: MEAS; COMBO-JUMPER_2_NC_TRACE
LED1: RED; LED-0603
LOGO1: SFE_LOGO_NAME.1_INCH; SFE_LOGO_NAME_.1
LOGO2: OSHW-LOGOS; OSHW-LOGO-S
LOGO3: SPECIAL_INSTRUCTIONS-ORDERING; ORDERING_INSTRUCTIONS
LOGO4, LOGO5: SFE_LOGO_FLAME.1_INCH; SFE_LOGO_FLAME_.1
Q1, Q3, Q7, Q9, Q10: 20V/0.2A/8MHz/1.2Ω/1Vth; SOT-416FL
Q2: 20V/4.2A/52mΩ/1.4W; SOT23-3
QWIIC_3.3V: TEST-POINTTP_15TH_THRU; TP_15TH
R1, R4, R40, R41, R44, R45, R46, R47, R48: 2.2k; 0402-TIGHT
R2: 330K; 0402-TIGHT
R3: 220k; 0402-TIGHT
R5, R22, R23, R24, R25: 1k; 0402-TIGHT
R6: 1M; 0402-TIGHT
R7: 2M; 0402-TIGHT
R8: 0; 0402-TIGHT
R26, R27: 5.1k; 0402-TIGHT
R28: 100k; 0402-TIGHT
R29: 220KOHM-0402T-1/16W-1%; 0402-TIGHT
R49: DNP; 0402-TIGHT
S3: RESET; TACTILE_SWITCH_SMD_4.6X2.8MM
SCL: TEST-POINTTP_15TH_THRU; TP_15TH
SDA: TEST-POINTTP_15TH_THRU; TP_15TH
TP1: TEST-POINT3; PAD.03X.03
U1: 3.0V Supervisor; SOT23-3
U2: MCP73831; SOT23-5
U3, U4: 3.3V; SOT23-5
U8: ARTEMIS_MODULE; ARTEMIS_FP
U10: CH340E; MSOP10
U13: 9DoF IMU; QFN24-3X3-ICM-20948
U14: 1.8V/100mA; SC70
VE: JUMPER-SMT_2_NO_SILK; SMT-JUMPER_2_NO_SILK
Y3: 32.768kHz; CRYSTAL-SMD-3.2X1.5MM

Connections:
3.3V: C2.1, C40.1, C41.1, C54.1, D6.A, J4.5, J14.1 (VCC), Q2.2 (S), R24.2, R25.2, R45.2, R47.2, R49.2, U1.3 (VCC), U3.5 (OUT), U10.7 (VCC), U10.10 (V3), U14.1 (IN)
5V: C3.1, D1.C, D2.A, J5.VBUS1 (VBUS), J5.VBUS2 (VBUS), JP2.1, JP2.3 (1), U2.4 (VIN)
!POWER_LOSS!: U1.2 (VOUT), U8.D3 ((SLNCE/I2SWCLK)D3)
ARTEMIS_!RESET: C42.2, C44.1, J7.1, J14.10 (!RESET), R28.1, S3.3 (2), S3.4 (2), U8.~RST (!RST)
ARTEMIS_!RTS!: C42.1, C43.1, U10.4 (!RTS)
ARTEMIS_BOOT: C43.2, R29.2, U8.BOOT (~BOOT(SDO5/RX1/32KHZ))
ARTEMIS_RX0: D11.C, U8.RXI-0 (~D49(RX0/SDA5/SDI5)), U10.8 (TXO)
ARTEMIS_SWDCK: J14.4 (SWDCLK), U8.SWDCK (D20(SWDCK/TX1))
ARTEMIS_SWDIO: J14.2 (SWDIO), U8.SWDIO (D21(SWDIO/RX1/SCCRST))
ARTEMIS_TX0: D12.C, U8.TXO-0 (~D48(TX0/SCL5/SCK5)), U10.9 (RXI)
ARTEMIS_~AD11: J4.1, U8.~AD11 (~AD11(PDMDATA))
ARTEMIS_~AD12/TX1: J4.3, U8.~AD12 (~AD12(PDMCLK/TX1))
ARTEMIS_~AD13/RX1: J4.2, U8.~AD13 (~AD13(I2SBCLK/RX1))
ARTEMIS_~AD32: J4.4, U8.~AD32 (~AD32(SCCIO))
CC3: J5.B5 (CC2), R26.2
CC4: J5.A5 (CC1), R27.2
CHG_LED: R5.1, U2.1 (STAT)
D+2: J5.A6 (D+), J5.B6 (D+), U10.1 (UD+)
D-2: J5.A7 (D-), J5.B7 (D-), U10.2 (UD-)
DAT1: J6.DAT1 (DAT1/NC), U8.~D26 ((SCCRST)~D26)
DAT2: J6.DAT2 (DAT2/NC), U8.~D4 ((RX1/SLINT)~D4)
GND: BT1.-, C1.2, C2.2, C3.2, C4.2, C5.2, C7.2, C29.1, C30.1, C31.1, C32.2, C33.2, C40.2, C41.2, C44.2, C46.2, C51.2, C52.2, C53.2, C54.2, D9.C, GND.P$1, J1.2, J2.1 (-), J3.2, J4.6, J5.GND, J5.GND2 (GND), J6.CD1 (SHIELD), J6.GND, J6.GND1 (GND), J6.GND3 (GND), J11.1, J14.3 (GND), J14.5 (GND), J14.9 (GND), LED1.C, R3.1, R4.1, R6.1, R8.1, R26.1, R27.1, R29.1, S3.1, S3.2 (1), U1.1 (GND), U2.2 (VSS), U3.2 (GND), U4.2 (GND), U8.GND@1 (GND*6), U8.GND@22 (GND*6), U8.GND@38 (GND*6), U8.GND@39 (GND*6), U8.GND@47 (GND*6), U8.GND@59 (GND*6), U10.3 (GND), U13.18 (GND), U13.20 (GND), U14.2 (GND)
ICM-20948-LV_!CS!: Q9.2 (S), R46.1, U13.22 (!CS)
ICM-20948-LV_#_1.8V: C52.1, C53.1, Q1.1 (G), Q3.1 (G), Q7.1 (G), Q9.1 (G), Q10.1 (G), R40.2, R41.2, R44.2, R46.2, R48.2, U13.8 (VDDIO), U13.13 (VDD), U14.5 (OUT)
ICM-20948-LV_INT: Q7.2 (S), R44.1, U13.12 (INT)
ICM-20948-LV_SCK: Q1.2 (S), R40.1, U13.23 (SCL/SCLK)
ICM-20948-LV_SDI: Q3.2 (S), R41.1, U13.24 (SDA/SDI)
ICM-20948-LV_SDO: Q10.2 (S), R48.1, U13.9 (AD0/SDO)
ICM_!CS!: Q9.3 (D), R47.1, U8.~D44 ((SDO4)~D44)
ICM_INT: Q7.3 (D), R45.1, U8.~D37 ((TX1/PDMCLK/SCCIO)~D37)
ICM_PWR: U8.~D27 ((SCL2/SCK2)~D27), U14.3 (EN)
MICROSD_!CS!: J6.CS/DAT3 (DAT3/!CS!), U8.~D23 ((I2SWCLK/CMPOUT)~D23)
MICROSD_PWR: Q2.1 (G), U8.D15 ((ADCD1N/RX1/PDMDATA)D15)
unnamed: J5.SHLD1 (SHLD), J5.SHLD2 (SHLD), J5.SHLD3 (SHLD), J5.SHLD4 (SHLD), R8.2
unnamed: R4.2, U2.5 (PROG)
unnamed: D2.C, R5.2
unnamed: C29.2, U8.XO, Y3.P$2 (2)
unnamed: C30.2, U8.XI, Y3.P$1 (1)
unnamed: LED1.A, R22.1
unnamed: D9.A, R23.1
unnamed: D12.A, R25.1
unnamed: D11.A, R24.1
unnamed: C51.1, U13.10 (REGOUT)
PWR_LED: R22.2, U8.~AD29 (~AD29(PDMDATA))
QWIIC_3.3V: C5.1, C7.1, J11.2, QWIIC_3.3V.P$1, U4.5 (OUT)
QWIIC_PWR: R3.2, U4.3 (EN), U8.~D18 ((CMPIN1/SCCIO)~D18)
RTC_BAT+: BT1.+, D3.A, R1.1, TP1.P$1
SCK: J6.SCLK (CLK/SCK), Q1.3 (D), U8.~D5 ((SCL0/SCK0)~D5)
SCL: J11.4, SCL.P$1, U8.D8 ((SCL1/SCK1/TX1/SCCLK)D8)
SDA: J11.3, SDA.P$1, U8.D9 ((SDA1/SDI1/RX1/SCCIO)D9)
SDI: J6.DO/DAT0 (DAT0/SDO), Q10.3 (D), R49.1, U8.~D6 ((SDA0/SDI0/I2SDAT)~D6), U8.~D22 ((PDMCLK/SWO)~D22)
SDO: J6.DI/CMD (CMD/SDI), Q3.3 (D), U8.D7 ((SDO0/CLKOUT)~D7)
SD_PWR: C46.1, J6.VCC, Q2.3 (D)
STATLED: R23.2, U8.~D19 ((CMPRF0/SCCCLK/I2SBCLK)~D19)
SWO: J14.6 (SWO), U8.~AD33/SWO (~AD33(SWO/32KHZ))
VCC_1: C31.2, C32.1, C33.1, D3.C, D6.C, R1.2, R28.2, U8.VDD@36 (VDD*2), U8.VDD@37 (VDD*2)
VIN: C1.1, JP2.2, JP2.4 (2), R2.2, R7.2, U3.1 (IN), U4.1 (IN)
VIN/3: R6.2, R7.1, U8.AD34 (AD34(CMPRF2/PDMDATA))
VREG_EN: J3.1, R2.1, U3.3 (EN), VE.2
VREG_EN1: U8.~D25 ((SDA2/SDI2/RX1)~D25), VE.1
V_BATT: C4.1, D1.A, J1.1, J2.2 (+), U2.3 (VBAT)

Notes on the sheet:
AP2112K-3.3V ---------------- Iout (max): 600mA Vin (max): 6.5V Vdrop (max): 250mV Iq: 55uA
v10
N. Seidle
LiPo Charger
I/O, Power Headers
LiPo Range: 3.6-4.2V
Charge current: 450mA (1000V/Rprog)
SWD Program/Debug Interface
Artemis
Artemis VCC Range: 1.76-3.6V
Linear 3.3V
Open jumper to switch or measure power
USB-to-Serial Converter
Bootloader Reset Circuit
μSD
ICM-20948 IMU
Voltage Regulator
Level Shifting
Qwiic
RTC Battery
Optional External Switch Also software controlled
300uA Leakage
0.65uA Leakage 0.3V drop at 10mA
1mAhr Capacity
Change from X04 to V10: ICM PWR moved from 22 to 27 SD CS moved from 10 to 23 Add PWR_LED on 29 Add VREG_EN on 25 Add SDIO connection to SD Add VIN monitor on AD34 (R6/R7) QWIIC_PWR (18) will be active high
VIN monitor
LEDs
Close the VE split pad to allow the Artemis to disable the 3.3V regulator (forcing it to run from the RTC battery). This will reduce the sleep current draw by approx. 55μA.
SP6214-1.8V ---------------- Iout (max): 100mA Vin (max): 7.0V Vdrop (max): 250mV Iq: 65uA
Controller In Peripheral Out (CIPO)
Controller Out Peripheral In (COPI)

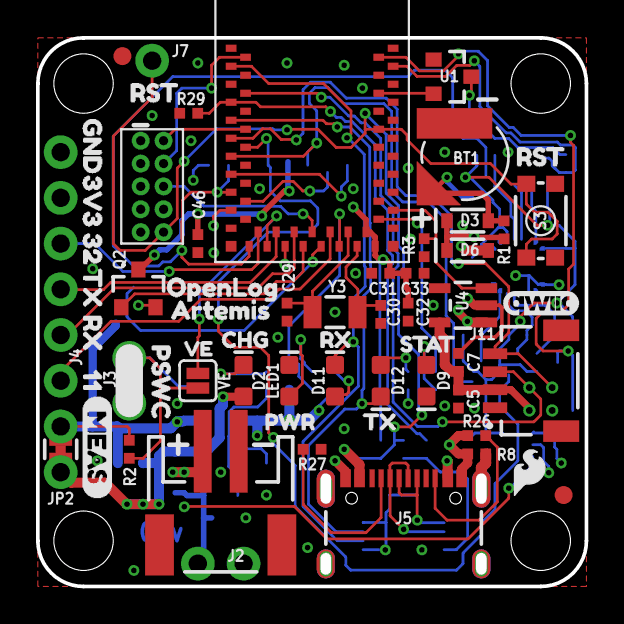
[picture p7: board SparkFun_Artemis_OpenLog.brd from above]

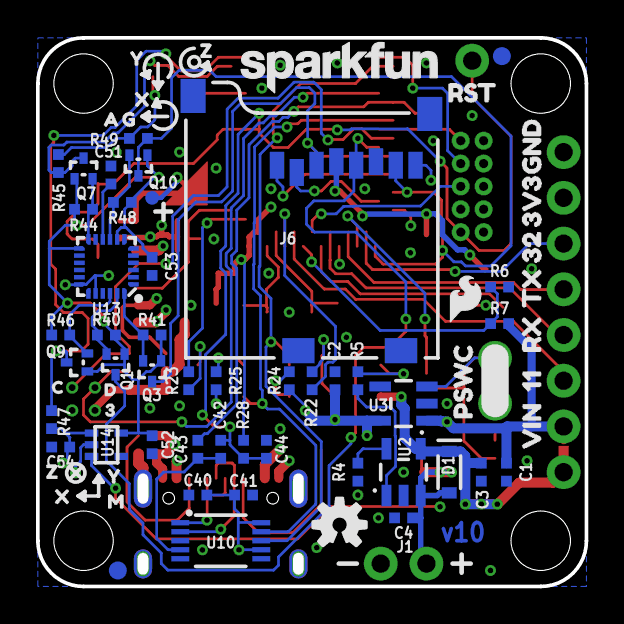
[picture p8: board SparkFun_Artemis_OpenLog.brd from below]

Board: 4 copper layers, 30.5 x 30.5 mm, 140 parts (74 on the bottom side), 61 nets.

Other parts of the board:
U$1: QWIIC#LOGO#JPG
U$2: CHG2
U$3: PWR0
U$4: RX4
U$5: STAT5
U$6: VE0
U$7: TX3
U$8, U$12: RST0
U$9: ARTEMIS13
U$10, U$11: PSWC0
U$13: C0
U$14: D0
U$15: 30
U$27: MEAS3
U$28: OPENLOG12
U$32: RST9
U$33: VIN8
U$34, U$35: 3V34
U$36, U$37: 113
U$38, U$39: 322
U$40, U$41: GND5
U$42, U$54: RX1
U$43, U$49: X0
U$44, U$50: Y1
U$45, U$51: Z2
U$46: G5
U$47: A4
U$48: M3
U$55, U$56: TX0

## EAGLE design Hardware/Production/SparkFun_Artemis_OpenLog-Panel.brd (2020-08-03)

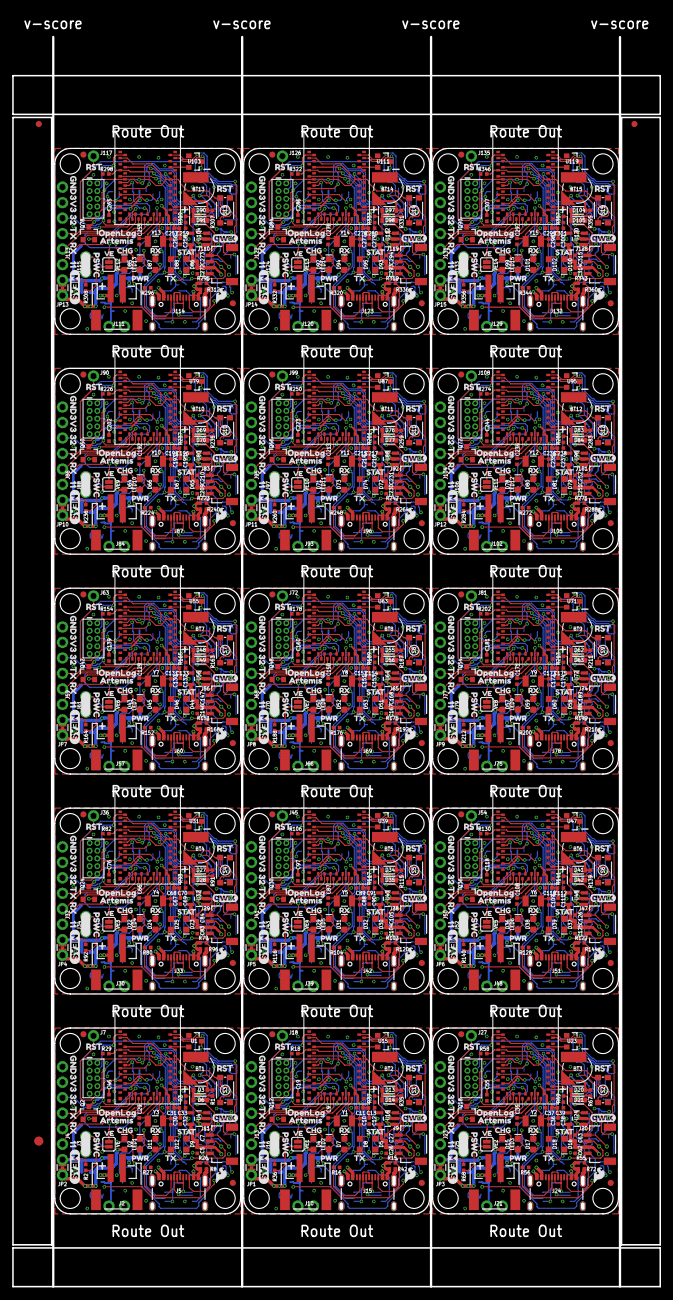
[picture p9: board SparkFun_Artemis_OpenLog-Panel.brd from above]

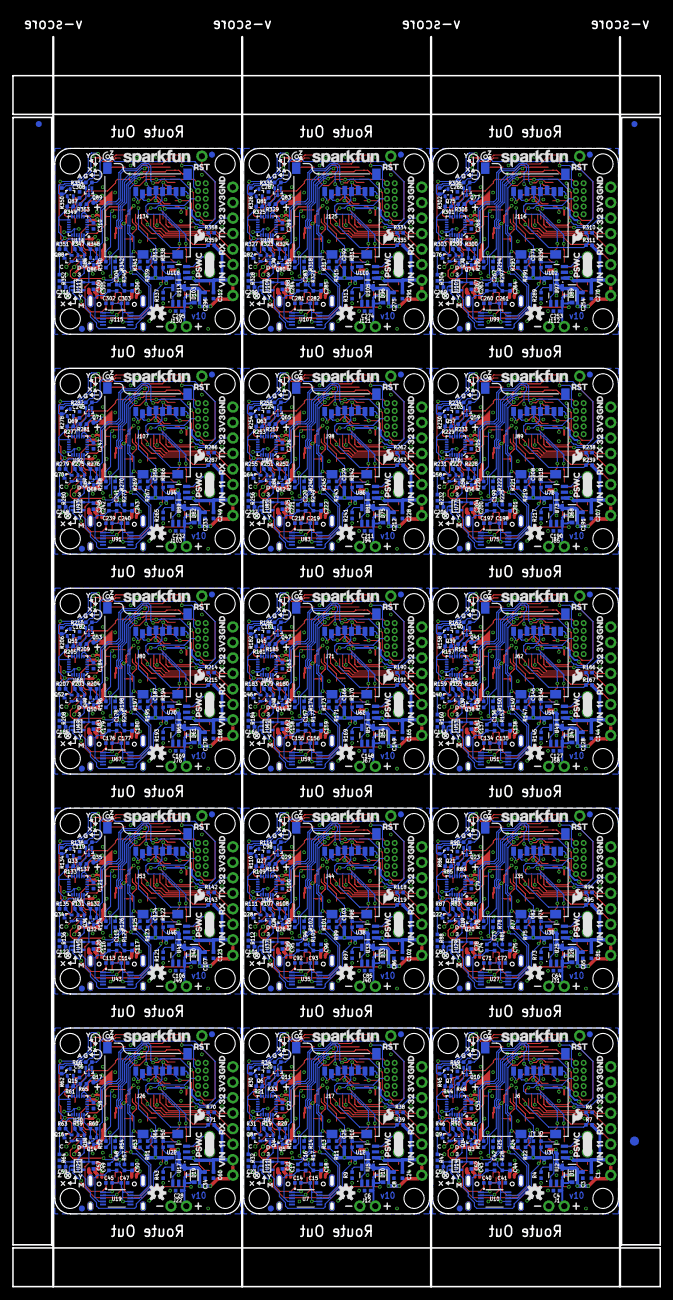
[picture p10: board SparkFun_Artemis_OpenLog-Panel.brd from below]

Board: 4 copper layers, 106.2 x 205.0 mm, 2076 parts (1113 on the bottom side), 915 nets.

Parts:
BT1, BT2, BT3, BT4, BT5, BT6, BT7, BT8, BT9, BT10, BT11, BT12, BT13, BT14, BT15: ML414H; ML414H_IV01E
C1, C13, C22, C23, C24, C33, C39, C53, C54, C58, C59, C60, C70, C79, C80, C81, C91, C100, C101, C102, C112, C121, C122, C123, C133, C142, C143, C144, C154, C163, C164, C165, C175, C184, C185, C186, C196, C205, C206, C207, C217, C226, C227, C228, C238, C247, C248, C249, C259, C268, C269, C270, C280, C289, C290, C291, C301, C310, C311, C312: 1.0uF; 0402-TIGHT
C2, C7, C25, C27, C61, C63, C82, C84, C103, C105, C124, C126, C145, C147, C166, C168, C187, C189, C208, C210, C229, C231, C250, C252, C271, C273, C292, C294, C313, C315: 2.2uF; 0402-TIGHT
C3, C4, C6, C8, C28, C34, C64, C65, C85, C86, C106, C107, C127, C128, C148, C149, C169, C170, C190, C191, C211, C212, C232, C233, C253, C254, C274, C275, C295, C296: 4.7uF; 0402-TIGHT
C5, C11, C15, C16, C17, C19, C20, C21, C26, C31, C37, C41, C42, C43, C46, C47, C48, C49, C51, C52, C55, C56, C57, C62, C68, C72, C73, C74, C76, C77, C78, C83, C89, C93, C94, C95, C97, C98, C99, C104, C110, C114, C115, C116, C118, C119, C120, C125, C131, C135, C136, C137, C139, C140, C141, C146, C152, C156, C157, C158, C160, C161, C162, C167, C173, C177, C178, C179, C181, C182, C183, C188, C194, C198, C199, C200, C202, C203, C204, C209, C215, C219, C220, C221, C223, C224, C225, C230, C236, C240, C241, C242, C244, C245, C246, C251, C257, C261, C262, C263, C265, C266, C267, C272, C278, C282, C283, C284, C286, C287, C288, C293, C299, C303, C304, C305, C307, C308, C309, C314: 0.1uF; 0402-TIGHT
C9, C10, C29, C30, C35, C36, C66, C67, C87, C88, C108, C109, C129, C130, C150, C151, C171, C172, C192, C193, C213, C214, C234, C235, C255, C256, C276, C277, C297, C298: 15pF; 0402-TIGHT
C12, C32, C38, C69, C90, C111, C132, C153, C174, C195, C216, C237, C258, C279, C300: 10uF; 0402-TIGHT
C14, C40, C45, C71, C92, C113, C134, C155, C176, C197, C218, C239, C260, C281, C302: 10nF; 0402-TIGHT
C18, C44, C50, C75, C96, C117, C138, C159, C180, C201, C222, C243, C264, C285, C306: 1.0nF; 0402-TIGHT
D1, D3, D10, D13, D19, D20, D26, D27, D33, D34, D40, D41, D47, D48, D54, D55, D61, D62, D68, D69, D75, D76, D82, D83, D89, D90, D96, D97, D103, D104: 3A/10V/280mV; SOD-323
D2, D4, D7, D11, D15, D17, D22, D24, D29, D31, D36, D38, D43, D45, D50, D52, D57, D59, D64, D66, D71, D73, D78, D80, D85, D87, D92, D94, D99, D101: Yellow; LED-0603
D5, D9, D16, D23, D30, D37, D44, D51, D58, D65, D72, D79, D86, D93, D100: BLUE; LED-0603
D6, D14, D21, D28, D35, D42, D49, D56, D63, D70, D77, D84, D91, D98, D105: 1A/23V/620mV; SOD-323
D8, D12, D18, D25, D32, D39, D46, D53, D60, D67, D74, D81, D88, D95, D102: GREEN; LED-0603
E$1, E$2, E$3, E$4: FIDUCIAL-1X2
E$5, E$6: FIDUCIAL-1.5X3
FD1, FD2, FD3, FD4, FD5, FD6, FD7, FD8, FD9, FD10, FD11, FD12, FD13, FD14, FD15, FD16, FD17, FD18, FD19, FD20, FD21, FD22, FD23, FD24, FD25, FD26, FD27, FD28, FD29, FD30, FD31, FD32, FD33, FD34, FD35, FD36, FD37, FD38, FD39, FD40, FD41, FD42, FD43, FD44, FD45, FD46, FD47, FD48, FD49, FD50, FD51, FD52, FD53, FD54, FD55, FD56, FD57, FD58, FD59, FD60: FIDUCIAL1X2; FIDUCIAL-1X2
GND, GND1, GND2, GND3, GND4, GND5, GND6, GND7, GND8, GND9, GND10, GND11, GND12, GND13, GND14: TEST-POINTTP_15TH_THRU; TP_15TH
H1, H2, H3, H4, H5, H6, H7, H8, H9, H10, H11, H12, H13, H14, H15, H16, H17, H18, H19, H20, H21, H22, H23, H24, H25, H26, H27, H28, H29, H30, H31, H32, H33, H34, H35, H36, H37, H38, H39, H40, H41, H42, H43, H44, H45, H46, H47, H48, H49, H50, H51, H52, H53, H54, H55, H56, H57, H58, H59, H60: STAND-OFF
J1, J3, J12, J16, J22, J25, J31, J34, J40, J43, J49, J52, J58, J61, J67, J70, J76, J79, J85, J88, J94, J97, J103, J106, J112, J115, J121, J124, J130, J133: 1X02_NO_SILK
J2, J10, J21, J30, J39, J48, J57, J66, J75, J84, J93, J102, J111, J120, J129: JST-2-SMD
J4, J13, J23, J32, J41, J50, J59, J68, J77, J86, J95, J104, J113, J122, J131: 1X06_NO_SILK
J5, J15, J24, J33, J42, J51, J60, J69, J78, J87, J96, J105, J114, J123, J132: USB-C-16P_4LAYER-PADS
J6, J17, J26, J35, J44, J53, J62, J71, J80, J89, J98, J107, J116, J125, J134: MICRO-SD; MICRO-SD-SOCKET
J7, J18, J27, J36, J45, J54, J63, J72, J81, J90, J99, J108, J117, J126, J135: 1X01_NO_SILK
J8, J14, J19, J28, J37, J46, J55, J64, J73, J82, J91, J100, J109, J118, J127: CORTEX_JTAG; 2X5-PTH-1.27MM
J9, J11, J20, J29, J38, J47, J56, J65, J74, J83, J92, J101, J110, J119, J128: JST04_1MM_RA
JP1, JP2, JP3, JP4, JP5, JP6, JP7, JP8, JP9, JP10, JP11, JP12, JP13, JP14, JP15: MEAS; COMBO-JUMPER_2_NC_TRACE
LED1, LED2, LED3, LED4, LED5, LED6, LED7, LED8, LED9, LED10, LED11, LED12, LED13, LED14, LED15: RED; LED-0603
LOGO1, LOGO7, LOGO11, LOGO15, LOGO19, LOGO23, LOGO27, LOGO31, LOGO35, LOGO39, LOGO43, LOGO47, LOGO51, LOGO55, LOGO59: SFE_LOGO_NAME.1_INCH; SFE_LOGO_NAME_.1
LOGO2, LOGO3, LOGO9, LOGO13, LOGO17, LOGO21, LOGO25, LOGO29, LOGO33, LOGO37, LOGO41, LOGO45, LOGO49, LOGO53, LOGO57: OSHW-LOGOS; OSHW-LOGO-S
LOGO4, LOGO5, LOGO6, LOGO8, LOGO10, LOGO12, LOGO14, LOGO16, LOGO18, LOGO20, LOGO22, LOGO24, LOGO26, LOGO28, LOGO30, LOGO32, LOGO34, LOGO36, LOGO38, LOGO40, LOGO42, LOGO44, LOGO46, LOGO48, LOGO50, LOGO52, LOGO54, LOGO56, LOGO58, LOGO60: SFE_LOGO_FLAME.1_INCH; SFE_LOGO_FLAME_.1
Q1, Q3, Q4, Q5, Q6, Q7, Q8, Q9, Q10, Q11, Q13, Q14, Q15, Q16, Q17, Q19, Q20, Q21, Q22, Q23, Q25, Q26, Q27, Q28, Q29, Q31, Q32, Q33, Q34, Q35, Q37, Q38, Q39, Q40, Q41, Q43, Q44, Q45, Q46, Q47, Q49, Q50, Q51, Q52, Q53, Q55, Q56, Q57, Q58, Q59, Q61, Q62, Q63, Q64, Q65, Q67, Q68, Q69, Q70, Q71, Q73, Q74, Q75, Q76, Q77, Q79, Q80, Q81, Q82, Q83, Q85, Q86, Q87, Q88, Q89: 20V/0.2A/8MHz/1.2Ω/1Vth; SOT-416FL
Q2, Q12, Q18, Q24, Q30, Q36, Q42, Q48, Q54, Q60, Q66, Q72, Q78, Q84, Q90: 20V/4.2A/52mΩ/1.4W; SOT23-3
QWIIC_3.3V, QWIIC_3.3V1, QWIIC_3.3V2, QWIIC_3.3V3, QWIIC_3.3V4, QWIIC_3.3V5, QWIIC_3.3V6, QWIIC_3.3V7, QWIIC_3.3V8, QWIIC_3.3V9, QWIIC_3.3V10, QWIIC_3.3V11, QWIIC_3.3V12, QWIIC_3.3V13, QWIIC_3.3V14: TEST-POINTTP_15TH_THRU; TP_15TH
R1, R5, R10, R11, R12, R13, R14, R22, R23, R24, R25, R35, R50, R51, R52, R53, R54, R67, R74, R75, R76, R77, R78, R91, R98, R99, R100, R101, R102, R115, R122, R123, R124, R125, R126, R139, R146, R147, R148, R149, R150, R163, R170, R171, R172, R173, R174, R187, R194, R195, R196, R197, R198, R211, R218, R219, R220, R221, R222, R235, R242, R243, R244, R245, R246, R259, R266, R267, R268, R269, R270, R283, R290, R291, R292, R293, R294, R307, R314, R315, R316, R317, R318, R331, R338, R339, R340, R341, R342, R355: 1k; 0402-TIGHT
R2, R36, R68, R92, R116, R140, R164, R188, R212, R236, R260, R284, R308, R332, R356: 330K; 0402-TIGHT
R3, R37, R69, R93, R117, R141, R165, R189, R213, R237, R261, R285, R309, R333, R357: 220k; 0402-TIGHT
R4, R9, R19, R20, R21, R30, R31, R32, R33, R40, R41, R43, R44, R45, R46, R47, R48, R59, R60, R61, R62, R63, R64, R65, R73, R83, R84, R85, R86, R87, R88, R89, R97, R107, R108, R109, R110, R111, R112, R113, R121, R131, R132, R133, R134, R135, R136, R137, R145, R155, R156, R157, R158, R159, R160, R161, R169, R179, R180, R181, R182, R183, R184, R185, R193, R203, R204, R205, R206, R207, R208, R209, R217, R227, R228, R229, R230, R231, R232, R233, R241, R251, R252, R253, R254, R255, R256, R257, R265, R275, R276, R277, R278, R279, R280, R281, R289, R299, R300, R301, R302, R303, R304, R305, R313, R323, R324, R325, R326, R327, R328, R329, R337, R347, R348, R349, R350, R351, R352, R353: 2.2k; 0402-TIGHT
R6, R38, R70, R94, R118, R142, R166, R190, R214, R238, R262, R286, R310, R334, R358: 1M; 0402-TIGHT
R7, R39, R71, R95, R119, R143, R167, R191, R215, R239, R263, R287, R311, R335, R359: 2M; 0402-TIGHT
R8, R42, R72, R96, R120, R144, R168, R192, R216, R240, R264, R288, R312, R336, R360: 0; 0402-TIGHT
R15, R16, R26, R27, R55, R56, R79, R80, R103, R104, R127, R128, R151, R152, R175, R176, R199, R200, R223, R224, R247, R248, R271, R272, R295, R296, R319, R320, R343, R344: 5.1k; 0402-TIGHT
R17, R28, R57, R81, R105, R129, R153, R177, R201, R225, R249, R273, R297, R321, R345: 100k; 0402-TIGHT
R18, R29, R58, R82, R106, R130, R154, R178, R202, R226, R250, R274, R298, R322, R346: 220KOHM-0402T-1/16W-1%; 0402-TIGHT
R34, R49, R66, R90, R114, R138, R162, R186, R210, R234, R258, R282, R306, R330, R354: DNP; 0402-TIGHT
S1, S2, S3, S4, S5, S6, S7, S8, S9, S10, S11, S12, S13, S14, S15: RESET; TACTILE_SWITCH_SMD_4.6X2.8MM
SCL, SCL1, SCL2, SCL3, SCL4, SCL5, SCL6, SCL7, SCL8, SCL9, SCL10, SCL11, SCL12, SCL13, SCL14: TEST-POINTTP_15TH_THRU; TP_15TH
SDA, SDA1, SDA2, SDA3, SDA4, SDA5, SDA6, SDA7, SDA8, SDA9, SDA10, SDA11, SDA12, SDA13, SDA14: TEST-POINTTP_15TH_THRU; TP_15TH
TP1, TP2, TP3, TP4, TP5, TP6, TP7, TP8, TP9, TP10, TP11, TP12, TP13, TP14, TP15: TEST-POINT3; PAD.03X.03
U1, U15, U23, U31, U39, U47, U55, U63, U71, U79, U87, U95, U103, U111, U119: 3.0V Supervisor; SOT23-3
U2, U5, U17, U25, U33, U41, U49, U57, U65, U73, U81, U89, U97, U105, U113: MCP73831; SOT23-5
U3, U4, U12, U16, U22, U24, U30, U32, U38, U40, U46, U48, U54, U56, U62, U64, U70, U72, U78, U80, U86, U88, U94, U96, U102, U104, U110, U112, U118, U120: 3.3V; SOT23-5
U6, U8, U18, U26, U34, U42, U50, U58, U66, U74, U82, U90, U98, U106, U114: ARTEMIS_MODULE; ARTEMIS_FP
U7, U10, U19, U27, U35, U43, U51, U59, U67, U75, U83, U91, U99, U107, U115: CH340E; MSOP10
U9, U13, U20, U28, U36, U44, U52, U60, U68, U76, U84, U92, U100, U108, U116: 9DoF IMU; QFN24-3X3-ICM-20948
U11, U14, U21, U29, U37, U45, U53, U61, U69, U77, U85, U93, U101, U109, U117: 1.8V/100mA; SC70
U$1, U$26, U$91, U$131, U$171, U$211, U$251, U$291, U$331, U$371, U$411, U$451, U$491, U$531, U$571: QWIIC#LOGO#JPG
U$2, U$29, U$92, U$132, U$172, U$212, U$252, U$292, U$332, U$372, U$412, U$452, U$492, U$532, U$572: CHG2
U$3, U$30, U$93, U$133, U$173, U$213, U$253, U$293, U$333, U$373, U$413, U$453, U$493, U$533, U$573: PWR0
U$4, U$31, U$94, U$134, U$174, U$214, U$254, U$294, U$334, U$374, U$414, U$454, U$494, U$534, U$574: RX4
U$5, U$52, U$95, U$135, U$175, U$215, U$255, U$295, U$335, U$375, U$415, U$455, U$495, U$535, U$575: STAT5
U$6, U$75, U$115, U$155, U$195, U$235, U$275, U$315, U$355, U$395, U$435, U$475, U$515, U$555, U$595: VE0
U$7, U$53, U$96, U$136, U$176, U$216, U$256, U$296, U$336, U$376, U$416, U$456, U$496, U$536, U$576: TX3
U$8, U$12, U$76, U$77, U$116, U$117, U$156, U$157, U$196, U$197, U$236, U$237, U$276, U$277, U$316, U$317, U$356, U$357, U$396, U$397, U$436, U$437, U$476, U$477, U$516, U$517, U$556, U$557, U$596, U$597: RST0
U$9, U$57, U$97, U$137, U$177, U$217, U$257, U$297, U$337, U$377, U$417, U$457, U$497, U$537, U$577: ARTEMIS13
U$10, U$11, U$73, U$74, U$113, U$114, U$153, U$154, U$193, U$194, U$233, U$234, U$273, U$274, U$313, U$314, U$353, U$354, U$393, U$394, U$433, U$434, U$473, U$474, U$513, U$514, U$553, U$554, U$593, U$594: PSWC0
U$13, U$78, U$118, U$158, U$198, U$238, U$278, U$318, U$358, U$398, U$438, U$478, U$518, U$558, U$598: C0
U$14, U$79, U$119, U$159, U$199, U$239, U$279, U$319, U$359, U$399, U$439, U$479, U$519, U$559, U$599: D0
U$15, U$80, U$120, U$160, U$200, U$240, U$280, U$320, U$360, U$400, U$440, U$480, U$520, U$560, U$600: 30
U$16, U$27, U$81, U$121, U$161, U$201, U$241, U$281, U$321, U$361, U$401, U$441, U$481, U$521, U$561: MEAS3
U$17, U$23, U$43, U$49, U$82, U$88, U$122, U$128, U$162, U$168, U$202, U$208, U$242, U$248, U$282, U$288, U$322, U$328, U$362, U$368, U$402, U$408, U$442, U$448, U$482, U$488, U$522, U$528, U$562, U$568: X0
U$18, U$24, U$44, U$50, U$83, U$89, U$123, U$129, U$163, U$169, U$203, U$209, U$243, U$249, U$283, U$289, U$323, U$329, U$363, U$369, U$403, U$409, U$443, U$449, U$483, U$489, U$523, U$529, U$563, U$569: Y1
U$19, U$25, U$45, U$51, U$84, U$90, U$124, U$130, U$164, U$170, U$204, U$210, U$244, U$250, U$284, U$290, U$324, U$330, U$364, U$370, U$404, U$410, U$444, U$450, U$484, U$490, U$524, U$530, U$564, U$570: Z2
U$20, U$46, U$85, U$125, U$165, U$205, U$245, U$285, U$325, U$365, U$405, U$445, U$485, U$525, U$565: G5
U$21, U$47, U$86, U$126, U$166, U$206, U$246, U$286, U$326, U$366, U$406, U$446, U$486, U$526, U$566: A4
U$22, U$48, U$87, U$127, U$167, U$207, U$247, U$287, U$327, U$367, U$407, U$447, U$487, U$527, U$567: M3
U$28, U$58, U$98, U$138, U$178, U$218, U$258, U$298, U$338, U$378, U$418, U$458, U$498, U$538, U$578: OPENLOG12
U$32, U$59, U$99, U$139, U$179, U$219, U$259, U$299, U$339, U$379, U$419, U$459, U$499, U$539, U$579: RST9
U$33, U$60, U$100, U$140, U$180, U$220, U$260, U$300, U$340, U$380, U$420, U$460, U$500, U$540, U$580: VIN8
U$34, U$35, U$61, U$62, U$101, U$102, U$141, U$142, U$181, U$182, U$221, U$222, U$261, U$262, U$301, U$302, U$341, U$342, U$381, U$382, U$421, U$422, U$461, U$462, U$501, U$502, U$541, U$542, U$581, U$582: 3V34
U$36, U$37, U$63, U$64, U$103, U$104, U$143, U$144, U$183, U$184, U$223, U$224, U$263, U$264, U$303, U$304, U$343, U$344, U$383, U$384, U$423, U$424, U$463, U$464, U$503, U$504, U$543, U$544, U$583, U$584: 113
U$38, U$39, U$65, U$66, U$105, U$106, U$145, U$146, U$185, U$186, U$225, U$226, U$265, U$266, U$305, U$306, U$345, U$346, U$385, U$386, U$425, U$426, U$465, U$466, U$505, U$506, U$545, U$546, U$585, U$586: 322
U$40, U$41, U$67, U$68, U$107, U$108, U$147, U$148, U$187, U$188, U$227, U$228, U$267, U$268, U$307, U$308, U$347, U$348, U$387, U$388, U$427, U$428, U$467, U$468, U$507, U$508, U$547, U$548, U$587, U$588: GND5
U$42, U$54, U$69, U$70, U$109, U$110, U$149, U$150, U$189, U$190, U$229, U$230, U$269, U$270, U$309, U$310, U$349, U$350, U$389, U$390, U$429, U$430, U$469, U$470, U$509, U$510, U$549, U$550, U$589, U$590: RX1
U$55, U$56, U$71, U$72, U$111, U$112, U$151, U$152, U$191, U$192, U$231, U$232, U$271, U$272, U$311, U$312, U$351, U$352, U$391, U$392, U$431, U$432, U$471, U$472, U$511, U$512, U$551, U$552, U$591, U$592: TX0
VE, VE1, VE2, VE3, VE4, VE5, VE6, VE7, VE8, VE9, VE10, VE11, VE12, VE13, VE14: SMT-JUMPER_2_NO_SILK
Y1, Y2, Y3, Y4, Y5, Y6, Y7, Y8, Y9, Y10, Y11, Y12, Y13, Y14, Y15: 32.768kHz; CRYSTAL-SMD-3.2X1.5MM

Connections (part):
3.3V: C2.1, C40.1, C41.1, C54.1, D6.A, J4.5, J14.1, Q2.2, R24.2, R25.2, R45.2, R47.2, R49.2, U1.3, U3.5, U10.7, U10.10, U14.1
3.3V1: C14.1, C15.1, C23.1, C25.1, D14.A, J8.1, J13.5, Q12.2, R13.2, R14.2, R30.2, R32.2, R34.2, U7.7, U7.10, U11.1, U12.5, U15.3
3.3V2: C45.1, C47.1, C59.1, C61.1, D21.A, J19.1, J23.5, Q18.2, R53.2, R54.2, R62.2, R64.2, R66.2, U19.7, U19.10, U21.1, U22.5, U23.3
3.3V3: C71.1, C72.1, C80.1, C82.1, D28.A, J28.1, J32.5, Q24.2, R77.2, R78.2, R86.2, R88.2, R90.2, U27.7, U27.10, U29.1, U30.5, U31.3
3.3V4: C92.1, C93.1, C101.1, C103.1, D35.A, J37.1, J41.5, Q30.2, R101.2, R102.2, R110.2, R112.2, R114.2, U35.7, U35.10, U37.1, U38.5, U39.3
3.3V5: C113.1, C114.1, C122.1, C124.1, D42.A, J46.1, J50.5, Q36.2, R125.2, R126.2, R134.2, R136.2, R138.2, U43.7, U43.10, U45.1, U46.5, U47.3
3.3V6: C134.1, C135.1, C143.1, C145.1, D49.A, J55.1, J59.5, Q42.2, R149.2, R150.2, R158.2, R160.2, R162.2, U51.7, U51.10, U53.1, U54.5, U55.3
3.3V7: C155.1, C156.1, C164.1, C166.1, D56.A, J64.1, J68.5, Q48.2, R173.2, R174.2, R182.2, R184.2, R186.2, U59.7, U59.10, U61.1, U62.5, U63.3
3.3V8: C176.1, C177.1, C185.1, C187.1, D63.A, J73.1, J77.5, Q54.2, R197.2, R198.2, R206.2, R208.2, R210.2, U67.7, U67.10, U69.1, U70.5, U71.3
3.3V9: C197.1, C198.1, C206.1, C208.1, D70.A, J82.1, J86.5, Q60.2, R221.2, R222.2, R230.2, R232.2, R234.2, U75.7, U75.10, U77.1, U78.5, U79.3
3.3V10: C218.1, C219.1, C227.1, C229.1, D77.A, J91.1, J95.5, Q66.2, R245.2, R246.2, R254.2, R256.2, R258.2, U83.7, U83.10, U85.1, U86.5, U87.3
3.3V11: C239.1, C240.1, C248.1, C250.1, D84.A, J100.1, J104.5, Q72.2, R269.2, R270.2, R278.2, R280.2, R282.2, U91.7, U91.10, U93.1, U94.5, U95.3
3.3V12: C260.1, C261.1, C269.1, C271.1, D91.A, J109.1, J113.5, Q78.2, R293.2, R294.2, R302.2, R304.2, R306.2, U99.7, U99.10, U101.1, U102.5, U103.3
3.3V13: C281.1, C282.1, C290.1, C292.1, D98.A, J118.1, J122.5, Q84.2, R317.2, R318.2, R326.2, R328.2, R330.2, U107.7, U107.10, U109.1, U110.5, U111.3
3.3V14: C302.1, C303.1, C311.1, C313.1, D105.A, J127.1, J131.5, Q90.2, R341.2, R342.2, R350.2, R352.2, R354.2, U115.7, U115.10, U117.1, U118.5, U119.3
5V: C3.1, D1.C, D2.A, J5.VBUS1, J5.VBUS2, JP2.1, JP2.3, U2.4
5V1: C8.1, D4.A, D10.C, J15.VBUS1, J15.VBUS2, JP1.1, JP1.3, U5.4
5V2: C34.1, D15.A, D19.C, J24.VBUS1, J24.VBUS2, JP3.1, JP3.3, U17.4
5V3: C65.1, D22.A, D26.C, J33.VBUS1, J33.VBUS2, JP4.1, JP4.3, U25.4
5V4: C86.1, D29.A, D33.C, J42.VBUS1, J42.VBUS2, JP5.1, JP5.3, U33.4
5V5: C107.1, D36.A, D40.C, J51.VBUS1, J51.VBUS2, JP6.1, JP6.3, U41.4
5V6: C128.1, D43.A, D47.C, J60.VBUS1, J60.VBUS2, JP7.1, JP7.3, U49.4
5V7: C149.1, D50.A, D54.C, J69.VBUS1, J69.VBUS2, JP8.1, JP8.3, U57.4
5V8: C170.1, D57.A, D61.C, J78.VBUS1, J78.VBUS2, JP9.1, JP9.3, U65.4
5V9: C191.1, D64.A, D68.C, J87.VBUS1, J87.VBUS2, JP10.1, JP10.3, U73.4
5V10: C212.1, D71.A, D75.C, J96.VBUS1, J96.VBUS2, JP11.1, JP11.3, U81.4
5V11: C233.1, D78.A, D82.C, J105.VBUS1, J105.VBUS2, JP12.1, JP12.3, U89.4
5V12: C254.1, D85.A, D89.C, J114.VBUS1, J114.VBUS2, JP13.1, JP13.3, U97.4
5V13: C275.1, D92.A, D96.C, J123.VBUS1, J123.VBUS2, JP14.1, JP14.3, U105.4
5V14: C296.1, D99.A, D103.C, J132.VBUS1, J132.VBUS2, JP15.1, JP15.3, U113.4
!POWER_LOSS!: U1.2, U8.D3
!POWER_LOSS!1: U6.D3, U15.2
!POWER_LOSS!2: U18.D3, U23.2
!POWER_LOSS!3: U26.D3, U31.2
!POWER_LOSS!4: U34.D3, U39.2
!POWER_LOSS!5: U42.D3, U47.2
!POWER_LOSS!6: U50.D3, U55.2
!POWER_LOSS!7: U58.D3, U63.2
!POWER_LOSS!8: U66.D3, U71.2
!POWER_LOSS!9: U74.D3, U79.2
!POWER_LOSS!10: U82.D3, U87.2
!POWER_LOSS!11: U90.D3, U95.2
!POWER_LOSS!12: U98.D3, U103.2
!POWER_LOSS!13: U106.D3, U111.2
!POWER_LOSS!14: U114.D3, U119.2
ARTEMIS_!RESET: C42.2, C44.1, J7.1, J14.10, R28.1, S3.3, S3.4, U8.~RST
ARTEMIS_!RESET1: C16.2, C18.1, J8.10, J18.1, R17.1, S1.3, S1.4, U6.~RST
ARTEMIS_!RESET2: C48.2, C50.1, J19.10, J27.1, R57.1, S2.3, S2.4, U18.~RST
ARTEMIS_!RESET3: C73.2, C75.1, J28.10, J36.1, R81.1, S4.3, S4.4, U26.~RST
ARTEMIS_!RESET4: C94.2, C96.1, J37.10, J45.1, R105.1, S5.3, S5.4, U34.~RST
ARTEMIS_!RESET5: C115.2, C117.1, J46.10, J54.1, R129.1, S6.3, S6.4, U42.~RST
ARTEMIS_!RESET6: C136.2, C138.1, J55.10, J63.1, R153.1, S7.3, S7.4, U50.~RST
ARTEMIS_!RESET7: C157.2, C159.1, J64.10, J72.1, R177.1, S8.3, S8.4, U58.~RST
ARTEMIS_!RESET8: C178.2, C180.1, J73.10, J81.1, R201.1, S9.3, S9.4, U66.~RST
ARTEMIS_!RESET9: C199.2, C201.1, J82.10, J90.1, R225.1, S10.3, S10.4, U74.~RST
ARTEMIS_!RESET10: C220.2, C222.1, J91.10, J99.1, R249.1, S11.3, S11.4, U82.~RST
ARTEMIS_!RESET11: C241.2, C243.1, J100.10, J108.1, R273.1, S12.3, S12.4, U90.~RST
ARTEMIS_!RESET12: C262.2, C264.1, J109.10, J117.1, R297.1, S13.3, S13.4, U98.~RST
ARTEMIS_!RESET13: C283.2, C285.1, J118.10, J126.1, R321.1, S14.3, S14.4, U106.~RST
ARTEMIS_!RESET14: C304.2, C306.1, J127.10, J135.1, R345.1, S15.3, S15.4, U114.~RST
ARTEMIS_!RTS!: C42.1, C43.1, U10.4
ARTEMIS_!RTS!1: C16.1, C17.1, U7.4
ARTEMIS_!RTS!2: C48.1, C49.1, U19.4
ARTEMIS_!RTS!3: C73.1, C74.1, U27.4
ARTEMIS_!RTS!4: C94.1, C95.1, U35.4
ARTEMIS_!RTS!5: C115.1, C116.1, U43.4
ARTEMIS_!RTS!6: C136.1, C137.1, U51.4
ARTEMIS_!RTS!7: C157.1, C158.1, U59.4
ARTEMIS_!RTS!8: C178.1, C179.1, U67.4
ARTEMIS_!RTS!9: C199.1, C200.1, U75.4
ARTEMIS_!RTS!10: C220.1, C221.1, U83.4
ARTEMIS_!RTS!11: C241.1, C242.1, U91.4
ARTEMIS_!RTS!12: C262.1, C263.1, U99.4
ARTEMIS_!RTS!13: C283.1, C284.1, U107.4
ARTEMIS_!RTS!14: C304.1, C305.1, U115.4
ARTEMIS_BOOT: C43.2, R29.2, U8.BOOT
ARTEMIS_BOOT1: C17.2, R18.2, U6.BOOT
ARTEMIS_BOOT2: C49.2, R58.2, U18.BOOT
ARTEMIS_BOOT3: C74.2, R82.2, U26.BOOT
ARTEMIS_BOOT4: C95.2, R106.2, U34.BOOT
ARTEMIS_BOOT5: C116.2, R130.2, U42.BOOT
ARTEMIS_BOOT6: C137.2, R154.2, U50.BOOT
ARTEMIS_BOOT7: C158.2, R178.2, U58.BOOT
ARTEMIS_BOOT8: C179.2, R202.2, U66.BOOT
ARTEMIS_BOOT9: C200.2, R226.2, U74.BOOT
ARTEMIS_BOOT10: C221.2, R250.2, U82.BOOT
ARTEMIS_BOOT11: C242.2, R274.2, U90.BOOT
ARTEMIS_BOOT12: C263.2, R298.2, U98.BOOT
ARTEMIS_BOOT13: C284.2, R322.2, U106.BOOT
ARTEMIS_BOOT14: C305.2, R346.2, U114.BOOT
ARTEMIS_RX0: D11.C, U8.RXI-0, U10.8
ARTEMIS_RX1: D7.C, U6.RXI-0, U7.8
ARTEMIS_RX2: D17.C, U18.RXI-0, U19.8
ARTEMIS_RX3: D24.C, U26.RXI-0, U27.8
ARTEMIS_RX4: D31.C, U34.RXI-0, U35.8
ARTEMIS_RX5: D38.C, U42.RXI-0, U43.8
ARTEMIS_RX6: D45.C, U50.RXI-0, U51.8
ARTEMIS_RX7: D52.C, U58.RXI-0, U59.8
ARTEMIS_RX8: D59.C, U66.RXI-0, U67.8
ARTEMIS_RX9: D66.C, U74.RXI-0, U75.8
ARTEMIS_RX10: D73.C, U82.RXI-0, U83.8
ARTEMIS_RX11: D80.C, U90.RXI-0, U91.8
ARTEMIS_RX12: D87.C, U98.RXI-0, U99.8
ARTEMIS_RX13: D94.C, U106.RXI-0, U107.8
ARTEMIS_RX14: D101.C, U114.RXI-0, U115.8
ARTEMIS_SWDCK: J14.4, U8.SWDCK
ARTEMIS_SWDCK1: J8.4, U6.SWDCK
ARTEMIS_SWDCK2: J19.4, U18.SWDCK
ARTEMIS_SWDCK3: J28.4, U26.SWDCK
ARTEMIS_SWDCK4: J37.4, U34.SWDCK
ARTEMIS_SWDCK5: J46.4, U42.SWDCK
ARTEMIS_SWDCK6: J55.4, U50.SWDCK
ARTEMIS_SWDCK7: J64.4, U58.SWDCK
ARTEMIS_SWDCK8: J73.4, U66.SWDCK
ARTEMIS_SWDCK9: J82.4, U74.SWDCK
ARTEMIS_SWDCK10: J91.4, U82.SWDCK
ARTEMIS_SWDCK11: J100.4, U90.SWDCK
ARTEMIS_SWDCK12: J109.4, U98.SWDCK
ARTEMIS_SWDCK13: J118.4, U106.SWDCK
ARTEMIS_SWDCK14: J127.4, U114.SWDCK
ARTEMIS_SWDIO: J14.2, U8.SWDIO
ARTEMIS_SWDIO1: J8.2, U6.SWDIO
ARTEMIS_SWDIO2: J19.2, U18.SWDIO
ARTEMIS_SWDIO3: J28.2, U26.SWDIO
ARTEMIS_SWDIO4: J37.2, U34.SWDIO
ARTEMIS_SWDIO5: J46.2, U42.SWDIO
ARTEMIS_SWDIO6: J55.2, U50.SWDIO
ARTEMIS_SWDIO7: J64.2, U58.SWDIO
ARTEMIS_SWDIO8: J73.2, U66.SWDIO
ARTEMIS_SWDIO9: J82.2, U74.SWDIO
ARTEMIS_SWDIO10: J91.2, U82.SWDIO
ARTEMIS_SWDIO11: J100.2, U90.SWDIO
ARTEMIS_SWDIO12: J109.2, U98.SWDIO
ARTEMIS_SWDIO13: J118.2, U106.SWDIO
ARTEMIS_SWDIO14: J127.2, U114.SWDIO
ARTEMIS_TX0: D12.C, U8.TXO-0, U10.9
ARTEMIS_TX1: D8.C, U6.TXO-0, U7.9
ARTEMIS_TX2: D18.C, U18.TXO-0, U19.9
ARTEMIS_TX3: D25.C, U26.TXO-0, U27.9
ARTEMIS_TX4: D32.C, U34.TXO-0, U35.9
ARTEMIS_TX5: D39.C, U42.TXO-0, U43.9
ARTEMIS_TX6: D46.C, U50.TXO-0, U51.9
ARTEMIS_TX7: D53.C, U58.TXO-0, U59.9
ARTEMIS_TX8: D60.C, U66.TXO-0, U67.9
ARTEMIS_TX9: D67.C, U74.TXO-0, U75.9
ARTEMIS_TX10: D74.C, U82.TXO-0, U83.9
ARTEMIS_TX11: D81.C, U90.TXO-0, U91.9
ARTEMIS_TX12: D88.C, U98.TXO-0, U99.9
ARTEMIS_TX13: D95.C, U106.TXO-0, U107.9
ARTEMIS_TX14: D102.C, U114.TXO-0, U115.9
ARTEMIS_~AD1: J13.1, U6.~AD11
ARTEMIS_~AD2: J13.4, U6.~AD32
ARTEMIS_~AD3: J23.1, U18.~AD11
ARTEMIS_~AD4: J23.4, U18.~AD32
ARTEMIS_~AD5: J32.1, U26.~AD11
ARTEMIS_~AD6: J32.4, U26.~AD32
ARTEMIS_~AD7: J41.1, U34.~AD11
ARTEMIS_~AD8: J41.4, U34.~AD32
ARTEMIS_~AD9: J50.1, U42.~AD11
ARTEMIS_~AD10: J50.4, U42.~AD32
ARTEMIS_~AD11: J4.1, U8.~AD11
ARTEMIS_~AD12: J59.1, U50.~AD11
ARTEMIS_~AD12/TX1: J4.3, U8.~AD12
ARTEMIS_~AD12/TX2: J13.3, U6.~AD12
ARTEMIS_~AD12/TX3: J23.3, U18.~AD12
ARTEMIS_~AD12/TX4: J32.3, U26.~AD12
ARTEMIS_~AD12/TX5: J41.3, U34.~AD12
ARTEMIS_~AD12/TX6: J50.3, U42.~AD12
ARTEMIS_~AD12/TX7: J59.3, U50.~AD12
ARTEMIS_~AD12/TX8: J68.3, U58.~AD12
ARTEMIS_~AD12/TX9: J77.3, U66.~AD12
ARTEMIS_~AD12/TX10: J86.3, U74.~AD12
ARTEMIS_~AD12/TX11: J95.3, U82.~AD12
ARTEMIS_~AD12/TX12: J104.3, U90.~AD12
ARTEMIS_~AD12/TX13: J113.3, U98.~AD12
ARTEMIS_~AD12/TX14: J122.3, U106.~AD12
ARTEMIS_~AD12/TX15: J131.3, U114.~AD12
ARTEMIS_~AD13: J59.4, U50.~AD32
ARTEMIS_~AD13/RX1: J4.2, U8.~AD13
ARTEMIS_~AD13/RX2: J13.2, U6.~AD13
ARTEMIS_~AD13/RX3: J23.2, U18.~AD13
ARTEMIS_~AD13/RX4: J32.2, U26.~AD13
ARTEMIS_~AD13/RX5: J41.2, U34.~AD13
ARTEMIS_~AD13/RX6: J50.2, U42.~AD13
ARTEMIS_~AD13/RX7: J59.2, U50.~AD13
ARTEMIS_~AD13/RX8: J68.2, U58.~AD13
ARTEMIS_~AD13/RX9: J77.2, U66.~AD13
ARTEMIS_~AD13/RX10: J86.2, U74.~AD13
ARTEMIS_~AD13/RX11: J95.2, U82.~AD13
ARTEMIS_~AD13/RX12: J104.2, U90.~AD13
ARTEMIS_~AD13/RX13: J113.2, U98.~AD13
ARTEMIS_~AD13/RX14: J122.2, U106.~AD13
ARTEMIS_~AD13/RX15: J131.2, U114.~AD13
ARTEMIS_~AD14: J68.1, U58.~AD11
ARTEMIS_~AD15: J68.4, U58.~AD32
ARTEMIS_~AD16: J77.1, U66.~AD11
ARTEMIS_~AD17: J77.4, U66.~AD32
ARTEMIS_~AD18: J86.1, U74.~AD11
ARTEMIS_~AD19: J86.4, U74.~AD32
ARTEMIS_~AD20: J95.1, U82.~AD11
ARTEMIS_~AD21: J95.4, U82.~AD32
ARTEMIS_~AD22: J104.1, U90.~AD11
ARTEMIS_~AD23: J104.4, U90.~AD32
ARTEMIS_~AD24: J113.1, U98.~AD11
ARTEMIS_~AD25: J113.4, U98.~AD32
ARTEMIS_~AD26: J122.1, U106.~AD11
ARTEMIS_~AD27: J122.4, U106.~AD32
ARTEMIS_~AD28: J131.1, U114.~AD11
ARTEMIS_~AD29: J131.4, U114.~AD32
ARTEMIS_~AD32: J4.4, U8.~AD32
CC1: J15.B5, R15.2
CC2: J15.A5, R16.2
CC3: J5.B5, R26.2
CC4: J5.A5, R27.2
CC5: J24.B5, R55.2
CC6: J24.A5, R56.2
CC7: J33.B5, R79.2
CC8: J33.A5, R80.2
CC9: J42.B5, R103.2
CC10: J42.A5, R104.2
CC11: J51.B5, R127.2
CC12: J51.A5, R128.2
CC13: J60.B5, R151.2
CC14: J60.A5, R152.2
CC15: J69.B5, R175.2
CC16: J69.A5, R176.2
CC17: J78.B5, R199.2
CC18: J78.A5, R200.2
CC19: J87.B5, R223.2
CC20: J87.A5, R224.2
CC21: J96.B5, R247.2
CC22: J96.A5, R248.2
CC23: J105.B5, R271.2
CC24: J105.A5, R272.2
CC25: J114.B5, R295.2
CC26: J114.A5, R296.2
CC27: J123.B5, R319.2
CC28: J123.A5, R320.2
CC29: J132.B5, R343.2
CC30: J132.A5, R344.2
CHG_LED: R5.1, U2.1
CHG_LED1: R10.1, U5.1
CHG_LED2: R50.1, U17.1
CHG_LED3: R74.1, U25.1
CHG_LED4: R98.1, U33.1
CHG_LED5: R122.1, U41.1
CHG_LED6: R146.1, U49.1
CHG_LED7: R170.1, U57.1
CHG_LED8: R194.1, U65.1
CHG_LED9: R218.1, U73.1
CHG_LED10: R242.1, U81.1
CHG_LED11: R266.1, U89.1
CHG_LED12: R290.1, U97.1
CHG_LED13: R314.1, U105.1
CHG_LED14: R338.1, U113.1
D+1: J15.A6, J15.B6, U7.1
D+2: J5.A6, J5.B6, U10.1
D+3: J24.A6, J24.B6, U19.1
D+4: J33.A6, J33.B6, U27.1
D+5: J42.A6, J42.B6, U35.1
D+6: J51.A6, J51.B6, U43.1
D+7: J60.A6, J60.B6, U51.1
D+8: J69.A6, J69.B6, U59.1
D+9: J78.A6, J78.B6, U67.1
D+10: J87.A6, J87.B6, U75.1
D+11: J96.A6, J96.B6, U83.1
D+12: J105.A6, J105.B6, U91.1
D+13: J114.A6, J114.B6, U99.1
D+14: J123.A6, J123.B6, U107.1
D+15: J132.A6, J132.B6, U115.1
D-1: J15.A7, J15.B7, U7.2
D-2: J5.A7, J5.B7, U10.2
D-3: J24.A7, J24.B7, U19.2
D-4: J33.A7, J33.B7, U27.2
D-5: J42.A7, J42.B7, U35.2
D-6: J51.A7, J51.B7, U43.2
D-7: J60.A7, J60.B7, U51.2
D-8: J69.A7, J69.B7, U59.2
D-9: J78.A7, J78.B7, U67.2
D-10: J87.A7, J87.B7, U75.2
D-11: J96.A7, J96.B7, U83.2
D-12: J105.A7, J105.B7, U91.2
D-13: J114.A7, J114.B7, U99.2
D-14: J123.A7, J123.B7, U107.2
D-15: J132.A7, J132.B7, U115.2
DAT1: J6.DAT1, U8.~D26
DAT2: J6.DAT2, U8.~D4
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

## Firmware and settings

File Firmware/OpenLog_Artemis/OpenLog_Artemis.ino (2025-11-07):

/*
  OpenLog Artemis
  By: Nathan Seidle and Paul Clark
  SparkFun Electronics
  Date: November 26th, 2019
  License: MIT. Please see LICENSE.md for more details.
  Feel like supporting our work? Buy a board from SparkFun!
  https://www.sparkfun.com/products/16832
  https://www.sparkfun.com/products/19426

  This firmware runs the OpenLog Artemis. A large variety of system settings can be
  adjusted by connecting at 115200bps.

  The Board should be set to SparkFun Apollo3 \ RedBoard Artemis ATP.

  v1.0 Power Consumption:
   Sleep between reads, RTC fully charged, no Qwiic, SD, no USB, no Power LED: 260uA
   10Hz logging IMU, no Qwiic, SD, no USB, no Power LED: 9-27mA

  TODO:
  (done) Create settings file for sensor. Load after qwiic bus is scanned.
  (done on larger Strings) Remove String dependencies.
  (done) Bubble sort list of devices.
  (done) Remove listing for muxes.
  (done) Verify the printing of all sensors is %f, %d correct
  (done) Add begin function seperate from everything, call after wakeup instead of detect
  (done) Add counter to output to look for memory leaks on long runs
  (done) Add AHT20 support
  (done) Add SHTC3 support
  (done) Change settings extension to txt
  (done) Fix max I2C speed to use linked list
  Currently device settings are not recorded to EEPROM, only deviceSettings.txt
  Is there a better way to dynamically create size of sdOutputData array so we don't ever get larger than X sensors outputting?
  Find way to store device configs into EEPROM
  Log four pressure sensors and graph them on plotter
  (checked) Test GPS - not sure about %d with int32s. Does lat, long, and alt look correct?
  (done) Test NAU7802s
  (done) Test SCD30s (Add an extended delay for the SCD30. (Issue #5))
  (won't do?) Add a 'does not like to be powered cycled' setting for each device type. I think this has been superceded by "Add individual power-on delays for each sensor type?.
  (done) Add support for logging VIN
  (done) Investigate error in time between logs (https://github.com/sparkfun/OpenLog_Artemis/issues/13)
  (done) Invesigate RTC reset issue (https://github.com/sparkfun/OpenLog_Artemis/issues/13 + https://forum.sparkfun.com/viewtopic.php?f=123&t=53157)
    The solution is to make sure that the OLA goes into deep sleep as soon as the voltage monitor detects that the power has failed.
    The user will need to press the reset button once power has been restored. Using the WDT to check the monitor and do a POR wasn't reliable.
  (done) Investigate requires-reset issue on battery power (") (X04 + CCS811/BME280 enviro combo)
  (done) Add a fix so that the MS8607 does not also appear as an MS5637
  (done) Add "set RTC from GPS" functionality
  (done) Add UTCoffset functionality (including support for negative numbers)
  (done) Figure out how to give the u-blox time to establish a fix if it has been powered down between log intervals. The user can specify up to 60s for the Qwiic power-on delay.
  Add support for VREG_ENABLE
  (done) Add support for PWR_LED
  (done) Use the WDT to reset the Artemis when power is reconnected (previously the Artemis would have stayed in deep sleep)
  Add a callback function to the u-blox library so we can abort waiting for UBX data if the power goes low
  (done) Add support for the ADS122C04 ADC (Qwiic PT100)
  (done) Investigate why usBetweenReadings appears to be longer than expected. We needed to read millis _before_ enabling the lower power clock!
  (done) Correct u-blox pull-ups
  (done) Add an olaIdentifier to prevent problems when using two code variants that have the same sizeOfSettings
  (done) Add a fix for the IMU wake-up issue identified in https://github.com/sparkfun/OpenLog_Artemis/issues/18
  (done) Add a "stop logging" feature on GPIO 32: allow the pin to be used to read a stop logging button instead of being an analog input
  (done) Allow the user to set the default qwiic bus pull-up resistance (u-blox will still use 'none')
  (done) Add support for low battery monitoring using VIN
  (done) Output sensor data via the serial TX pin (Issue #32)
  (done) Add support for SD card file transfer (ZMODEM) and delete. (Issue #33) With thanks to: ecm-bitflipper (https://github.com/ecm-bitflipper/Arduino_ZModem)
  (done) Add file creation and access timestamps
  (done) Add the ability to trigger data collection via Pin 11 (Issue #36)
  (done) Correct the measurement count misbehaviour (Issue #31)
  (done) Use the corrected IMU temperature calculation (Issue #28)
  (done) Add individual power-on delays for each sensor type. Add an extended delay for the SCD30. (Issue #5)
  (done) v1.7: Fix readVin after sleep bug: https://github.com/sparkfun/OpenLog_Artemis/issues/39
  (done) Change detectQwiicDevices so that the MCP9600 (Qwiic Thermocouple) is detected correctly
  (done) Add support for the MPRLS0025PA micro pressure sensor
  (done) Add support for the SN-GCJA5 particle sensor
  (done) Add IMU accelerometer and gyro full scale and digital low pass filter settings to menuIMU
  (done) Add a fix to make sure the MS8607 is detected correctly: https://github.com/sparkfun/OpenLog_Artemis/issues/54
  (done) Add logMicroseconds: https://github.com/sparkfun/OpenLog_Artemis/issues/49
  (done) Add an option to use autoPVT when logging GNSS data: https://github.com/sparkfun/OpenLog_Artemis/issues/50
  (done) Corrected an issue when using multiple MS8607's: https://github.com/sparkfun/OpenLog_Artemis/issues/62
  (done) Add a feature to use the TX and RX pins as a duplicate Terminal
  (done) Add serial log timestamps with a token (as suggested by @DennisMelamed in PR https://github.com/sparkfun/OpenLog_Artemis/pull/70 and Issue https://github.com/sparkfun/OpenLog_Artemis/issues/63)
  (done) Add "sleep on pin" functionality based @ryanneve's PR https://github.com/sparkfun/OpenLog_Artemis/pull/64 and Issue https://github.com/sparkfun/OpenLog_Artemis/issues/46
  (done) Add "wake at specified times" functionality based on Issue https://github.com/sparkfun/OpenLog_Artemis/issues/46
  (done) Add corrections for the SCD30 based on Forum post by paulvha: https://forum.sparkfun.com/viewtopic.php?p=222455#p222455
  (done) Add support for the SGP40 VOC Index sensor
  (done) Add support for the SDP3X Differential Pressure sensor
  (done) Add support for the MS5837 - as used in the BlueRobotics BAR02 and BAR30 water pressure sensors
  (done) Correct an issue which was causing the OLA to crash when waking from sleep and outputting serial data https://github.com/sparkfun/OpenLog_Artemis/issues/79
  (done) Correct low-power code as per https://github.com/sparkfun/OpenLog_Artemis/issues/78
  (done) Correct a bug in menuAttachedDevices when useTxRxPinsForTerminal is enabled https://github.com/sparkfun/OpenLog_Artemis/issues/82
  (done) Add ICM-20948 DMP support. Requires v1.2.6 of the ICM-20948 library. DMP logging is limited to: Quat6 or Quat9, plus raw accel, gyro and compass. https://github.com/sparkfun/OpenLog_Artemis/issues/47
  (done) Add support for exFAT. Requires v2.0.6 of Bill Greiman's SdFat library. https://github.com/sparkfun/OpenLog_Artemis/issues/34
  (done) Add minimum awake time: https://github.com/sparkfun/OpenLog_Artemis/issues/83
  (done) Add support for the Pulse Oximeter: https://github.com/sparkfun/OpenLog_Artemis/issues/81
  (done - but does not work) Add support for the Qwiic Button. The QB uses clock-stretching and the Artemis really doesn't enjoy that...
  (done) Increase DMP data resolution to five decimal places https://github.com/sparkfun/OpenLog_Artemis/issues/90

  (in progress) Update to Apollo3 v2.1.0 - FIRMWARE_VERSION_MAJOR = 2.
  (done) Implement printf float (OLA uses printf float in _so_ many places...): https://github.com/sparkfun/Arduino_Apollo3/issues/278
  (worked around) attachInterrupt(PIN_POWER_LOSS, powerDownOLA, FALLING); triggers an immediate interrupt - https://github.com/sparkfun/Arduino_Apollo3/issues/416
  (done) Add a setQwiicPullups function
  (done) Check if we need ap3_set_pin_to_analog when coming out of sleep
  (done) Investigate why code does not wake from deep sleep correctly
  (worked around) Correct SerialLog RX: https://github.com/sparkfun/Arduino_Apollo3/issues/401
    The work-around is to use Serial1 in place of serialLog and then to manually force UART1 to use pins 12 and 13
    We need a work-around anyway because if pins 12 or 13 have been used as analog inputs, Serial1.begin does not re-configure them for UART TX and RX
  (in progress) Reduce sleep current as much as possible. v1.2.1 achieved ~110uA. With v2.1.0 the draw is more like 260uA...

  (in progress) Update to Apollo3 v2.2.0 - FIRMWARE_VERSION_MAJOR = 2; FIRMWARE_VERSION_MINOR = 1.
  (done) Add a fix for issue #109 - check if a BME280 is connected before calling multiplexerBegin: https://github.com/sparkfun/OpenLog_Artemis/issues/109
  (done) Correct issue #104. enableSD was redundant. The microSD power always needs to be on if there is a card inserted, otherwise the card pulls
         the SPI lines low, preventing communication with the IMU:  https://github.com/sparkfun/OpenLog_Artemis/issues/104
  (done) Add support for TMP102 temperature sensor (while differentating between it and the ADS1015 (which share the same 4 addresses starting at 0x48)

  v2.2:
    Use Apollo3 v2.2.1 with changes by paulvha to fix Issue 117 (Thank you Paul!)
      https://github.com/sparkfun/OpenLog_Artemis/issues/117#issuecomment-1085881142
    Also includes Paul's SPI.end fix
      https://github.com/sparkfun/Arduino_Apollo3/issues/442
      In libraries/SPI/src/SPI.cpp change end() to:
        void arduino::MbedSPI::end() {
            if (dev) {
                delete dev;
                dev = NULL;
            }
        }      
    Use SdFat v2.1.2
    Compensate for missing / not-populated IMU
    Add support for yyyy/mm/dd and ISO 8601 date style (Issue 118)
    Add support for fractional time zone offsets

  v2.3 BETA:
    Change GNSS maximum rate to 25Hz as per:
      https://github.com/sparkfun/OpenLog_Artemis/issues/121
      https://forum.sparkfun.com/viewtopic.php?f=172&t=57512
    Decided not to include this in the next full release.
    I suspect it will cause major badness on (e.g.) M8 modules that cannot support 25Hz.
    
  v2.3:
    Resolve https://forum.sparkfun.com/viewtopic.php?f=171&t=58109

  v2.4:
    Add noPowerLossProtection to the main branch
    Add changes by KDB: If we are streaming to Serial, start the stream with a Mime Type marker, followed by CR
    Add debug option to only open the menu using a printable character: based on https://github.com/sparkfun/OpenLog_Artemis/pull/125

  v2.5:
    Add Tony Whipple's PR #146 - thank you @whipple63
    Add support for the ISM330DHCX, MMC5983MA, KX134 and ADS1015
    Resolve issue #87

  v2.6:
    Add support for the LPS28DFW - thank you @gauteh #179
    Only disable I2C SDA and SCL during sleep when I2C bus is being powered down - thank you @whipple63 #167
    Add calibrationConcentration support for the SCD30 - thank you @hotstick #181
    Add limited support for the VEML7700 light sensor

  v2.7:
    Resolve serial logging issue - crash on startup - #182

  v2.8:
    Corrects the serial token timestamp printing - resolves #192
    The charsReceived debug print ("Total chars received: ") now excludes the length of the timestamps
    Consistent use of File32/ExFile/FsFile/File. Don't use SdFile for temporary files

  v2.9
    Adds support for TMP102 low(er) cost temperature sensor

  v2.10
    Restructure the serial logging code in loop()
    Where possible, write residual serial data to file before closing

  v2.11
    Add support for LPS28DFW Mode 2 (4060 hPa) - thank you @thebrownhobbit-commits #221
*/

const int FIRMWARE_VERSION_MAJOR = 2;
const int FIRMWARE_VERSION_MINOR = 11;

//Define the OLA board identifier:
//  This is an int which is unique to this variant of the OLA and which allows us
//  to make sure that the settings in EEPROM are correct for this version of the OLA
//  (sizeOfSettings is not necessarily unique and we want to avoid problems when swapping from one variant to another)
//  It is the sum of:
//    the variant * 0x100 (OLA = 1; GNSS_LOGGER = 2; GEOPHONE_LOGGER = 3)
//    the major firmware version * 0x10
//    the minor firmware version
#define OLA_IDENTIFIER 0x12B // Stored as 299 decimal in OLA_settings.txt

//#define noPowerLossProtection // Uncomment this line to disable the sleep-on-power-loss functionality

#include "Sensors.h"

#include "settings.h"

//Define the pin functions
//Depends on hardware version. This can be found as a marking on the PCB.
//x04 was the SparkX 'black' version.
//v10 was the first red version.
#define HARDWARE_VERSION_MAJOR 1
#define HARDWARE_VERSION_MINOR 0

#if(HARDWARE_VERSION_MAJOR == 0 && HARDWARE_VERSION_MINOR == 4)
const byte PIN_MICROSD_CHIP_SELECT = 10;
const byte PIN_IMU_POWER = 22;
#elif(HARDWARE_VERSION_MAJOR == 1 && HARDWARE_VERSION_MINOR == 0)
const byte PIN_MICROSD_CHIP_SELECT = 23;
const byte PIN_IMU_POWER = 27;
const byte PIN_PWR_LED = 29;
const byte PIN_VREG_ENABLE = 25;
const byte PIN_VIN_MONITOR = 34; // VIN/3 (1M/2M - will require a correction factor)
#endif

const byte PIN_POWER_LOSS = 3;
//const byte PIN_LOGIC_DEBUG = 11; // Useful for debugging issues like the slippery mux bug
const byte PIN_MICROSD_POWER = 15;
const byte PIN_QWIIC_POWER = 18;
const byte PIN_STAT_LED = 19;
const byte PIN_IMU_INT = 37;
const byte PIN_IMU_CHIP_SELECT = 44;
const byte PIN_STOP_LOGGING = 32;
const byte BREAKOUT_PIN_32 = 32;
const byte BREAKOUT_PIN_TX = 12;
const byte BREAKOUT_PIN_RX = 13;
const byte BREAKOUT_PIN_11 = 11;
const byte PIN_TRIGGER = 11;
const byte PIN_QWIIC_SCL = 8;
const byte PIN_QWIIC_SDA = 9;

const byte PIN_SPI_SCK = 5;
const byte PIN_SPI_CIPO = 6;
const byte PIN_SPI_COPI = 7;

// Include this many extra bytes when starting a mux - to try and avoid the slippery mux bug
// This should be 0 but 3 or 7 seem to work better depending on which way the wind is blowing.
const byte EXTRA_MUX_STARTUP_BYTES = 3;

enum returnStatus {
  STATUS_GETBYTE_TIMEOUT = 255,
  STATUS_GETNUMBER_TIMEOUT = -123455555,
  STATUS_PRESSED_X,
};

//Setup Qwiic Port
//-=-=-=-=-=-=-=-=-=-=-=-=-=-=-=-=-=-=-=-=-=-=-=-=-=-=-=-=-=-=-=-=-
#include <Wire.h>
TwoWire qwiic(PIN_QWIIC_SDA,PIN_QWIIC_SCL); //Will use pads 8/9
//-=-=-=-=-=-=-=-=-=-=-=-=-=-=-=-=-=-=-=-=-=-=-=-=-=-=-=-=-=-=-=-=-

//EEPROM for storing settings
//-=-=-=-=-=-=-=-=-=-=-=-=-=-=-=-=-=-=-=-=-=-=-=-=-=-=-=-=-=-=-=-=-
#include <EEPROM.h>
//-=-=-=-=-=-=-=-=-=-=-=-=-=-=-=-=-=-=-=-=-=-=-=-=-=-=-=-=-=-=-=-=-

//microSD Interface
//-=-=-=-=-=-=-=-=-=-=-=-=-=-=-=-=-=-=-=-=-=-=-=-=-=-=-=-=-=-=-=-=-
#include <SPI.h>

#include <SdFat.h> //SdFat by Bill Greiman: http://librarymanager/All#SdFat_exFAT

#define SD_FAT_TYPE 3 // SD_FAT_TYPE = 0 for SdFat/File, 1 for FAT16/FAT32, 2 for exFAT, 3 for FAT16/FAT32 and exFAT.
#define SD_CONFIG SdSpiConfig(PIN_MICROSD_CHIP_SELECT, SHARED_SPI, SD_SCK_MHZ(24)) // 24MHz

#if SD_FAT_TYPE == 1
SdFat32 sd;
File32 sensorDataFile; //File that all sensor data is written to
File32 serialDataFile; //File that all incoming serial data is written to
#elif SD_FAT_TYPE == 2
SdExFat sd;
ExFile sensorDataFile; //File that all sensor data is written to
ExFile serialDataFile; //File that all incoming serial data is written to
#elif SD_FAT_TYPE == 3
SdFs sd;
FsFile sensorDataFile; //File that all sensor data is written to
FsFile serialDataFile; //File that all incoming serial data is written to
#else // SD_FAT_TYPE == 0
SdFat sd;
File sensorDataFile; //File that all sensor data is written to
File serialDataFile; //File that all incoming serial data is written to
#endif  // SD_FAT_TYPE

//#define PRINT_LAST_WRITE_TIME // Uncomment this line to enable the 'measure the time between writes' diagnostic
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
void loop() {

  checkBattery(); // Check for low battery

  if ((Serial.available()) || ((settings.useTxRxPinsForTerminal == true) && (Serial1.available())))
    menuMain(); //Present user menu

  if (settings.logSerial == true && online.serialLogging == true && settings.useTxRxPinsForTerminal == false)
  {
    // v2.10 - this code has been restructured....

    // The writing of the timestamp has the highest priority
    if (strlen(serialTimestamp) > 0)
    {
      while (strlen(serialTimestamp) > 0) // Copy all timestamp chars into incomingBuffer
      {
        incomingBuffer[incomingBufferSpot++] = serialTimestamp[0]; // Add a timestamp character to incomingBuffer

        size_t timestampCharsLeftToWrite = strlen(serialTimestamp);
        for (size_t i = 0; i < timestampCharsLeftToWrite; i++)
        {
          serialTimestamp[i] = serialTimestamp[i+1]; // Shuffle the remaining chars along by one, including the NULL terminator
        }

        if (incomingBufferSpot == sizeof(incomingBuffer))
        {
          digitalWrite(PIN_STAT_LED, HIGH); //Toggle stat LED to indicating log recording
          serialDataFile.write(incomingBuffer, sizeof(incomingBuffer)); //Record the buffer to the card
          digitalWrite(PIN_STAT_LED, LOW);
          incomingBufferSpot = 0;

          //If we are sleeping between readings then we cannot rely on millis() as it is powered down
          //Use RTC instead
          lastSeriaLogSyncTime = rtcMillis(); //Reset the last sync time to now

          checkBattery();
        }
      }
    }

    // Now check for incoming serial data. Process bytes until a timestamp token is detected
    if (Serial1.available())
    {
      while ((Serial1.available()) && (strlen(serialTimestamp) == 0))
      {
        incomingBuffer[incomingBufferSpot++] = Serial1.read();
        charsReceived++;

        //Get the RTC timestamp if we just received the timestamp token
        if (settings.timestampSerial && (incomingBuffer[incomingBufferSpot-1] == settings.timeStampToken))
        {
          getTimeString(&serialTimestamp[2]);
          serialTimestamp[0] = 0x0A; // Add Line Feed at the start of the timestamp
          serialTimestamp[1] = '^'; // Add an up-arrow to indicate the timestamp relates to the preceeding data
          serialTimestamp[strlen(serialTimestamp) - 1] = 0x0A; // Change the final comma of the timestamp to a Line Feed
        }

        if (incomingBufferSpot == sizeof(incomingBuffer))
        {
          digitalWrite(PIN_STAT_LED, HIGH); //Toggle stat LED to indicating log recording
          serialDataFile.write(incomingBuffer, sizeof(incomingBuffer)); //Record the buffer to the card
          digitalWrite(PIN_STAT_LED, LOW);
          incomingBufferSpot = 0;

          //If we are sleeping between readings then we cannot rely on millis() as it is powered down
          //Use RTC instead
          lastSeriaLogSyncTime = rtcMillis(); //Reset the last sync time to now

          checkBattery();
        }
      }
    }

    // Periodically sync data to SD
    if ((rtcMillis() - lastSeriaLogSyncTime) > MAX_IDLE_TIME_MSEC) //If we haven't logged any characters recently then sync log file
    {
      if (incomingBufferSpot > 0)
      {
        //Write the remainder of the buffer
        digitalWrite(PIN_STAT_LED, HIGH); //Toggle stat LED to indicating log recording
        serialDataFile.write(incomingBuffer, incomingBufferSpot); //Record the buffer to the card
        serialDataFile.sync();
        if (settings.frequentFileAccessTimestamps == true)
          updateDataFileAccess(&serialDataFile); // Update the file access time & date
        digitalWrite(PIN_STAT_LED, LOW);

        incomingBufferSpot = 0;

        lastSeriaLogSyncTime = rtcMillis(); //Reset the last sync time to now
        printDebug("Total chars received: " + (String)charsReceived + "\r\n");

        checkBattery();
      }
    }
  }

  //In v2.1 of the core micros() becomes corrupted during deep sleep so only test if we are not sleeping
  if (settings.usBetweenReadings < maxUsBeforeSleep)
  {
    if ((micros() - lastReadTime) >= settings.usBetweenReadings)
      takeReading = true;
  }

  //Check for a trigger event
  if (settings.useGPIO11ForTrigger == true)
  {
    if (triggerEdgeSeen == true)
    {
      takeReading = true; // If triggering is enabled and a trigger event has been seen, then take a reading.
    }
    else
    {
      takeReading = false; // If triggering is enabled and a trigger even has not been seen, then make sure we don't take a reading based on settings.usBetweenReadings.
    }
  }

  //Is it time to get new data?
  if ((settings.logMaxRate == true) || (takeReading == true))
  {
    takeReading = false;
    lastReadTime = micros();

#ifdef PRINT_LAST_WRITE_TIME
    if (settings.printDebugMessages)
    {
      // Print how long it has been since the last write
      char tempTimeRev[20]; // Char array to hold to usBR (reversed order)
      char tempTime[20]; // Char array to hold to usBR (correct order)
      static uint64_t lastWriteTime; //Used to calculate the time since the last SD write (sleep-proof)
      unsigned long usBR = rtcMillis() - lastWriteTime;
      unsigned int i = 0;
      if (usBR == 0ULL) // if usBetweenReadings is zero, set tempTime to "0"
      {
        tempTime[0] = '0';
        tempTime[1] = 0;
      }
      else
      {
        while (usBR > 0)
        {
          tempTimeRev[i++] = (usBR % 10) + '0'; // divide by 10, convert the remainder to char
          usBR /= 10; // divide by 10
        }
        unsigned int j = 0;
        while (i > 0)
        {
          tempTime[j++] = tempTimeRev[--i]; // reverse the order
          tempTime[j] = 0; // mark the end with a NULL
        }
      }

      //printDebug("ms since last write: " + (String)tempTime + "\r\n");
      printDebug((String)tempTime + "\r\n");

      lastWriteTime = rtcMillis();
    }
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

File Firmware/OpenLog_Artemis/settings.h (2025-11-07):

#include "SparkFun_PHT_MS8607_Arduino_Library.h" //Click here to get the library: http://librarymanager/All#SparkFun_PHT_MS8607
#include "SparkFun_ISM330DHCX.h" // Click here to get the library: http://librarymanager/All#SparkFun_6DoF_ISM330DHCX

typedef enum
{
  DEVICE_MULTIPLEXER = 0,
  DEVICE_LOADCELL_NAU7802,
  DEVICE_DISTANCE_VL53L1X,
  DEVICE_GPS_UBLOX,
  DEVICE_PROXIMITY_VCNL4040,
  DEVICE_TEMPERATURE_TMP117,
  DEVICE_PRESSURE_MS5637,
  DEVICE_PRESSURE_LPS25HB,
  DEVICE_PHT_BME280,
  DEVICE_UV_VEML6075,
  DEVICE_VOC_CCS811,
  DEVICE_VOC_SGP30,
  DEVICE_CO2_SCD30,
  DEVICE_PHT_MS8607,
  DEVICE_TEMPERATURE_MCP9600,
  DEVICE_HUMIDITY_AHT20,
  DEVICE_HUMIDITY_SHTC3,
  DEVICE_ADC_ADS122C04,
  DEVICE_PRESSURE_MPR0025PA1, // 0-25 PSI, I2C Address 0x18
  DEVICE_PARTICLE_SNGCJA5,
  DEVICE_VOC_SGP40,
  DEVICE_PRESSURE_SDP3X,
  DEVICE_PRESSURE_MS5837,
  DEVICE_QWIIC_BUTTON,
  DEVICE_BIO_SENSOR_HUB,
  DEVICE_ISM330DHCX,
  DEVICE_MMC5983MA,
  DEVICE_KX134,
  DEVICE_ADS1015,
  DEVICE_PRESSURE_LPS28DFW,
  DEVICE_LIGHT_VEML7700,
  DEVICE_TEMPERATURE_TMP102,


  DEVICE_TOTAL_DEVICES, //Marks the end, used to iterate loops
  DEVICE_UNKNOWN_DEVICE,
} deviceType_e;

struct node
{
  deviceType_e deviceType;

  uint8_t address = 0;
  uint8_t portNumber = 0;
  uint8_t muxAddress = 0;
  bool online = false; //Goes true once successfully begin()'d

  void *classPtr; //Pointer to this devices' class instantiation
  void *configPtr; //The struct containing this devices logging options
  node *next;
};

node *head = NULL;
node *tail = NULL;

typedef void (*FunctionPointer)(void*); //Used for pointing to device config menus

//Begin specific sensor config structs
//-=-=-=-=-=-=-=-=-=-=-=-=-=-=-=-=-=-=-=-=-=-=-=-=-=-=-=-=-=-=-=-=-

const unsigned long worstCaseQwiicPowerOnDelay = 1000; // Remember to update this if required when adding a new sensor (currently defined by the u-blox). (This is OK for the SCD30. beginQwiicDevices will extend the delay.)
const unsigned long minimumQwiicPowerOnDelay = 10; //The minimum number of milliseconds between turning on the Qwiic power and attempting to communicate with Qwiic devices

// Power On Delay Testing:
// The minimum power-on delays for following sensors have been checked:
// Each sensor has been checked twice:
//   Fast case: as the only sensor linked to the OLA; IMU logging disabled
//   Slow case: when linked to the OLA along with a ZED-F9P (representing a heavy load on the Qwiic power regulator); IMU logging enabled.
// (Note: the delay is the value set via the "minimum Qwiic bus power up delay" menu option. It may not represent the actual sensor power-up delay, but it is the number the OLA needs to know.)
// (Note: the slow case is more about how fast the Qwiic power ramps up with a heavy load attached.)
//              Fast    Slow
// Multiplexer: 10ms    10ms
// LPS25HB:     10ms    10ms
// NAU7802:     10ms    10ms
// SHTC3:       10ms    10ms
// MS8607:      10ms    10ms
// SGP30:       10ms    10ms
// ADS122C04:   10ms    10ms
// SCD30:       5000ms  (Shorter delays seem to result in invalid CO2 readings?)
// u-blox:      1000ms

struct struct_multiplexer {
  //Ignore certain ports at detection step?
  unsigned long powerOnDelayMillis = minimumQwiicPowerOnDelay; // Wait for at least this many millis before communicating with this device. Increase if required!
};

//Add the new sensor settings below
struct struct_LPS25HB {
  bool log = true;
  bool logPressure = true;
  bool logTemperature = true;
  unsigned long powerOnDelayMillis = minimumQwiicPowerOnDelay; // Wait for at least this many millis before communicating with this device. Increase if required!
};

struct struct_LPS28DFW {
  bool log = true;
  bool logPressure = true;
  bool logTemperature = true;
  uint8_t mode = 1; //Allow selection of pressure mode 1 (260-1060 hPa) or mode 2 (260-4000 hPa)
  unsigned long powerOnDelayMillis = minimumQwiicPowerOnDelay; // Wait for at least this many millis before communicating with this device. Increase if required!
};
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

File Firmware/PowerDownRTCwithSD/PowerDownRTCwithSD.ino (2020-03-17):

/* Author: Nathan Seidle
  Created: Septempter 27th, 2019
  License: MIT. See SparkFun Arduino Apollo3 Project for more information

  This example demonstrates how to put the core to sleep for a number of
  milliseconds before waking and printing the current time/date. This
  is helpful for checking power consumption of the core while RTC+CT6 are running.

  3.2 microSD, no USB
  2.4 no microSD, no USB

  6mA with Power LED, no microSD, USB
  4.58, no power LED, no microSD, USB
  So power LED is ~1.5mA
  1.05mA no power, no microSD, no USB
  So USB is ~3.5mA
  Fully powered down, board is pulling 450uA from battery but that
  seems to be because RTC batt is charging at ~360uA.

  6.88 with microSD
  5.07 with microSD on?

  3/5/20 -
    6.61mA, no LED, USB, SD
    4.78mA, no LED, USB, no SD
    0.67mA, no LED, no USB, SD with pin set LOW
    0.65mA, no LED, no USB, SD with pin set HIGH
    0.16mA, no LED, no USB, no SD

  3/6/20
    0.65mA, no LED, no USB, Kingston 16GB SD
    0.152mA, no LED, no USB, SparkX SD
    0.191mA, no LED, no USB, SparkX SD
    0.188mA, no LED, no USB, SparkX SD
    0.098mA, no LEd, no USB, no SD

    Can we get 90uA lower when microSD is started and stopped?



*/

#include "RTC.h" //Include RTC library included with the Aruino_Apollo3 core
APM3_RTC myRTC; //Create instance of RTC class

#include <Wire.h>

//microSD Interface
//-=-=-=-=-=-=-=-=-=-=-=-=-=-=-=-=-=-=-=-=-=-=-=-=-=-=-=-=-=-=-=-=-
#include <SPI.h>
#include <SdFat.h> //We use SdFat-Beta from Bill Greiman for increased read/write speed

const byte PIN_MICROSD_CHIP_SELECT = 10;
const byte PIN_MICROSD_POWER = 15; //x04

#define SD_CONFIG SdSpiConfig(PIN_MICROSD_CHIP_SELECT, SHARED_SPI, SD_SCK_MHZ(24)) //Max of 24MHz
#define SD_CONFIG_MAX_SPEED SdSpiConfig(PIN_MICROSD_CHIP_SELECT, DEDICATED_SPI, SD_SCK_MHZ(24)) //Max of 24MHz

SdFat sd;
File sensorDataFile; //File that all sensor data is written to
File serialDataFile; //File that all incoming serial data is written to

//-=-=-=-=-=-=-=-=-=-=-=-=-=-=-=-=-=-=-=-=-=-=-=-=-=-=-=-=-=-=-=-=-

const byte PIN_POWER_LOSS = 3;

const byte LOGIC_DEBUG = 11;

const byte PIN_QWIIC_POWER = 18;
const byte PIN_IMU_POWER = 22;

//uint32_t msToSleep = 10; //This is the user editable number of ms to sleep between RTC checks
////#define TIMER_FREQ 3000000L //Counter/Timer 6 will use the HFRC oscillator of 3MHz
//#define TIMER_FREQ 32768 //Counter/Timer 6 will use the external 32kHz Xtal
//uint32_t sysTicksToSleep = msToSleep * (TIMER_FREQ / 1000);

void setup()
{
  pinMode(PIN_POWER_LOSS, INPUT);
  attachInterrupt(digitalPinToInterrupt(PIN_POWER_LOSS), powerDown, FALLING);

  Serial.begin(115200);
  Serial.println("SparkFun RTC Example");

  Wire.begin();

  qwiicPowerOff();
  microSDPowerOff();
  imuPowerOff();
  SPI.begin(); //Needed if SD is disabled

  beginSD();

  pinMode(LOGIC_DEBUG, OUTPUT);

  digitalWrite(LOGIC_DEBUG, HIGH);
  delay(50);
  digitalWrite(LOGIC_DEBUG, LOW);

  myRTC.getTime();
  Serial.printf(" %02d:", myRTC.hour);
  Serial.printf("%02d:", myRTC.minute);
  Serial.printf("%02d", myRTC.seconds);
  Serial.printf(" %02d/", myRTC.month);
  Serial.printf("%02d/", myRTC.dayOfMonth);
  Serial.printf("%02d", myRTC.year);
  Serial.println();

  Serial.println("d) Display time");
  Serial.println("s) Set RTC to compiler macro");
  Serial.println("r) System reset");
  Serial.println("p) Power down");
  Serial.println("q) Toggle Qwiic Power");
  Serial.println("m) Toggle microSD Power");

}

void loop()
{
  if (Serial.available())
  {
    byte choice = Serial.read();

    if (choice == 's')
    {
      Serial.println("Set RTC to compiler");
      myRTC.setToCompilerTime(); //Easily set RTC using the system __DATE__ and __TIME__ macros from compiler
      //myRTC.setTime(7, 28, 51, 0, 21, 10, 15); //Manually set RTC back to the future: Oct 21st, 2015 at 7:28.51 AM
      //myRTC.setTime(1, 0, 0, 0, 21, 10, 15); //Manually set RTC back to the future: Oct 21st, 2015 at 7:28.51 AM
    }
    else if (choice == 'r')
    {
      Serial.println("System reset");
      am_hal_reset_control(AM_HAL_RESET_CONTROL_SWPOI, 0); //Cause a system Power On Init to release as much of the stack as possible
    }
    else if (choice == 'p')
    {
      Serial.println("Power down");
      powerDown();
    }
    else if (choice == 'd')
    {
      myRTC.getTime();

      Serial.printf(" %02d:", myRTC.hour);
      Serial.printf("%02d:", myRTC.minute);
      Serial.printf("%02d", myRTC.seconds);

      Serial.printf(" %02d/", myRTC.month);
      Serial.printf("%02d/", myRTC.dayOfMonth);
      Serial.printf("%02d", myRTC.year);

      Serial.println();

    }
    else if (choice == 'q')
    {
      Serial.println("Toggle Qwiic Power");
      if (digitalRead(PIN_QWIIC_POWER) == HIGH)
      {
        qwiicPowerOn();
        Serial.println("Qwiic Power On / Pin Low");
      }
      else
      {
        qwiicPowerOff();
        Serial.println("Qwiic Power Off / Pin High");
      }
    }
    else if (choice == 'm')
    {
      Serial.println("Toggle microSD Power");
      if (digitalRead(PIN_MICROSD_POWER) == HIGH)
      {
        microSDPowerOn();
        Serial.println("microSD On / Pin Low");
      }
      else
      {
        microSDPowerOff();
        Serial.println("microSD Off / Pin High");
      }
    }    while (Serial.available()) Serial.read();
  }
}
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

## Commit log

2019-12-12 Add RTC cap. Remove switch. Add Qwiic MOSFET.
    [SparkFun_Artemis_OpenLog.brd, SparkFun_Artemis_OpenLog.sch]
2019-12-19 Add panel files.
    [SparkFun_Artemis_OpenLog-Panel.brd, SparkFun_Artemis_OpenLog.sch]
2019-12-19 Remove old board files
    [SparkFun_Artemis_OpenLog.GBL, SparkFun_Artemis_OpenLog.GBO, SparkFun_Artemis_OpenLog.GBP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]
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2020-01-03 Change RTC battery charging circuit. Fix PNP Qwiic MOSFET.
    [SparkFun_Artemis_OpenLog.brd, SparkFun_Artemis_OpenLog.sch]
2020-01-03 PCB x03 commit for fab.
    [SparkFun_Artemis_OpenLog-Panel.GBL, SparkFun_Artemis_OpenLog-Panel.GBO, SparkFun_Artemis_OpenLog-Panel.GBP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]
2020-01-15 Update PROD_ID on 3.0V supervisor
    [SparkFun_Artemis_OpenLog.brd]
2020-01-20 Move SD power to MOSFET control.
    [SparkFun_Artemis_OpenLog.brd, SparkFun_Artemis_OpenLog.sch]
2020-01-20 Update version mark to x04
    [SparkFun_Artemis_OpenLog.brd, SparkFun_Artemis_OpenLog.sch]
2020-01-28 Add power down interrupt.
    [SparkFun_Artemis_OpenLog.brd, SparkFun_Artemis_OpenLog.sch]
2020-01-28 Fix IMU init. Correctly power down SD if init fails.
    [OpenLog_Artemis.ino]
2020-01-28 Enter low power mode and maintain RTC at ~3.00uA.
    [SparkFun_Artemis_OpenLog.sch]
2020-01-31 Add BME280 and CCS811 support. Refactor TimeStamp menu.
    [SparkFun_Artemis_OpenLog-Panel.GBL, SparkFun_Artemis_OpenLog-Panel.GBO, SparkFun_Artemis_OpenLog-Panel.GBP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]
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2020-04-03 Fix RTC time display in menu. Fix config file parsing.
    [SparkFun_Artemis_OpenLog.brd]
2020-04-06 Add dimension and schematic PDFs. Add readme and issue_template.
    [SparkFun_Artemis_OpenLog.brd, SparkFun_Artemis_OpenLog.sch]
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2020-04-21 Add rtcMillis() calculation. Fix actual read rate output for >2s logging.
    [OpenLog_Artemis.ino, Sensors.ino, lowerPower.ino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]
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2020-04-21 Fix new file create bug.
    The newFileName array was too small. The unit would attempt to find a new file name and then record a much larger file name into the array corrupting the RAM. This was regularly called when the unit was awaking between power cycles and seems to be the main culprit behind the lack of logging in issue #2. It doesn't seem to be related to exFat or variability between cards.
    [logging.ino, lowerPower.ino, nvm.ino]
2020-05-05 Add test sketch for auto-detection methods. Used to detect SCD30 issue #4
    [I2CScanner.ino, I2C_Detector.ino]
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2020-05-05 Update issue template. Change the way firmware version is printed.
    [OpenLog_Artemis.ino]
2020-05-22 First steps towards multi-device detection
    [SparkFun_Artemis_OpenLog.sch]
2020-05-23 Fix maxI2CSpeed to respect node list
    [Sensors.ino, settings.h]
2020-05-25 Support power down between readings. Begin()'s and config now work with muxes.
2020-05-26 Add power up delay setting on Qwiic bus to support VCC settling.
2020-05-26 4 layer PCB, change Qwiic power to vreg, move pwr LED to GPIO, move to SDIO/SPI interface to SD
    Changes from x04 to v10:
    * ICM_PWR moved from 22 to 27
    * SD CS moved from 10 to 23
    * PWR_LED is now GPIO 29
    * VREG_EN is now 25 through NO jumper
    * SD is now SDIO+SPI compatible
    [SparkFun_Artemis_OpenLog-1.sch, SparkFun_Artemis_OpenLog.brd]
2020-05-26 Add pull down to Qwiic vreg
    [SparkFun_Artemis_OpenLog.brd, SparkFun_Artemis_OpenLog.sch]
2020-05-27 Increase VIN and 5V traces to polygon pours on internal layer.
    [SparkFun_Artemis_OpenLog.brd]
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2020-06-17 Updates as per Paul's work diary. Added RST pad and VIN monitor.
    [SparkFun_Artemis_OpenLog-1.sch, SparkFun_Artemis_OpenLog.brd, SparkFun_Artemis_OpenLog.sch]
2020-06-22 Final tweaks. Ready for panelization.
    [SparkFun_Artemis_OpenLog.brd, SparkFun_Artemis_OpenLog.sch]
2020-06-22 Added production files
    [SparkFun_Artemis_OpenLog-Panel.GBL, SparkFun_Artemis_OpenLog-Panel.GBO, SparkFun_Artemis_OpenLog-Panel.GBP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]
2020-06-22 Corrected the links for the MS8607 library
    [OpenLog_Artemis.ino, settings.h]
2020-06-23 Minor SCH tweaks. Replaced the USB-C connector.
    [SparkFun_Artemis_OpenLog-Panel.brd, SparkFun_Artemis_OpenLog.brd, SparkFun_Artemis_OpenLog.sch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]
2020-06-23 Partial fix for the long log interval issue
    This commit fixes the error for long logging intervals (>131072ms).
    But has revealed another problem that the long intervals are not getting saved to SD card correctly (sprintf problem).
    [OpenLog_Artemis.ino, autoDetect.ino, lowerPower.ino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]
2020-06-23 Added a fix for saving usBetweenReadings to SD card
    [OpenLog_Artemis.ino, lowerPower.ino, nvm.ino]
2020-06-24 Added a correction for u-blox setNavigationFrequency
    Previously we would have tried to set a navigation frequency of zero if the logging interval is > 1sec (possibly >2sec). This fix makes sure we don't try to set a navigation rate slower than 1Hz.
    [autoDetect.ino]
2020-06-24 Added a fix so that the MS8607 does not also appear as an MS5637
    [OpenLog_Artemis.ino, menuAttachedDevices.ino]
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2020-06-26 Added menuPower and support for the power LED on V10.
    Also attempted to use the WDT to generate a reset when power is re-connected. Failing at present. The WDT interrupts are being blocked inside the powerDown ISR.
    [OpenLog_Artemis.ino, logging.ino, lowerPower.ino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]
2020-06-28 Added the new WDT reset-on-power-reconnect code.
    Also added support for VIN logging.
    Also added the binaries and UPGRADE.md.
    Updated the README.
    [OpenLog_Artemis.ino, Sensors.ino, autoDetect.ino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]
2020-06-29 V10 PCB tweaks following design review
    [SparkFun_Artemis_OpenLog.brd, SparkFun_Artemis_OpenLog.sch]
2020-06-29 Added revised production files (3x5)
    [SparkFun_Artemis_OpenLog-Panel.brd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]
2020-06-30 Final V10 PCB tweaks!?
    [SparkFun_Artemis_OpenLog-Panel.brd, SparkFun_Artemis_OpenLog.brd, SparkFun_Artemis_OpenLog.sch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]
2020-06-30 Corrections and new features for #18
    [OpenLog_Artemis.ino, Sensors.ino, lowerPower.ino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]
2020-07-02 Corrected the SD logging issue. Added the new log file interval.
    [OpenLog_Artemis.ino, Sensors.ino, logging.ino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]
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2020-07-14 Reverting to standard SdFat. Removed the wakeOnPowerReconnect & WDT functionality.
    [OpenLog_Artemis.ino, Sensors.ino, autoDetect.ino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]
2020-07-18 Added the olaIdentifier and corrected the qwiic pull-ups.
    Pull-ups are now only disabled when talking to a u-blox GNSS.
    [OpenLog_Artemis.ino, Sensors.ino, autoDetect.ino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]
2020-07-31 Changes:
    Added the (6V Max) label for VIN logging.
    Moved useGPIO32ForStopLogging to menuPower.
    Corrected a typo in the IMU menu.
    [menuAnalogLogging.ino, menuIMU.ino, menuPower.ino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]
2020-08-01 Work in progress:
    Added the skeleton of the productionTest however some parts are about to go in the bin as I've just found out that the Apollo3 does not support I2C peripheral mode!
2020-08-03 Changed max serial logging baud rate to 500000.
    Tested serial logging at 460800 and 921600 using u-blox serial data. 460800 works fine but 921600 causes problems... To play safe, I'm limiting the maximum serial logging baud rate to 500000.
    [OpenLog_Artemis.ino, menuSerialLogging.ino]
2020-08-04 Fixing the slippery mux bug
    [autoDetect.ino, menuAttachedDevices.ino]
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2020-08-05 Added extra writes when beginning a multiplexer for the first time:
    to avoid the slippery mux problem. Not sure why it works, but it seems to do the trick!
    [OpenLog_Artemis.ino, Sensors.ino, autoDetect.ino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]
2020-08-10 Make I2C scanner work on new v10 hardware. Add delay for devices, ublox needs ~1s to ack.
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2020-08-10 Hardcode 1s bootup delay to allow for Ublox modules to detect on bus
    Ublox ZED-F9P module was failing to detect. Using SparkX brand SD card causes the OLA to startup *too* fast (go cheap SD!). I don't like blocking for 1s at startup but I don't know of a more elegant solution.
    [menuAttachedDevices.ino]
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2020-08-10 Remove multiplexer testing from testDevice
    This is should be done by dedicated testMuxDevice. I found that this test was interfering and failing the SHTC3 test (SHTC3 falsely tested OK as a mux).
    [autoDetect.ino]
2020-08-11 Making board and sch consistant.
    [SparkFun_Artemis_OpenLog.brd, SparkFun_Artemis_OpenLog.sch]
2020-08-11 Change R1 to 2.2k
    [SparkFun_Artemis_OpenLog.brd, SparkFun_Artemis_OpenLog.sch]
2020-08-13 Move up initial power on of Qwiic bus.
    There are a few configurations (no SD card, fast SD card with few files) where OLA powers up the GPS module but fails to detect it because the GPS module needs more time (around 1s) after power on. This moves the Qwiic power up before SD, IMU, etc.
    [OpenLog_Artemis.ino, menuAttachedDevices.ino]
2020-08-13 Change error message to debug enablable
    [autoDetect.ino]
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2020-08-13 Add var to track point in time when Qwiic was powered up
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2020-09-03 Fixed the IMU startup-after-sleep problem. Added CAT/TYPE to the SD file menu.
    [OpenLog_Artemis.ino, Sensors.ino, autoDetect.ino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]
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2020-09-04 Added qwiic bus power up delays for each sensor type
    Each sensor struct now contains a powerOnDelayMillis.
    qwiicPowerOnDelayMillis is set to the _higher_ of settings.qwiicBusPowerUpDelayMs or the highest power on delay depending on what sensors are attached.
    The minimum value for settings.qwiicBusPowerUpDelayMs is minimumQwiicPowerOnDelay.
2020-09-04 Increased the max qwiic power on delay to 60s so a ZED-F9P has time to do a warm start
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2020-09-16 Added a fix for issue #39
    [OpenLog_Artemis.ino, lowerPower.ino]
2020-10-08 Restructuring detectQwiicDevices so that the MCP9600 is detected correctly
    [autoDetect.ino, menuAttachedDevices.ino]
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2020-10-13 User can now configure the IMU full scale and filter bandwidth from Menu 3
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2020-11-27 Adding a fix to make sure the MS8607 is detected correctly.
    [OpenLog_Artemis.ino, autoDetect.ino, menuAttachedDevices.ino]
2020-12-01 Revert "Adding support for the BNO080 - ** work in progress ** (does not .begin reliably)"
    This reverts commit cdaf6afa03d717202459b980fb657dd0dfe09e62.
    [OpenLog_Artemis.ino, Sensors.ino, autoDetect.ino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]
2020-12-06 Correcting the magnetometer typo
    [menuIMU.ino]
2021-01-29 Adding the timestamp feature as described in PR #70 and Issue #63. Deleted settings.getRTCfromGPS
    [OpenLog_Artemis.ino, Sensors.ino, menuSerialLogging.ino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]
2021-01-29 Adding "sleep on pin" and "wake at specified time" functionality
    These changes are based on code by @ryanneve in PR #64 and suggestions in Issue #46
    [OpenLog_Artemis.ino, lowerPower.ino, menuTerminal.ino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]
2021-01-29 Update OpenLog_Artemis-V10-v19_BETA.bin
    The new version of v1.9 BETA contains partially-tested code:
    - Corrected an issue when using multiple MS8607's: https://github.com/sparkfun/OpenLog_Artemis/issues/62
    - Add a feature to use the TX and RX pins as a duplicate Terminal
    - Add serial log timestamps with a token (as suggested by @DennisMelamed in PR https://github.com/sparkfun/OpenLog_Artemis/pull/70 and Issue https://github.com/sparkfun/OpenLog_Artemis/issues/63)
    - Add "sleep on pin" functionality based @ryanneve's PR https://github.com/sparkfun/OpenLog_Artemis/pull/64 and Issue https://github.com/sparkfun/OpenLog_Artemis/issues/46
    - Add "wake at specified times" functionality based on Issue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
2021-01-30 Correcting logHertz. Slow logging start and end times now entered as hour and minute - not minute-of-day.
    [OpenLog_Artemis.ino, Sensors.ino, menuMain.ino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]
2021-01-30 Update OpenLog_Artemis-V10-v19_BETA.bin
    v1.9 BETA now includes msToSleep adjustment for the RTC case
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2021-02-02 Alow user to open menuMain on startup to disable resetOnZeroDeviceCount
    [OpenLog_Artemis.ino]
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2021-03-09 SDP3X corrections - need to use continuous measurements
    [OpenLog_Artemis.ino, Sensors.ino, autoDetect.ino]
2021-03-23 Correcting SDP31 continuous measurements
    [autoDetect.ino, settings.h]
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2021-04-26 Add IMU DMP Multiple Sensors example - requires v1.2.5 of the ICM20948 library
2021-05-28 minimumAwakeTimeMillis improvements. Fix an old bug in msBeenAwake
    [OpenLog_Artemis.ino, lowerPower.ino, menuTerminal.ino]
2021-05-29 Adding support for the pulse oximeter and Qwiic button - requires testing
2021-05-31 Functional but not working correctly. On hold until printf float is available.
    [OpenLog_Artemis.ino, lowerPower.ino, menuAnalogLogging.ino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]
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2021-07-07 Fix goToSleep. Increase DMP resolution. Add bestMillis(). Add comma after olaftoa values.
    With v2.1 of the core, both millis and micros are corrupted when coming out of deep sleep. bestMillis will use the RTC to generate the milliseconds.
    [OpenLog_Artemis.ino, Sensors.ino, lowerPower.ino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]
2021-07-08 Add configureSerial1TxRx. Improvements to the sleep current - disable SPI and qwiic pins.
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2021-07-15 Corrections for Qwiic bus speed (100kHz and 400kHz). Ensure interrupt directions are set correctly.
    [OpenLog_Artemis.ino, Sensors.ino, autoDetect.ino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]
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2021-12-14 Add BME280 test to correct issue #109
    [OpenLog_Artemis.ino, autoDetect.ino, menuAttachedDevices.ino]
2021-12-14 Delete settings.enableSD - see issue #104
    enableSD is redundant. If the microSD card is present, it needs to be powered up. Otherwise it will pull the SPI lines low, preventing the IMU from starting.
    [OpenLog_Artemis.ino, Sensors.ino, menuMain.ino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]
2022-03-31 Add support for yyyy/mm/dd and ISO 8601 date. Add fix for Serial.end.
    Add support for missing / not-populated IMU.
    Note: we're not out of the woods yet... The IMU is not restarting after sleep. More changes to follow!
    [OpenLog_Artemis.ino, Sensors.ino, lowerPower.ino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]
2022-03-31 Correct save of localUTCOffset
    [OpenLog_Artemis.ino, nvm.ino]
2022-04-04 Correct Serial start up after deep sleep
    [OpenLog_Artemis.ino, lowerPower.ino]
2022-04-07 Correct ublox spelling. Update production test. Add X04 BETA binary.
    [Sensors.ino, autoDetect.ino, menuAttachedDevices.ino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]
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2022-08-16 Cause Artemis to reset if battery is low and NoPowerLossProtection is enabled
    [lowerPower.ino]
2022-08-18 minor refactor of header output logic, added header output token for serial output, removed print of header to serial on file change, moved strcat to strlcat
2023-01-10 Adds reboot option to debug menu
    [menuDebug.ino]
2023-01-13 Undo log file reset feature
    [OpenLog_Artemis.ino, menuDebug.ino, menuMain.ino]
2023-02-06 Only disable I2C SDA and SCL during sleep when I2C bus is being powered down.
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2023-10-25 Corrected original ICM20948 path, whitespace
    [autoDetect.ino]
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2024-02-22 Fix nvm calibrationWeight
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2024-02-22 NAU7802 improvements - skip calibrateAFE on begin
    [autoDetect.ino, menuAttachedDevices.ino, nvm.ino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]
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2024-02-26 Fix minor bug : pass correct array size to olaftoa
    [Sensors.ino]
2024-02-26 Fix major bug : configure Mux when changing settings of NAU7802, SCD30 or u-blox GNSS
    [menuAttachedDevices.ino]
2024-03-07 v2.8 BETA - to resolve #192
    [OpenLog_Artemis.ino]
2024-08-09 Replace SdFile with File32/ExFile/FsFile/File as needed
    [logging.ino, nvm.ino, productionTest.ino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]
2024-09-14 Added support for the TMP102 sensor. Unfortunately, this will almost certainly cause the ADS1015 chip to be incorrectly detected and treated as a TMP102 sensor. Ideally I'll find a way to distinguish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
2024-09-22 Added support for differentating between the ADS1015 ADC chip vs the TMP102 temperature sensor based upon the R0/R1 configuration bits in the TMP102 which are locked read only to 11, while the same b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
2024-11-08 Added a printout of the Mux address, Mux Port, and Device address in the "Help text" for the TMP102 temp sensor. This allows setups with multiple TMP102 devices on multiple busses to disambiguate bet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
    [Sensors.ino]
2025-02-06 Add DEL * / RM * to resolve #211
    [zmodem.ino]
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

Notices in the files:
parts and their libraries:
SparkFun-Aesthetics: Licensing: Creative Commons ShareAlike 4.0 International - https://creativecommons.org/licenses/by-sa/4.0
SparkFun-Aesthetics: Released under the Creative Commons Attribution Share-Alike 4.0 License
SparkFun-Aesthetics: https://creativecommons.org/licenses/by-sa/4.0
